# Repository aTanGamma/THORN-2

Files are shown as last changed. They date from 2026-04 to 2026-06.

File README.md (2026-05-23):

# aTan's THORN-2 RISC-V CPU Project

## What?

This is an implementation of the RISC-V spec using nothing but basic logic and
memory elements. 

The project has been inspired by several similar projects, most
notably [Robert Baruch's LMARV-1](https://www.youtube.com/playlist?list=PLEeZWGE3PwbansoxKjjMKHQqS_2cm8i60),
[James Sharman's JAM-1](https://www.youtube.com/playlist?list=PLFhc0MFC8MiCDOh3cGFji3qQfXziB9yOw)
and [Fabian Schuiki's Superscalar CPU](https://www.youtube.com/playlist?list=PLyR4neQXqQo5nPdEiMbaEJxWiy_UuyNN4).

As of May '26 I'm looking to implement the RV64I spec, with vague plans to 
extend this with the M and maybe F modules. I don't have any timeframe for that
though.

## Why?

IDK. It's fun :)

## That's mental... Where can I see the details?

If you go to `Docs/Writeup/` you can see a proper typewritten rundown on how
everything works and my "design process". There's quite a bit of techy stuff
there, and it's not _guaranteed_ to make sense - it's mostly a document to help
me keep track of what I'm doing between each section.

## Where are the schematics?

See `Schematics/`. This will be spotty for a while yet.

## Can I do anything with this project?

Please do! Though do read the license first. Broadly speaking, keep everything
open-source and don't be evil :)

## What happened to the THORN-1?

¬_¬ it went wrong...

In reality, it was the same as this project, but massively overcomplicated and
everything I learned there helped make this version much simpler. T1 used
pipelined ram for the registers, leading to a 4-phase clock and massive pain in
the ALU, so I abandoned it to start over.

-aTan 2026

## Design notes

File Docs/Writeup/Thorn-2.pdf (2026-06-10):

## THORN-2 Technical Referance Manual

aTan

May 30, 2026

Abstract

This document is a technical reference for the Thorn-2 (Stylised: Þ-2) computer. The Þ-2 is an RV64i compatable CPU and supporting system created largely from 74-series logic ships, with the goal of making a fully-pipelined system capable of very-high-speed execution. It also serves as a proof of [in]sanity for the creator.

1

### Contents

1 Introduction | 1
1.1 Pipelining | | 1
1.1.1 | Why and How Þ-2 Differs From Classic RISC | | 1
1.2 Hazard Avoidance | | 2
1.2.1 | Adding Stalls | | 2
1.2.2 | Operand Forwarding | | 3
2 Program Counter | 4
3 Decode Logic | 4
4 Immediate Value Generator | 4
5 Registers | | | 4
5.1 Theory of Operation | | 5
5.1.1 | Write Phase, φ1 | | | 5
5.1.2 | Read Phase: φ2 | | 6
5.1.3 | Output Buffers | | 7
5.2 Control Logic | | 8
6 ALU | | | 8
6.1 Adder | | 9
6.1.1 | Method | | 9
6.1.2 | Modified Carry-Lookahead | 10
6.1.3 | Doing the Adding | 11
6.1.4 | Condition Checking | 12
6.2 Logicer | 13
6.2.1 | Logic from MUXs | 14
6.2.2 | Setting up the MUX | 15
6.3 Shifter | 16
6.3.1 | Bit Order Reverser | 16
6.3.2 | Shift Stages | 16
References | | | 17
A Various Logic Expansions and Definitions | 18
A.1 Adder Conditions | 18

### List of Figures

1 | Execution flow through a pipelined ALU. In refers to line
number in code listing | | 4
2 | The Thorn-2 register file | | 6
| | i

3 | Register file timing diagram | | 7
4 | Layout of the adder circuit. Logic shared between similar
| signals combined for space | | 9
5 | Simplified overview of the adder logic | 10
6 | Diagram of the Logicer | 13
7 | Wiring of a 4:1 mux as used in the logic section | 14
8 | Diode ROM storing the truth table function, F0, F1, F2, F3;
| these are pulled up as the outputs of a 74x139 are active low. | 15

### List of Tables

1 | RISC-V calling convention | | 5
2 | Register Card control signal definitions | | 8
3 | Contents of the Condition RAM | 11
4 | Contents of the Carry RAM | 12
5 | ALU adder EEPROM contents | 12
6 | Formulae for ALU result conditons | 13
7 | Truth tables of the three defined logic operations | 14
8 | Comparison of the number of components used in designs
with (a) separate logic paths and (b) MUX-based logic . . . . 15

### Listings

1 | Some example code which denerates lots of stalls | | 2

ii

### 1 Introduction

Thorn-2 is a RISC-V CPU, designed to be fully compatable with the RV64i (integer only) standard module as defined in the RISC-V Instruction Set Architecture (RV-ISA) specification [1]. It is a fully-pipelined design with 5parallel stages (see §Pipelining) with hazard avoidance (§Hazard Avoidance) and operand forwarding (§Operand Forwarding).
This project has some fairly nebulous goals, but the general idea is to learn how CPUs work internally and make something interesting. They are here itemised:
- Implement a RISC-V CPU
- Utilise as few non-74 series chips as possible (no FPGA)
- Design the circuitry "by hand"
- Achieve ~40 MHz operation
- Have fun :3

Please don’t tell me I’m doing this inefficiently or that there article better ways to implement things - I’m well aware.

### 1.1 Pipelining

### 1.1.1 Why and How Þ-2 Differs From Classic RISC

The pipeline structure of Þ-2 differs from the traditional RISC one in that there are several more stages. These can be grouped into largely the same functional blocks, but spread across more stages; a setup reached after much design work on Thorn-1.
Classic RISC is split into five stages: Fetch, Decode, Execute, Memory and Writeback; with every instruction passing through each stage in turn (with the correct options set). In implementing this, I decided to use SRAM to store the 32 registers and to avoid using asynchronous SRAM. The latter decision was based on the false assumption that this would make the control circuitry easier to design and less error-prone. I maintained the Synchronous SRAM design for quite a while, getting as far as designing the whole control circuit for the registers and starting work on the ALU, but ran into problems with timings.
The SRAM ic I had chosen - IS61NLP6432a [2] - were themselves pipelined at three stages: Assert, wait, Read/Write. Each cycle of the CPU required three register accesses (two reads and a write), which was possible to achieve if each cycle was split into four phases, φ0, φ1, φ2, φ3. This imposed the requirement that every pipeline stage in the CPU must take

1

1 | ; Some silly code | :3c
2 | add a0 , a1 , a2 | ; Use a0 as tally
3 | add a0 , a0 , a3
4 | add a0 , a0 , a4
5 | add a0 , a0 , a5 | ; Add lots of numbers in turn
6 | ; ...

Listing 1: Some example code which denerates lots of stalls.

four cycles, which was insufficient for the ALU to perform a 64-bit addition and perform conditional inversion of the second operand for subtraction and check conditions. Thus, I decided to go back to the drawing board and start again.
The current design of Þ-2’s pipeline is based around the ALU, rather than the registers. I needed four stages to add numbers, plus two more to condition the inputs and outputs, giving six. Register accesses can be done in one step by using two copies of each register (a poor-man’s dual-port RAM) which are written to simultaniously on the rising edge of the clock; then separately read on the falling edge. Now using fast, asynchronous SRAM instead.

### 1.2 Hazard Avoidance

In a pipelined system, there are frequently situations where one instruction depends on the result of its predecessor. In such a case, this results in a Data Hazard - what is contained in register X is out of date, and reading this will produce incorrect results.
Another hazard comes in the case that a conditional branch is dependent on the outcome of a previous operation, resulting in a Control Hazard. The CPU must either stall new instructions while the condition is evaluated, or speculatively execute code for either the "branch" or "no branch" condition and throw it out if needed.

### 1.2.1 Adding Stalls

In either hazard case, the simplest - albeit least efficient - solution is to inject NO-OPs (NOPs) after the Decode stage and only continue when there are no remaining hazards. It is, however, trivial to come up with example programs which result in more nops than executed instructions:
When executing the above program, the CPU is forced to insert NOPs between every instruction to allow the addition result to be fully written back to a0 before the next instruction is executed. A classic RISC-V architecture with this simple hazard avoidance would actually execute the code in Listing 2.

2

7 | ;Oops , all stalls | TwT
8 | add a0 , a1 , a2 | ; Use a0 as tally
9 | nop | ; Execute in ALU
10 | nop | ; Skip memory access
11 | nop | ; Write result to a0
12 | add a0 , a0 , a3 | ; Next ADD is allowed to continue
13 | nop
14 | nop
15 | nop
16 | add a0 , a0 , a4
17 | nop | ; Each nop represents
18 | nop | ; | 1 stall cycle
19 | nop
20 | add a0 , a0 , a5 | ; Add lots of numbers in turn
21 | ; ...

Listing 2: Worst case scenario for consecutive adds.

This effectively quarters the useful throughput of the CPU in the worst case, though most of the time this isn’t likely to occur. Using this method, the number of NOPs scales linearly with the number of stages in the pipeline, so there is strong incentive to use a better system. Such a system should be able to feed data from one stage to another in order to skip some of the waiting.

### 1.2.2 Operand Forwarding

Operand Forwarding is one way to reduce the number of stall cycles introduced with a pipelined system. Here, in the case that an instruction needs data which has not yet been written to a register, but is available within the pipeline, that data can be fed forwards early so fewer stalls need to be introduced.
This method becomes very important the longer a pipeline becomes due to a greater number of cycles before the completion of each instruction: there is greater chance that a following instruction is dependent on a previous one and that data takes longer to become available.
Assuming the same code snipped as in §Adding Stalls, a perfect system of operand forwarding could reduce the number of NOPs to zero - i.e. what is written is executed exactly.
In Thorn-2 however, there is an additional complication which arises from the use of a pipelined ALU: the final result is made available in chunks across multiple stages or, should conditions need evaluation, only available after the final stage.
In fig. 1, each of the Add stages performs a 16-bit addition of each int16 chunk of the 64-bit inputs. If operand forwarding were to be used, the output

3

Invert? | Add 1 | Add 2 | Add 3 | Add 4 | Cond.
I2
I3 | I2
I4 | I3 | I2
I5 | I4 | I3 | I2
| I5 | I4 | I3 | I2
| | I5 | I4 | I3 | I2
| | | I5 | I4 | I3
| | | | I5 | I4
| | | | | I5

Figure 1: Execution flow through a pipelined ALU. In refers to line number in code listing.

of Add 1 would need to be fed back to its inputs for the next instruction. The same would be needed for each subsequent stage too. See §ALU for how this is actually done.

### 2 Program Counter

The PC’s job is (generally) to increment by 4 every clock cycle to fetch the next instruction in memory. On occasion, it will need to stall in place, load a provided value, or add a constant to its previous value to branch.
While outwardly simple, this is fairly complex to actually implement in 64 bits, expecially the branch operation which requires a 12-bit add, then a carry to propagate up the remaining bits. Since there could realistically be any arbitrary sequence of branches, jumps, normal increments or stalls, all of the separate branches need to be done in parallel and selected from at the very end.

### 3 Decode Logic

### 4 Immediate Value Generator

### 5 Registers

RV64i specifies 32 64-bit general-purpose registers and a program counter, PC. x0 is hard-wired to 0x0000 0000 0000 0000; there is no stack pointer. None of the registers are otherwise special, but do have expected uses as per the calling convention [3], shown in table 1.
As each register is effectively the same, they are most easily implemented using SRAM. Learning from Thorn-1, I have decided to use the

4

Table 1: RISC-V calling convention

Register | ABI
| Mnemonic | Meaning | Preserved across
| | | calls?
x0 | zero | Zero | — (Immutable)
x1 | ra | Return address | No
x2 | sp | Stack Pointer | Yes
x3 | gp | Global Pointer | — (Unallocatable)
x4 | tp | Thread Pointer | — (Unallocatable)
x5-7 | t0-2 | Temp. Registers | No
x8-9 | s0-s1 | Callee-saved regs. | Yes
x10-17 | a0-7 | Argument registers | No
x18-27 | s2-11 | Callee-saved regs. | Yes
x28-31 | t3-6 | Temp. Registers | No

IS61WV6416DBLL-10TLI-TR[4]; it’s a 64k x 16-bit asynchronous SRAM with a 10 ns access time and single 3.3 V supply.

### 5.1 Theory of Operation

For every RV64i operation, there are up to two operands, meaning up to two registers may be read each cycle. There may also be a value written into a register. To avoid using multiport RAM, two copies of the registers are needed: x and y; these two are both written to and read from at the same time. The IS61WV6416 is 16-bit, so there are two sets of four RAM chips total.
Both access to X and Y (Read/Write) occur within one cycle; writes are completed on the rising edge, φ1; and reads on the falling edge, φ2. This order of operations means the register card doesn’t need to latch its input, WB_DATA, or outputs, REG_OUT1 and REG_OUT2.
For the purposes of explanation, both RAM banks will be collectively referred to as "R". The logic is otherwise identical between X and Y, so either could be inserted in R’s place.

### 5.1.1 Write Phase, φ1

Register writes occur on the rising edge of the clock, φ1, and are controlled only by the external WRT signal. Regardless of whether a value is to be written to a register, the address for that ’write’ is selected. This setup helps to minimise control circuitry.

Write Enabled, WRT = 1 When WRT is high, WE goes low and puts the IS61WV6416 into a write cycle. R_BUS is driven to the value on

5

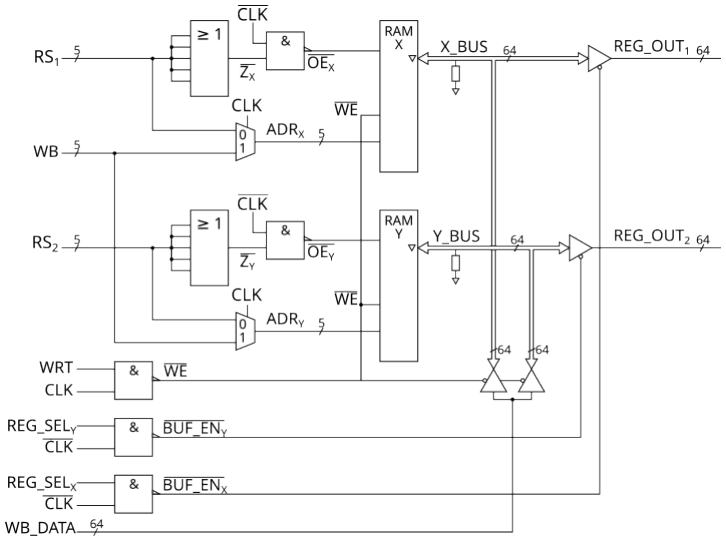
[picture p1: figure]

Figure 2: The Thorn-2 register file.

WB_DATA which is written into the selected register.

Write Disabled, WRT = 0 When WRT is low, WE remains high and the IS61WV6416s have their output disabled via OER. R_BUS is then passively pulled down to a value of 0x0000 0000 0000 0000.

### 5.1.2 Read Phase: φ2

Reads occur on the falling edge of the clock, φ2, and may give a real register value or a zero depending on the read address (see below). Regardless of whether an IS61WV6416s is actually read from, its address lines, ADRR, are set as if it was.

Not Reading From ’zero’, RSR 6= 0 When reading from any register other than x0, ZR will be high, setting OER low during φ2. R_BUS is thus driven to the contents of xR.

Reading From ’zero’, RSR = 0 When reading from x0, ZR goes low and, during φ2, OER stays high, again leaving R_BUS to be passively pulled to 0x0000 0000 0000 0000

6

### 5.1.3 Output Buffers

Since Þ-2 will be implementing operand forwarding, there are some instances where the input to the ALU isn’t necessarily from the register file. Therefore, the register file needs to be "selectable" by the CPU control logic. As such, the outputs of this section, REG_OUT1 and REG_OUT2 are connected to their respective buses via tri-state buffers.

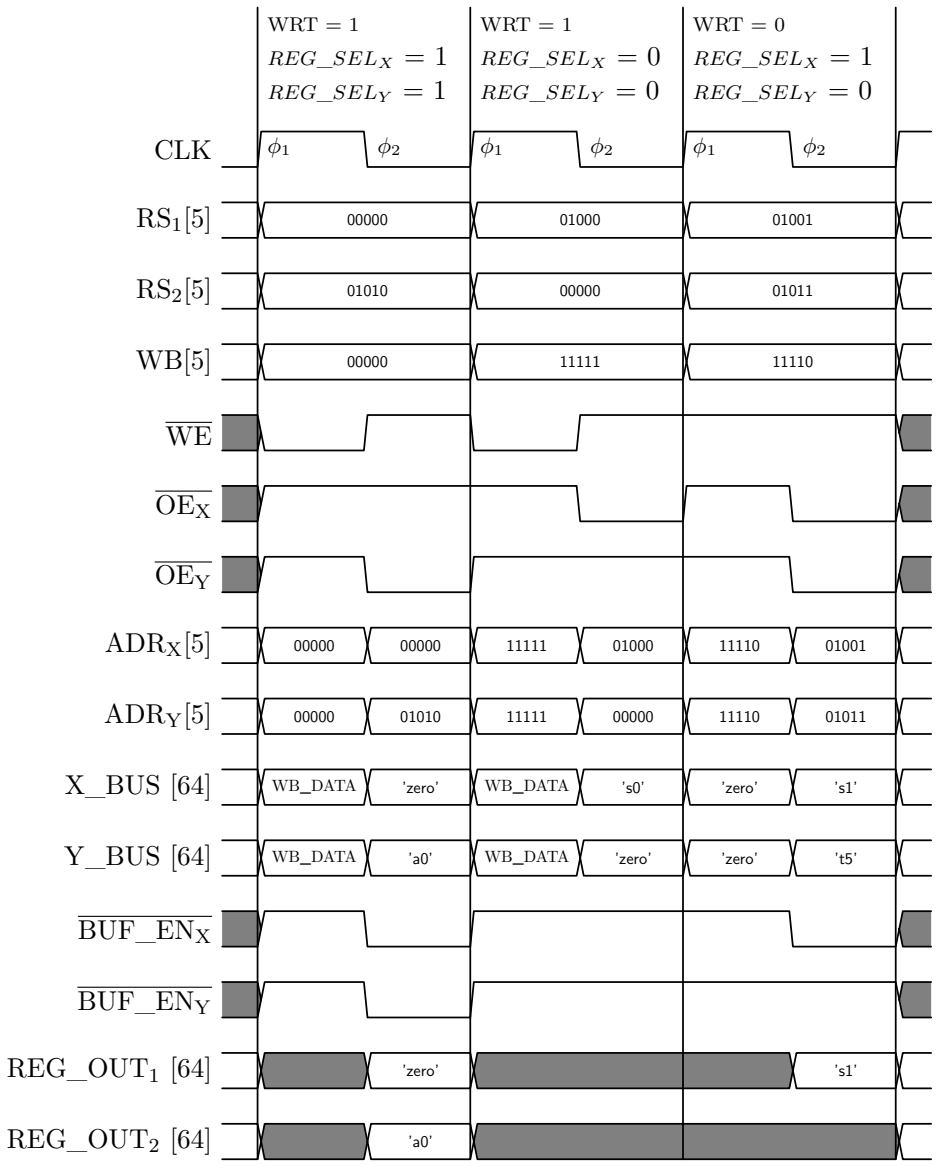
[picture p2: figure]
CLK; OEX; OEY; ADRX[5]; ADRY[5]; X_BUS [64]; WB_DATA; ’zero’; Y_BUS [64]; BUF_ENX; BUF_ENY; REG_OUT1 [64]; REG_OUT2 [64]; WRT = 1; REG_SELX = 1; REG_SELY = 1; REG_SELX = 0; REG_SELY = 0; WRT = 0

Figure 3: Register file timing diagram.

7

### 5.2 Control Logic

Figure 2 shows an overview of the register file. The control signals present are described in table 2.

Table 2: Register Card control signal definitions.

Signal | Equation | Explanation
CLK | — | Clock input
RS1 | — | Read address 1
RS2 | — | Read address 2
WB | — | Write address
WRT | — | Write enable
REG_SEL1 | — | Output X_BUS
REG_SEL2 | — | Output Y_BUS
WB_DATA — | Data to write this cycle

ZX

P4
| i=0 (RS1,i) | Not reading from ’zero’

ZY

P4
| i=0 (RS2,i)
OEX | ZX · CLK | RAM output enable
OEY | ZY · CLK
WE | CLK · WRT | Write enable signal
REG_OUT1 CLK · REG_SEL1 | Enable output to ALU

REG_OUT2 CLK · REG_SEL2

### 6 ALU

The Thorn-2ALU is comprised of three blocks - the Adder, Shifter and Logicer. The Adder computes A ± B; the Shifter shifts A up or down by n bits; and the Logic-er performs the bitwise logic operations A·B, A+B and A⊕B. The 64-bit values A and B may be read from registers or immediate values derived from an instruction. Each of the three blocks are contained on separate circuit boards, and run in parallel. Their outputs are calculated for all inputs with the relevant one forwarded to the next pipeline stage.

8

### 6.1 Adder

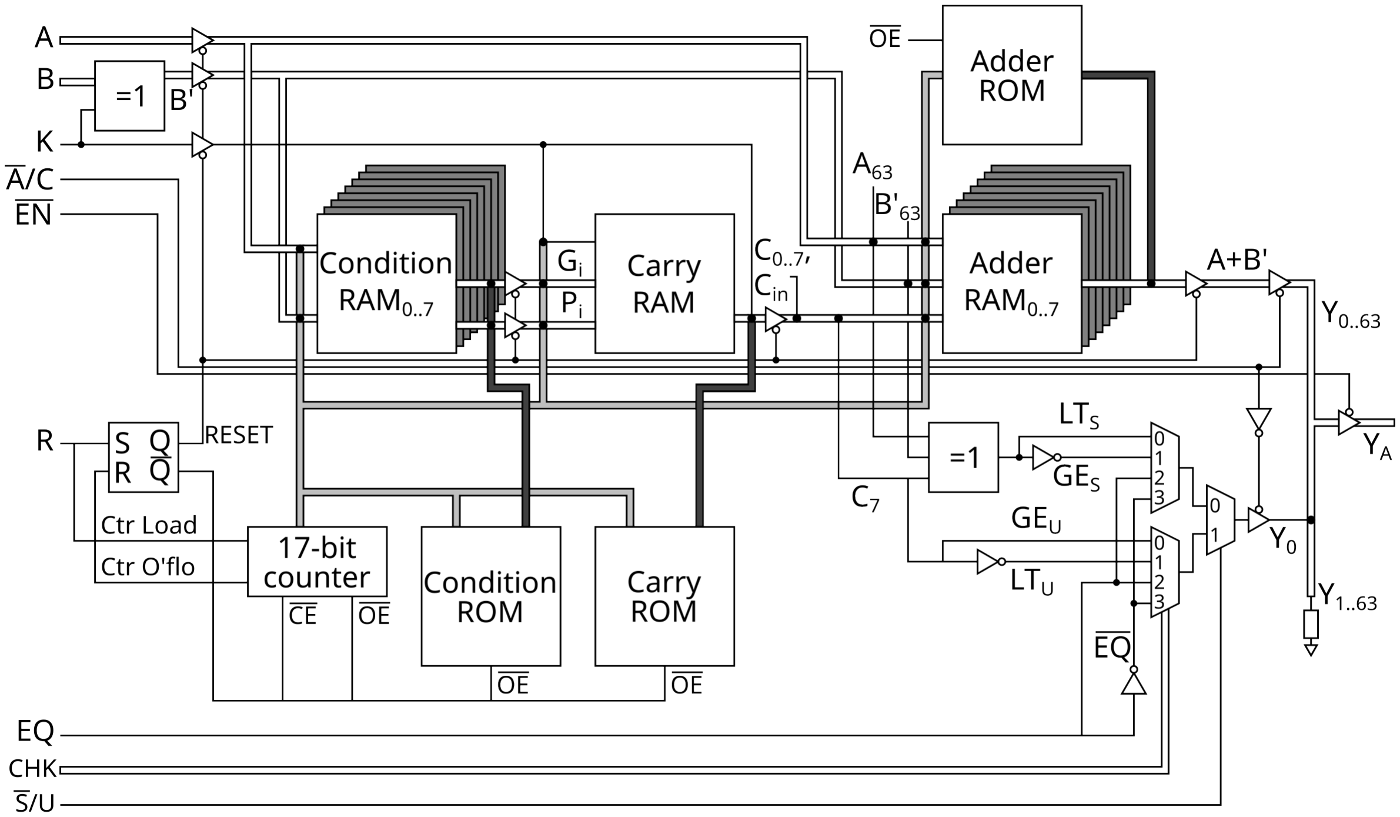
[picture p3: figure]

Figure 4: Layout of the adder circuit. Logic shared between similar signals combined for space.

The adder computes A±B and optionally checks the result against each of the "flags" for the calculation: A < B, A = B and A ≥ B. In Þ-1, this procedure was to be pipelined at up to six stages, but resulted in both huge pipelines and complications in feeding partial results back to previous stages, possibly from multiple instructions at multiple different points in their execution. In Þ-2, however, the entire ALU instead operates in one cycle - the length of this defining the overall cycle length of the CPU.
As you can see from fig. 4, the adder remains one of the most complex parts of the CPU, despite being only a third of the ALU. Using RAM with ~8 ns access time, this section has a critical path of ~50 ns through the zero check logic. This is markedly better than a more brute-force approach, though still limits the maximum clock frequency of ~20 MHz.

### 6.1.1 Method

Addition and subtraction are both done with the same circuitry, with a preconditioning step for the second input, B. Using 2’s compliment to represent negative numbers, an n-bit number, x, can be negated by inverting its bits and adding 1:

−x := (x ⊕ [2n − 1]) + 1 | (1)

9

Subtracting B from A is therefore defined:

A − B ≡ A + (−B) ≡ A + (B ⊕ [2n − 1]) + 1 | (2)

Equation (2) is implemented by bitwise XORing B with the ADD/SUB setting, K , and setting the carry input, Cin to the same:

K =

(
0 if Adding
1 if Subtracting

(3)

A − B ≡ A + (B ⊕ K) + K | (4)

The XORed B will be called B⁰
from here.
The addition, A + B⁰ + K is a 64-bit operation which would be much too slow if performed as a series of daisy-chained segments due to the access time of the RAM ICs. Even in the best case - where the access time were ≤ 8 ns - a chain of eight in a row would be a total delay of ≤ 64 ns, greatly bottlenecking the speed of the processor. A form of carry-lookahead is therefore used to reduce this delay.

### 6.1.2 Modified Carry-Lookahead

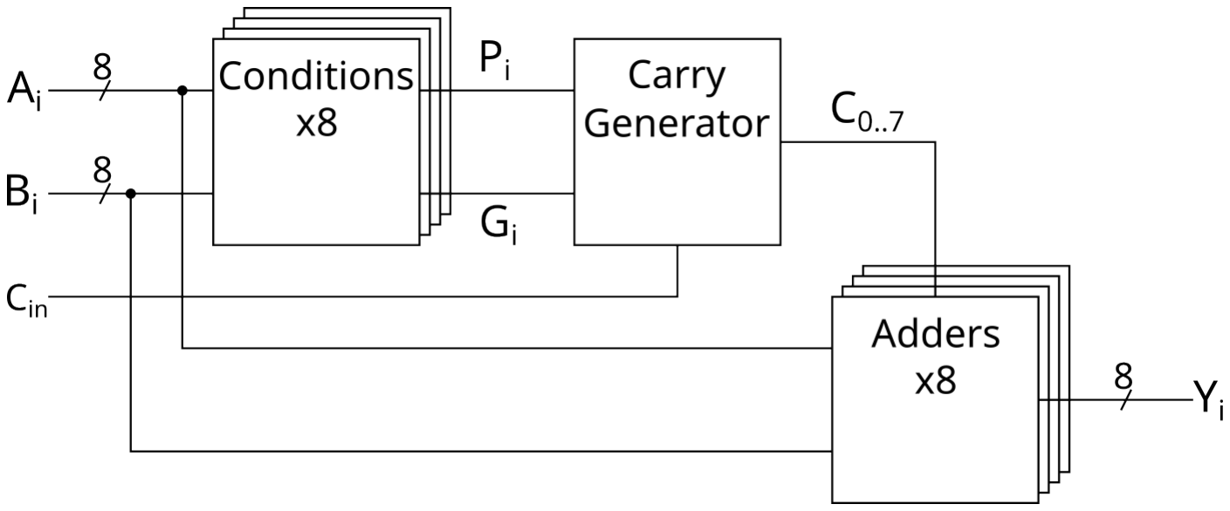
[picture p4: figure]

Figure 5: Simplified overview of the adder logic.

A traditional carry-lookahead circuit generates the carry signals from chunks of the inputs, ideally much faster than the same signal would be propagated up a chain of full adders. To do this, additional signals are generated or tapped from the full adder circuits:

Xn = An · Bn | (5)
Sn = An ⊕ Bn | (6)

10

These additional signals are then used to calculate whether the n-bit chunk generates, G, or propagates, P, a carry.

G = (Xn) + (Xn−1 · Sn) + · · · +

X0 ·

Yn

i=1

(Si)

!
(7)

P =

Yn

i=0

(Si) | (8)

A single 64Kx8 RAM chip is used as a lookup table for G and P, both of which are forwarded to another 128Kx8 RAM that generates the carry signals C0..7.
For n = 0:
C0 = G0 + Cin · P0 | (9)

For 1 ≤ n < 8:

Cn = Gn +

Xn

i=1

Gn−i

·

Y

i−1

j=0

(Pn−j )

- + Cin ·

Y

N

(Pn) | (10)

See §Adder Conditions for expanded definitions.
Using this method, all eight carrys can be generated after only two RAM accesses. Cin and C0..6 are used in the calculation while C7 is used only for condition checking.

Table 3: Contents of the Condition RAM

An | Bn | Address | Gn | Pn
0x00 | 0x00 | 0x0000 | 0 | 0
0x00 | 0x01 | 0x0001 | 0 | 0
0x00 | 0xFF | 0x00FF | 0 | 1
0x01 | 0x00 | 0x0100 | 0 | 0
0x01 | 0xFE | 0x01FE | 0 | 1
0x01 | 0xFF | 0x01FF | 1 | 0
0xFF | 0xFF | 0xFFFF | 1 | 0

### 6.1.3 Doing the Adding

The addition itself is "executed" in eight 128Kx8 RAM chips, each programmed at start-up from a single 128Kx8 EEPROM. The RAM is ad-

11

Table 4: Contents of the Carry RAM

Gn | Pn | Cin | Address | C
00000000 | 00000000 | 0 | 0x00000 | 00000000
00000000 | 00000001 | 0 | 0x00001 | 00000000
00000000 | 11111111 | 0 | 0x000FF | 00000000
00000001 | 00000000 | 0 | 0x00100 | 00000001
00000001 | 00000001 | 0 | 0x00101 | 00000001
00000001 | 00000010 | 0 | 0x00102 | 00000011
11111111 | 11111111 | 0 | 0x0FFFF | 11111111
00000000 | 00000000 | 1 | 0x10000 | 00000000
00000000 | 00000001 | 1 | 0x10001 | 00000001
11111111 | 11111111 | 1 | 0x1FFFF | 11111111

dressed by each byte of the two inputs, An and Bn, and Cn, which points to the result, Yn.

Table 5: ALU adder EEPROM contents

An | Bn | Cn | Address | Yn
0x00 | 0x00 | 0 | 0x00000 | 0x00
0x00 | 0x01 | 0 | 0x00001 | 0x01
0x01 | 0x00 | 0 | 0x00100 | 0x01
0x00 | 0x00 | 1 | 0x10000 | 0x01
0xFF | 0xFE | 1 | 0x1FFFE | 0xFE
0xFF | 0xFF | 1 | 0x1FFFF | 0xFF

The final result is then either forwarded to the Adder’s output, or changed to 0/1 for the outcome of the SLT/SLTU instructions.
In the case of ADDW/SUBW instructions which sign-extend a 32-bit answer to 64, the upper word is ignored and switched to Y[31].

### 6.1.4 Condition Checking

The RISC-V ALU needs to be able to check for three conditions for both signed and unsigned numbers: A < B, A = B and A ≥ B. These are only

12 valid if the calculation A − B was performed. These checks can be performed immediately after the final carry out has been calculated using the equations in table 6.

Table 6: Formulae for ALU result conditons

Condition | Name | Signed | Unsigned
A < B | LT | A63 ⊕ B63 ⊕ C7 | C7
A = B | EQ | Y = 0 | Y = 0
A ≥ B | GE | A < BS | C7

The greater/less than checks are calculated as written, but the equality check is actually calculated using the formula:

EQ =

X

63

i=0

(Ai ⊕ Bi) | (11)

In plain english: A and B are equal if A ⊕ B = 0, which is checked in the Logicer by ORing together all the bits of that result.
The results of the condition check are also forwarded to the program counter to deal with branches.

### 6.2 Logicer

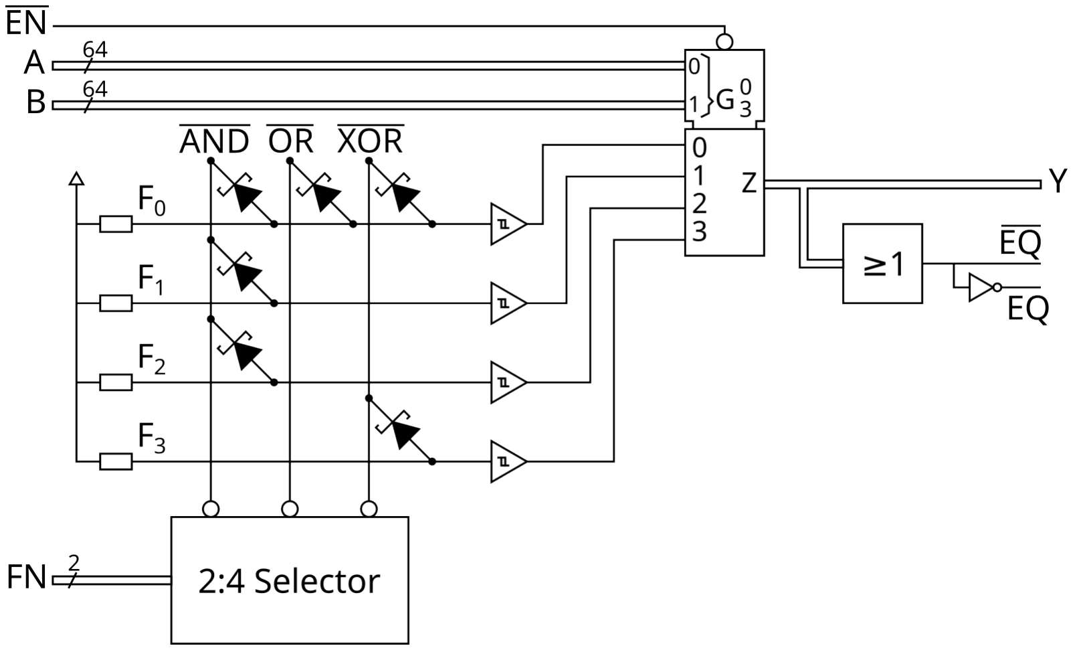
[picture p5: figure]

Figure 6: Diagram of the Logicer.

13

RISC-V specifies three bitwise logic operations: AND, OR and XOR. The obvious way to do this (74x08 for AND, 74x32 for OR, and 74x86 for XOR), takes 48 chips, plus some extra to choose which answer we want
- quite a high number considering what this section does. This can be improved using a slightly more complex setup.
The final output, Y, is sent to a tri-state buffer/line driver which is only enabled when the ALU performs a logic operation.

### 6.2.1 Logic from MUXs

It is possible to construct any 2-input, 1-output logic function from a 4:1 MUX where the four inputs reflect the truth table of the function, and the select lines are the two inputs of the function.
Constructing the logic section this way means the control logic for this section is limited to a small ROM containing the truth tables for the MUXs.

Table 7: Truth tables of the three defined logic operations

A | B | A · B
0 | 0 | 0
0 | 1 | 0
1 | 0 | 0
1 | 1 | 1
(a) AND truth table
A | B | A+B
0 | 0 | 0
0 | 1 | 1
1 | 0 | 1
1 | 1 | 1
(b) OR truth table
A | B | A⊕B
0 | 0 | 0
0 | 1 | 1
1 | 0 | 1
1 | 1 | 0
(c) XOR truth table

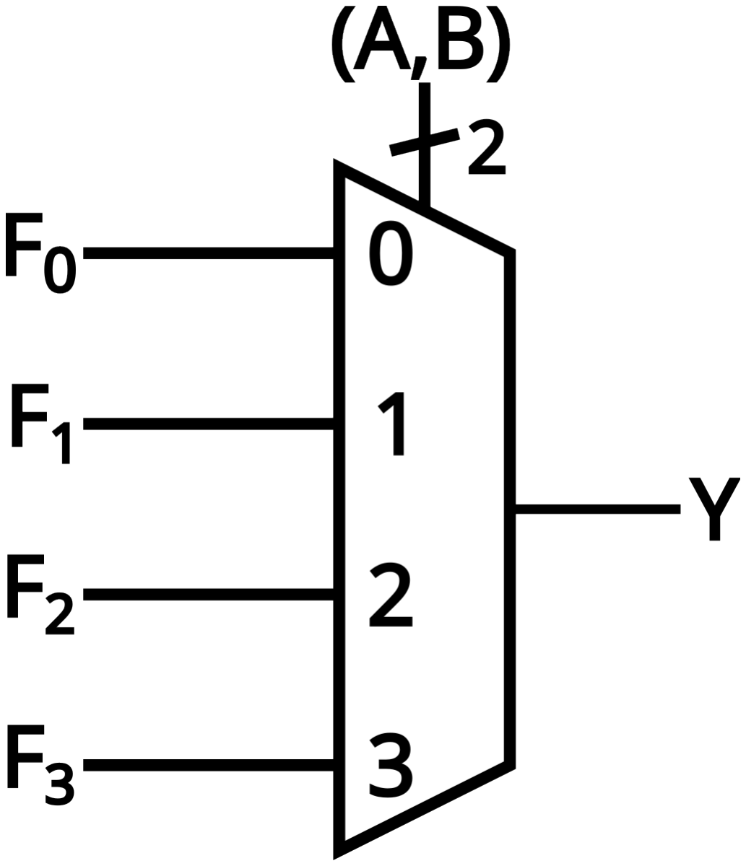
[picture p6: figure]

Figure 7: Wiring of a 4:1 mux as used in the logic section.

This method is preferable when considering the number of ICs used:

14

Table 8: Comparison of the number of components used in designs with (a) separate logic paths and (b) MUX-based logic

Section | #Gates | #ICs
AND | 64 | 16
OR | 64 | 16
XOR | 64 | 16
4:1 MUX | 64 | 32
Total | 256 | 80
(a) Using discreet logic gates
Section | #Parts | #ICs
ROM Select | 1 | 1
ROM Diodes | 6 | —
ROM Buffers | 12 | 2
4:1 MUX | 64 | 32
Total | 75 | 35
(b) Using MUXs

### 6.2.2 Setting up the MUX

The correct truth table is selected using a 2:4 selector which is wired to a small, diode matrix (fig. 8). A 74x1G139 2:4 takes the two-bit function select and the desired bits are set from F0, F1, F2, F3, which are then buffered before being sent out to the MUXs. The unused decoder output is left unused and unconnected to the matrix, resulting in a ’function’ returning [1,1,1,1].

VCC | AND | OR | XOR

F0

F1

F2

F3

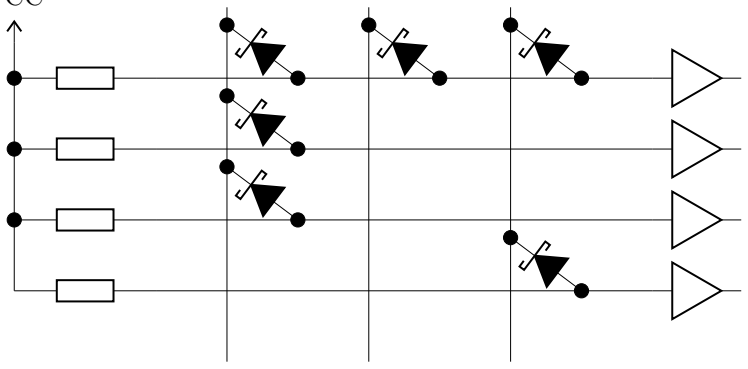
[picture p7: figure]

Figure 8: Diode ROM storing the truth table function, F0, F1, F2, F3; these are pulled up as the outputs of a 74x139 are active low.

The buffers in fig. 8 serve two purposes: firstly they help with fanout -there are 64 inputs per Function line and, for a 4.7kΩ resistor, each can get ~0.7mA (this isn’t too low for LVC logic, but I would like more headroom); and secondly, they smooth over any issues the diodes may cause.
As there are 64 total MUXs needed for the logic functions, the Function lines are buffered four times in parallel so each buffer only needs to drive 16 inputs. The buffers themselves serve two purposes: first to provide enough current to drive all 64 MUXs and second to amplify the Fi signals to counter

15 the voltage drop from the diodes. With a forward voltage of ~0.3 V; this drops the nominal signal level to 3.0 V, only 0.6 V above the minimum Vih of low-voltage CMOS logic chips.

### 6.3 Shifter

The RISC-V ISA defines several shift operations, each of which can, in one operation, shift the input by an arbitrary number of bits up to X_LEN-1. In RV64i, additional instructions shift 32-bit values and sign extend up to 64-bits. Both left and right shifts are defined, with left shifts being implemented by reversing the input, shifting, then reversing the result again:

A >> B := REV( REV(A) << B ) | (12)

This implementation favours left shifts, so any rightward shift will use the method in eq. (12).
Shifts are implemented using a sequential barrel shifter - a series of stages which shift the input a power of two number of places up to 32. Each stage consists of two tri-state buffers, one buffering the previous stage as is, the other buffering the previous output shifted by the next number of bits. The n

th stage is then controlled by the n

th bit of the shift amount input. Traditionally, a sequential barrel shifter like this would use multiplexers, but this requires far too many (384 MUXs across 96 ICs) to be practical. The modified version using buffers comes from R. Baruch’s RISC-V build [5], expanded to 64-bits.
Using 16-bit buffers in the 74LVC162244, the number of ICs can be reduced to 8 per stage, for a total of 48 - half that of the MUX version.

### 6.3.1 Bit Order Reverser

In order to shift the incoming number, A, rightwards, it must be bit-reversed first. This is accomplished using two tri-state buffers, one buffering the number as is, the other buffering the reversed number.
The reversal is accomplished by "simple" shuffling of the order of traces on the PCB in the following way:
[DIAGRAM OF PCB TRACE REVERSAL]

### 6.3.2 Shift Stages

16

### References

[1] A. Waterman and K. Asanovi, Eds., The risc-v instruction set manual, volume i: User-level isa, document version 20191214-draft, RISC-V Foundation, Dec. 2019. [Online]. Available: https://docs.riscv.org/reference/isa/unpriv/unpriv-index.html. (https://docs.riscv.org/reference/isa/unpriv/unpriv-index.html)
[2] I. Integrated Silicon Solution, Is61nlp6432 ... 64k x 32 ... 2mb, pipeline ’no wait’ state bus sram, Aug. 2005. [Online]. Available: https://www.mouser.co.uk/datasheet/3/3722/1/61NLP_NVP6436A_12818A.pdf.
[3] K. Cheng and J. Clarke, Eds., Risc-v abis specification, document version november 26, 2025-draft, RISC-V International, Nov. 2025. [Online]. Available: https://riscv-non-isa.github.io/riscv-elfpsabi-doc/. (https://riscv-non-isa.github.io/riscv-elf-psabi-doc/)
[4] I. Integrated Silicon Solution, 64k x 16 high speed asynchronous cmos static ram, Mar. 2020. [Online]. Available: https://www.mouser.co.uk/datasheet/3/3722/1/61_64WV6416DAxx_DBxx.pdf. (https://www.mouser.co.uk/datasheet/3/3722/1/61_64WV6416DAxx_DBxx.pdf)
[5] R. Baruch, Lmarv-1 (tangible risc-v) part 4.1: Designing the shifter, YouTube Video, Jul. 2018. [Online]. Available: https://www.youtube.com/watch?v=SuUChAF3gaw. (https://www.youtube.com/watch?v=SuUChAF3gaw)

17

### A Various Logic Expansions and Definitions

A.1 Adder Conditions

Does the n

| th stage propagate a carry?
P0 = S0,0 · S0,1 · S0,2 · S0,3 · S0,4 · S0,5 · S0,6 · S0,7 | (13)
P1 = S1,0 · S1,1 · S1,2 · S1,3 · S1,4 · S1,5 · S1,6 · S1,7 | (14)
P2 = S2,0 · S2,1 · S2,2 · S2,3 · S2,4 · S2,5 · S2,6 · S2,7 | (15)
P3 = S3,0 · S3,1 · S3,2 · S3,3 · S3,4 · S3,5 · S3,6 · S3,7 | (16)
P4 = S4,0 · S4,1 · S4,2 · S4,3 · S4,4 · S4,5 · S4,6 · S4,7 | (17)
P5 = S5,0 · S5,1 · S5,2 · S5,3 · S5,4 · S5,5 · S5,6 · S5,7 | (18)
P6 = S6,0 · S6,1 · S6,2 · S6,3 · S6,4 · S6,5 · S6,6 · S6,7 | (19)
P7 = S7,0 · S7,1 · S7,2 · S7,3 · S7,4 · S7,5 · S7,6 · S7,7 | (20)

Does the n

th stage generate a carry?

G0 = X0 + P0Cin | (21)
G1 = X1 + P1C0 + P1P0Cin | (22)
G2 = X2 + P2C1 + P2P1C0 + P2P1P0Cin | (23)
G3 = X3 + P3C2 + P3P2C1 + P3P2P1C0 + P3P2P1P0Cin | (24)
G4 = X4 + P4(C3 + P3(C2 + P2(C1 + P1(C0 + P0Cin)))) | (25)
G5 = X5 + P5(C4 + P4(C3 + P3(C2 + P2(C1 + P1(C0 + P0Cin))))) | (26)
G6 = X6 + P6(C5 + P5(C4 + P4(C3 + P3(C2 + P2(C1 + P1(C0 + P0Cin)))))) | (27)
G7 = X7 + P7(C6 + P6(C5 + P5(C4 + P4(C3 + P3(C2 + P2(C1 + P1(C0 + P0Cin))))))) | (28)

What is the n

th stage’s carry in?

C0 = Cin | (29)
C1 = G0 + P0Cin | (30)
C2 = G1 + P1G0 + P1P0Cin | (31)
C3 = G2 + P2G1 + P2P1G0 + P2P1P0Cin | (32)
C4 = G3 + P3G2 + P3P2G1 + P3P2P1G0 + P3P2P1P0Cin | (33)
C5 = G4 + P4(G3 + P3(G2 + P2(G1 + P1(G0 + P0Cin)))) | (34)
C6 = G5 + P5(G4 + P4(G3 + P3(G2 + P2(G1 + P1(G0 + P0Cin))))) | (35)
C7 = G6 + P6(G5 + P5(G4 + P4(G3 + P3(G2 + P2(G1 + P1(G0 + P0Cin)))))) | (36)

Cout = G7 + P7(G6 + P6(G5 + P5(G4 + P4(G3 + P3(G2 + P2(G1 + P1(G0 + P0Cin))))))) (37)

18

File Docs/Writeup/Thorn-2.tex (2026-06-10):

\documentclass[a4paper, 11pt]{article}

\usepackage[T1]{fontenc}

\usepackage[hidelinks]{hyperref}
    \hypersetup{
        pdftitle={THORN-2 Technical Referance Manual},
        pdfauthor={aTan}
        }

\usepackage{svg}
\usepackage{graphicx}
\usepackage{capt-of}

\usepackage{amsmath}
\usepackage{cleveref}
\usepackage[table]{xcolor}
\usepackage{tabularx}
\usepackage{hhline}
\usepackage{listings}
\usepackage{booktabs}
\usepackage{enumitem}
\usepackage{subcaption}
\usepackage{circuitikz}

% Taken from https://gist.github.com/AntonLydike/e339c3c3a4dcab8bc3c620b3fa436cda
% Modified for comment font and to remove additional register definitions
\lstdefinelanguage[RISC-V]{Assembler}
{
alsoletter={.}, % allow dots in keywords
alsodigit={0x}, % hex numbers are numbers too!
morekeywords=[1]{ % instructions
    lb, lh, lw, lbu, lhu,
    sb, sh, sw,
    sll, slli, srl, srli, sra, srai,
    add, addi, sub, lui, auipc,
    xor, xori, or, ori, and, andi,
    slt, slti, sltu, sltiu,
    beq, bne, blt, bge, bltu, bgeu,
    j, jr, jal, jalr, ret,
    scall, break, nop
},
morekeywords=[2]{ % sections of our code and other directives
    .align, .ascii, .asciiz, .byte, .data, .double, .extern,
    .float, .globl, .half, .kdata, .ktext, .set, .space, .text, .word
},
morekeywords=[3]{ % registers
    zero, ra, sp, gp, tp, s0, fp,
    t0, t1, t2, t3, t4, t5, t6,
    s1, s2, s3, s4, s5, s6, s7, s8, s9, s10, s11,
    a0, a1, a2, a3, a4, a5, a6, a7,
},
morecomment=[l]{;},   % mark ; as line comment start
morecomment=[l]{\#},  % as well as # (even though it is unconventional)
morestring=[b]",      % mark " as string start/end
morestring=[b]'       % also mark ' as string start/end
}
\definecolor{mauve}{rgb}{0.58,0,0.82}
\lstset{
    numbers = left,
    basicstyle=\small\ttfamily,                   % very small code
    breaklines=true,                              % break long lines
    commentstyle=\small\color{green!50!black},    % comments are green
    keywordstyle=[1]\color{blue!80!black},        % instructions are blue
    keywordstyle=[2]\color{orange!80!black},      % sections/other directives are orange
    keywordstyle=[3]\color{red!50!black},         % registers are red
    stringstyle=\color{mauve},                    % strings are from the telekom
    identifierstyle=\color{teal},                 % user declared addresses are teal
    frame=l,                                      % black line on the left side of code
    language=[RISC-V]Assembler,                   % all code is RISC-V
    tabsize=4,                                    % indent tabs with 4 spaces
    showstringspaces=false                        % do not replace spaces with weird underlines
}

\usepackage[backend=biber, style=ieee]{biblatex}
    \addbibresource{./Bibs/Sources.bib}

\usepackage{tikz}

\usepackage{tikz-timing}
    \usetikztiminglibrary{advnodes}

\title{THORN-2 Technical Referance Manual}
\author{aTan}

\emergencystretch=1em

\begin{document}

    %Commands to print OLD formatted logos
    \newcommand{\oldlonglogo}{\textit{Thorn}-1}
    \newcommand{\oldlogo}{\textit{\TH}-1}

    %Commands to print formatted logos
    \newcommand{\longlogo}{\textit{Thorn}-2}
    \newcommand{\logo}{\textit{\TH}-2}
    \newcommand{\linksection}[1]{\hyperref[#1]{\S \nameref*{#1}}}

    %Defines the number of stages in the pipeline for easy changing
    \newcommand{\pipestages}{5}

    \newcommand{\ramshort}{IS61WV6416}
    \newcommand{\ramname}{IS61WV6416DBLL-10TLI-TR}

    \newcommand{\clkfreq}{40 MHz}
    \newcommand{\clktime}{25 ns}

    \begin{titlepage}
        \maketitle
        \thispagestyle{empty}   %Hide pagenumber on titlepage
    \end{titlepage}

    \begin{abstract}
        This document is a technical reference for the \longlogo\ (Stylised: \logo)
            computer. The \logo\ is an RV64i compatable CPU and supporting system
            created largely from 74-series logic ships, with the goal of making a
            fully-pipelined system capable of very-high-speed execution.
            It also serves as a proof of [in]sanity for the creator.
    \end{abstract}
    \newpage

    \pagenumbering{roman}
    \tableofcontents
    \listoffigures
    \listoftables
    \lstlistoflistings
    \newpage

    \pagenumbering{arabic}
    \section{Introduction}\label{sec:Introduction}
        \longlogo\ is a RISC-V CPU, designed to be fully compatable with the 
        RV64i (integer only) standard module as defined in the RISC-V 
        Instruction Set Architecture (RV-ISA) specification \cite{RVISA}. 
        It is a fully-pipelined design with \pipestages parallel stages
        (see \linksection{sec:Intro:Pipeline}) with hazard avoidance 
        (\linksection{sec:Intro:HazAvoid}) and operand forwarding 
        (\linksection{sec:Intro:OpFwd}).

        This project has some fairly nebulous goals, but the general idea is
        to learn how CPUs work internally and make something interesting.
        They are here itemised:

        \begin{itemize}
            \item Implement a RISC-V CPU
            \item Utilise as few non-74 series chips as possible (no FPGA)
            \item Design the circuitry "by hand"
            \item Achieve \textasciitilde 40 MHz operation
            \item Have fun :3
        \end{itemize}

        Please don't tell me I'm doing this inefficiently or that there article
        better ways to implement things - I'm well aware.

        \subsection{Pipelining}\label{sec:Intro:Pipeline}

            \subsubsection{Why and How \logo\ Differs From Classic RISC}

            The pipeline structure of \logo\ differs from the traditional RISC
            one in that there are several more stages. These can be grouped
            into largely the same functional blocks, but spread across more
            stages; a setup reached after much design work on \oldlonglogo.

            Classic RISC is split into five stages: Fetch, Decode, Execute, Memory
            and Writeback; with every instruction passing through each stage
            in turn (with the correct options set). 
            In implementing this, I decided to use SRAM to store the 32 registers 
            and to avoid using asynchronous SRAM. 
            The latter decision was based on the false assumption that this 
            would make the control circuitry easier to design and less error-prone.
            I maintained the Synchronous SRAM design for quite a while, getting
            as far as designing the whole control circuit for the registers
            and starting work on the ALU, but ran into problems with timings.

            The SRAM ic I had chosen - IS61NLP6432a \cite{IS61NLP6432a} - were
            themselves pipelined at three stages: 
            Assert, wait, Read/Write.
            Each cycle of the CPU required three register accesses
            (two reads and a write), which was possible to achieve if each
            cycle was split into four phases, $\phi_{0}, \phi_{1}, \phi_{2},
            \phi_{3}$. 
            This imposed the requirement that every pipeline stage in the CPU 
            must take four cycles, which was insufficient for the ALU to 
            perform a 64-bit addition \emph{and} perform conditional inversion 
            of the second operand for subtraction and check conditions. 
            Thus, I decided to go back to the drawing board and start again.

            The current design of \logo's pipeline is based around the ALU,
            rather than the registers. 
            I needed four stages to add numbers, plus two more to condition the 
            inputs and outputs, giving six.
            Register accesses can be done in one step by using two copies
            of each register (a poor-man's dual-port RAM) which are written
            to simultaniously on the rising edge of the clock; then
            separately read on the falling edge. Now using fast,
            \emph{asynchronous} SRAM instead.

        \subsection{Hazard Avoidance}\label{sec:Intro:HazAvoid}

            In a pipelined system, there are frequently situations where one
            instruction depends on the result of its predecessor. 
            In such a case, this results in a \textbf{Data Hazard} - what 
            is contained in register X is out of date, and reading this will 
            produce incorrect results.

            Another hazard comes in the case that a conditional branch is dependent
            on the outcome of a previous operation, resulting in a
            \textbf{Control Hazard}. 
            The CPU must either stall new instructions while the condition is 
            evaluated, or speculatively execute code for either the "branch" 
            or "no branch" condition and throw it out if needed.

            \subsubsection{Adding Stalls}\label{sec:Intro:HazAvoid:Stalls}

                In either hazard case, the simplest - albeit least efficient -
                solution is to inject NO-OPs (NOPs) after the Decode stage
                and only continue when there are no remaining hazards.
                It is, however, trivial to come up with example programs which
                result in more nops than executed instructions:

                \begin{lstlisting}[
                    label={lst:Intro:HazAvoid:Stalls:BadCode},
                    caption={Some example code which denerates lots of stalls.},
                    captionpos=b,
                    language={[RISC-V]Assembler}, 
                    frame=single,
                    float,
                ][htb!]
;Some silly code  :3c
add a0, a1, a2  ;Use a0 as tally
add a0, a0, a3
add a0, a0, a4
add a0, a0, a5  ;Add lots of numbers in turn
;...
                \end{lstlisting}

                When executing the above program, the CPU is forced to insert 
                NOPs between every instruction to allow the addition result to 
                be fully written back to 
                \lstinline[language={[RISC-V]Assembler}]|a0| before the next 
                instruction is executed. 
                A classic RISC-V architecture with this simple hazard avoidance 
                would \emph{actually} execute the code in Listing 
                \ref{lst:Intro:HazAvoid:Stalls:ManyNOPs}.

                \begin{lstlisting}[
                        label={lst:Intro:HazAvoid:Stalls:ManyNOPs},
                        caption={Worst case scenario for consecutive adds.},
                        captionpos=b,
                        language={[RISC-V]Assembler},
                        frame=single,
                        float
                    ][htb!]
;Oops, all stalls  TwT
add a0, a1, a2  ;Use a0 as tally
nop             ;Execute in ALU
nop             ;Skip memory access
nop             ;Write result to a0
add a0, a0, a3  ;Next ADD is allowed to continue
nop
nop
nop
add a0, a0, a4
nop             ;Each nop represents
nop             ;   1 stall cycle
nop
add a0, a0, a5  ;Add lots of numbers in turn
;...
                \end{lstlisting}

                This effectively quarters the useful throughput of the CPU in 
                the worst case, though most of the time this isn't likely to 
                occur.
                Using this method, the number of NOPs scales linearly with the
                number of stages in the pipeline, so there is strong incentive
                to use a better system. 
                Such a system should be able to feed data from one stage to 
                another in order to skip some of the waiting.

            \subsubsection{Operand Forwarding}\label{sec:Intro:OpFwd}

                \textbf{Operand Forwarding} is one way to reduce the number of 
                stall cycles introduced with a pipelined system. 
                Here, in the case that an instruction needs data which has not 
                yet been written to a register, but \emph{is available within 
                the pipeline}, that data can be fed forwards early so fewer 
                stalls need to be introduced.

                This method becomes very important the longer a pipeline becomes 
                due to a greater number of cycles before the completion of each
                instruction: there is greater chance that a following instruction
                is dependent on a previous one \emph{and} that data takes longer
                to become available.

                Assuming the same code snipped as in
                \linksection{sec:Intro:HazAvoid:Stalls}, a perfect system of
                operand forwarding could reduce the number of NOPs to zero
                - i.e. what is written is executed exactly.

                In \longlogo\ however, there is an additional complication which 
                arises from the use of a pipelined ALU: the final result is made 
                available in chunks across multiple stages or, should conditions 
                need evaluation, only available after the final stage.

                %Consecutive adds thru piped ALU
                \begin{figure}
                    \centering

                    \begin{tabularx}{\textwidth}{
                        |>{\centering\arraybackslash}X
                        |>{\centering\arraybackslash}X
                        |>{\centering\arraybackslash}X
                        |>{\centering\arraybackslash}X
                        |>{\centering\arraybackslash}X
                        |>{\centering\arraybackslash}X
                        |
                        }

                        \hhline{------}
                        Invert? &Add 1  &Add 2  &Add 3  &Add 4  &Cond.  \\
                        \hhline{|-|-|-|-|-|-|}

                        \rowcolor{lightgray}
                        \cellcolor{violet!50!white}I2   &   &   &   &   &   \\  \hhline{|-|-|-|-|-|-|}

                        \rowcolor{lightgray}
                        \cellcolor{violet!20!white}I3   &\cellcolor{violet!50!white}I2 &   &   &   &   \\  \hhline{|-|-|-|-|-|-|}

                        \rowcolor{lightgray}
                        \cellcolor{green!20!white}I4    &\cellcolor{violet!20!white}I3 &\cellcolor{violet!50!white}I2 &   &   &   \\  \hhline{|-|-|-|-|-|-|}

                        \rowcolor{lightgray}
                        \cellcolor{green!50!white}I5    &\cellcolor{green!20!white}I4 &\cellcolor{violet!20!white}I3 &\cellcolor{violet!50!white}I2 &   &   \\  \hhline{|-|-|-|-|-|-|}

                        \rowcolor{lightgray}
                            &\cellcolor{green!50!white}I5 &\cellcolor{green!20!white}I4 &\cellcolor{violet!20!white}I3 &\cellcolor{violet!50!white}I2 &   \\  \hhline{|-|-|-|-|-|-|}

                        \rowcolor{lightgray}
                            &   &\cellcolor{green!50!white}I5 &\cellcolor{green!20!white}I4 &\cellcolor{violet!20!white}I3 &\cellcolor{violet!50!white}I2 \\  \hhline{|-|-|-|-|-|-|}

                        \rowcolor{lightgray}
                            &   &   &\cellcolor{green!50!white}I5 &\cellcolor{green!20!white}I4 &\cellcolor{violet!20!white}I3 \\  \hhline{|-|-|-|-|-|-|}

                        \rowcolor{lightgray}
                            &   &   &   &\cellcolor{green!50!white}I5 &\cellcolor{green!20!white}I4 \\  \hhline{|-|-|-|-|-|-|}

                        \rowcolor{lightgray}
                            &   &   &   &   &\cellcolor{green!50!white}I5 \\  \hhline{|-|-|-|-|-|-|}

                        \hhline{------}

                    \end{tabularx}
                    \caption{Execution flow through a pipelined ALU. $I_{n}$ refers
                             to line number in code listing.}
                    \label{fig:Intro:OpFwd:ALUBehav}
                \end{figure}

                In \cref{fig:Intro:OpFwd:ALUBehav}, each of the \emph{Add} stages
                performs a 16-bit addition of each \ttfamily int16 \normalfont
                chunk of the 64-bit inputs. 
                If operand forwarding were to be used, the output of \emph{Add 1} 
                would need to be fed back to its inputs for the next instruction.
                The same would be needed for each subsequent stage too.
                See \linksection{sec:ALU} for how this is actually done.

    \section{Program Counter}\label{sec:PC}

        The PC's job is (generally) to increment by 4 every clock cycle to fetch 
        the next instruction in memory. 
        On occasion, it will need to stall in place, load a provided value, or 
        add a constant to its previous value to branch.

        While outwardly simple, this is fairly complex to actually implement in 
        64 bits, expecially the branch operation which requires a 12-bit add, 
        then a carry to propagate up the remaining bits. 
        Since there could realistically be any arbitrary sequence of branches, 
        jumps, normal increments or stalls, all of the separate branches need to
        be done in parallel and selected from at the very end.

    \section{Decode Logic}\label{sec:Decode}

    \section{Immediate Value Generator}\label{sec:ImVal}

    \section{Registers}\label{sec:Regs}

        RV64i specifies 32 64-bit general-purpose registers and a program
        counter, PC. x0 is hard-wired to \verb|0x0000 0000 0000 0000|; there is 
        no stack pointer.
        None of the registers are otherwise special, but do have expected uses 
        as per the calling convention \cite{RV-CallConv}, shown in 
        \cref{tab:Regs:CallConv}.

        %Calling convention table
        \begin{table}[htb!]
            \centering
            \caption{RISC-V calling convention}\label{tab:Regs:CallConv}

            \begin{tabularx}{\textwidth}{
                >{\hsize=0.15\hsize\raggedright\arraybackslash}X
                >{\hsize=0.20\hsize\raggedright\arraybackslash}X
                >{\hsize=0.35\hsize\raggedright\arraybackslash}X
                >{\hsize=0.30\hsize\raggedright\arraybackslash}X
                }

                \toprule

                Register    &ABI Mnemonic   &Meaning    &Preserved across calls?    \\

                \midrule\addlinespace

                x0      &zero   &Zero     &--- (Immutable)                  \\
                x1      &ra     &Return address     &No                     \\
                x2      &sp     &Stack Pointer      &Yes                    \\
                x3      &gp     &Global Pointer     &--- (Unallocatable)    \\
                x4      &tp     &Thread Pointer     &--- (Unallocatable)    \\
                x5-7    &t0-2   &Temp. Registers    &No                     \\
                x8-9    &s0-s1  &Callee-saved regs. &Yes                    \\
                x10-17  &a0-7   &Argument registers &No                     \\
                x18-27  &s2-11  &Callee-saved regs. &Yes                    \\
                x28-31  &t3-6   &Temp. Registers    &No                     \\

                \bottomrule

            \end{tabularx}
        \end{table}

        As each register is effectively the same, they are most easily
        implemented using SRAM.
        Learning from \oldlonglogo, I have decided to use the \ramname 
        \cite{RegRAMChip}; it's a 64k x 16-bit asynchronous SRAM with a 10 ns 
        access time and single 3.3 V supply.

        \subsection{Theory of Operation}\label{sec:Regs:TheoryOp}

            For every RV64i operation, there are up to two operands, meaning up 
            to two registers may be read each cycle. There may also be a value 
            written into a register.
            To avoid using multiport RAM, two copies of the registers are 
            needed: \textbf{x} and \textbf{y}; these two are both written to and 
            read from at the same time.
            The \ramshort\  is 16-bit, so there are two sets of four RAM chips
            total.

            \begin{figure}[htb!]
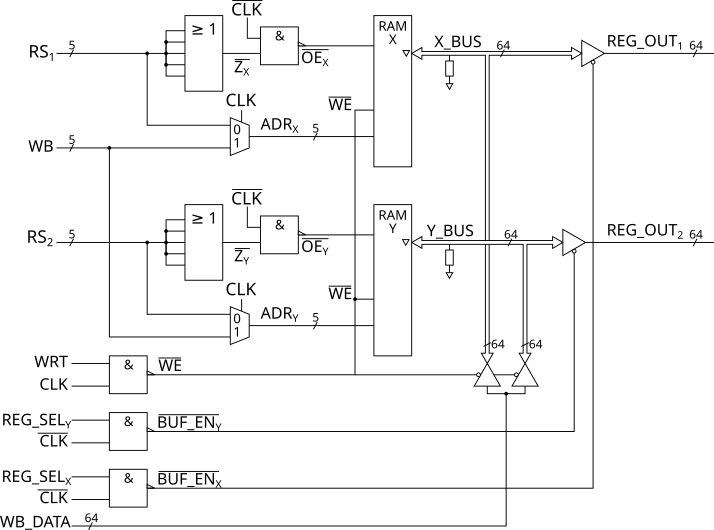
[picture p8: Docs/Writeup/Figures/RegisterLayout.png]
                
                \caption{The \longlogo\ register file.}
                \label{fig:Regs:TheoryOp:StdRegFile}
            \end{figure}

            Both access to \textbf{X} and \textbf{Y} (Read/Write) occur within 
            one cycle; writes are completed on the rising edge, $\phi_{1}$; and 
            reads on the falling edge, $\phi_{2}$. 
            This order of operations means the register card doesn't need to 
            latch its input, WB\_DATA, or outputs, \(\mathrm{REG\_OUT_{1}}\) and 
            \(\mathrm{REG\_OUT_{2}}\).

            For the purposes of explanation, both RAM banks will be 
            collectively referred to as "R".
            The logic is otherwise identical between \textbf{X} and \textbf{Y},
            so either could be inserted in R's place.

            \subsubsection{Write Phase, \(\mathbf{\phi_{1}}\)}
                \label{sec:Regs:TheoryOp:Write}

                Register writes occur on the rising edge of the clock, 
                \(\phi_{1}\), and are controlled only by the external 
                \textbf{WRT} signal. 
                Regardless of whether a value is to be written to a register, 
                the address for that 'write' is selected.
                This setup helps to minimise control circuitry.

                \paragraph{Write Enabled, \textbf{WRT} = 1}
                    \label{par:Regs:TheoryOp:Write:Wrt}

                    When \textbf{WRT} is high, \(\mathbf{\overline{WE}}\) goes
                    low and puts the \ramshort\ into a write cycle. 
                    \textbf{R\_BUS} is driven to the value on \textbf{WB\_DATA} 
                    which is written into the selected register.

                \paragraph{Write Disabled, \textbf{WRT} = 0}
                    \label{par:Regs:TheoryOp:Write:NoWrt}

                    When \textbf{WRT} is low, \(\mathbf{\overline{WE}}\) remains
                    high and the \ramshort s\ have their output disabled via
                    \(\mathbf{\overline{OE_{R}}}\).
                    \textbf{R\_BUS} is then passively pulled down to a value of
                    \verb|0x0000 0000 0000 0000|.

            \subsubsection{Read Phase: \(\mathbf{\phi_{2}}\)}
                \label{sec:Regs:TheoryOp:Read}

                Reads occur on the falling edge of the clock, \(\phi_{2}\), and
                may give a real register value or a zero depending on the read
                address (see below).
                Regardless of whether an \ramshort s is actually read from, its 
                address lines, \(\mathbf{ADR_{R}}\), are set as if it was.
                
                \paragraph{Not Reading From 'zero', \(\mathbf{RS_{R} \ne 0}\)}
                    \label{par:Regs:TheoryOp:Read:NotZero}
                    
                    When reading from any register other than \emph{x0}, 
                    \(\mathbf{Z_{R}}\) will be high, setting
                    \(\mathbf{\overline{OE_{R}}}\) low during \(\phi_{2}\).
                    \textbf{R\_BUS} is thus driven to the contents of \emph{xR}.

                \paragraph{Reading From 'zero', \(\mathbf{RS_{R}=0}\)}
                    \label{par:Regs:TheoryOp:Read:Zero}

                    When reading from \emph{x0}, \(\mathbf{\overline{Z_{R}}}\)
                    goes low and, during \(\phi_{2}\), 
                    \(\mathbf{\overline{OE_{R}}}\) stays high, again leaving
                    \textbf{R\_BUS} to be passively pulled to
                    \verb|0x0000 0000 0000 0000|

            \subsubsection{Output Buffers}\label{sec:Regs:TheoryOp:OutBuf}
               
                Since \logo\ will be implementing operand forwarding, there are
                some instances where the input to the ALU isn't necessarily from
                the register file.
                Therefore, the register file needs to be "selectable" by the CPU
                control logic.
                As such, the outputs of this section, \(\mathbf{REG\_OUT_{1}}\) 
                and \(\mathbf{REG\_OUT_{2}}\) are connected to their respective
                buses via tri-state buffers.

            % Register Timing Diagram
            \begin{figure}[htb!]
                \centering
                \begin{tikzpicture}[timing/picture, timing/unit=5mm]

                    %5mm before first clk, 30mm for [Read 0, Write, No Write], 5mm after last clock

                    \timing[name=CLKTim] at (0,0) {
                            LN(T0)
                            3{H}N(T1) 3{L}N(T2)
                            3{H}N(T3) 3{L}N(T4)
                            3{H}N(T5) 3{L}N(T6)
                            H
                        };
                        \node[anchor=east](CLK_Label) at (CLKTim.west){
                            CLK
                        };

                    \timing[name=Adr1] at (0,-2) {
                            D{}
                            6{D}{00000}
                            6{D}{01000}
                            6{D}{01001}
                            D
                        };
                        \node[anchor=east](Adr1_Label) at (Adr1.west){
                            \(\mathrm{RS_{1}}\)[5]
                        };

                    \timing[name=Adr2] at (0,-4) {
                            D{}
                            6{D}{01010}
                            6{D}{00000}
                            6{D}{01011}
                            D
                        };
                        \node[anchor=east](Adr2_Label) at (Adr2.west){
                            \(\mathrm{RS_{2}}\)[5]
                        };

                    \timing[name=wAdr] at (0,-6) {
                            D{}
                            6{D}{00000}
                            6{D}{11111}
                            6{D}{11110}
                            D
                        };
                        \node[anchor=east](wAdr_Label) at (wAdr.west){
                            WB[5]
                        };

                    \timing[name=WrCtrl] at (0,-8) {
                            U
                            3{L} 3{H}
                            3{L} 3{H}
                            3{H} 3{H}
                            U
                        };
                        \node[anchor=east](WrCtrl_Label) at (WrCtrl.west){
                            \(\mathrm{\overline{WE}}\)
                        };

                    \timing[name=WrCtrl] at (0,-10) {
                            U
                            3{H} 3{H}
                            3{H} 3{L}
                            3{H} 3{L}
                            U
                        };
                        \node[anchor=east](WrCtrl_Label) at (WrCtrl.west){
                            \(\mathrm{\overline{OE_{X}}}\)
                        };

                    \timing[name=WrCtrl] at (0,-12) {
                            U
                            3{H} 3{L}
                            3{H} 3{H}
                            3{H} 3{L}
                            U
                        };
                        \node[anchor=east](WrCtrl_Label) at (WrCtrl.west) {
                            \(\mathrm{\overline{OE_{Y}}}\)
                        };

                    \timing[name=xAdr] at (0, -14) {
                            D{}
                            3{D}{00000} 3{D}{00000}
                            3{D}{11111} 3{D}{01000}
                            3{D}{11110} 3{D}{01001}
                            D{}
                        };
                        \node[anchor=east](xAdr_Label) at (xAdr.west){
                            \(\mathrm{ADR_{X}}\)[5]
                        };

                    \timing[name=yAdr] at (0, -16) {
                            D{}
                            3{D}{00000} 3{D}{01010}
                            3{D}{11111} 3{D}{00000}
                            3{D}{11110} 3{D}{01011}
                            D{}
                        };
                        \node[anchor=east](yAdr_Label) at (yAdr.west){
                            \(\mathrm{ADR_{Y}}\)[5]
                        };

                    \timing[name=xData] at (0, -18) {
                            D{}
                            3{D}{\(\mathrm{WB\_DATA}\)} 3{D}{'zero'}
                            3{D}{\(\mathrm{WB\_DATA}\)} 3{D}{'s0'}
                            3{D}{'zero'} 3{D}{'s1'}
                            D{}
                        };
                        \node[anchor=east](xData_Label) at (xData.west){
                            \(\mathrm{X\_BUS}\) [64]
                        };

                    \timing[name=yData] at (0, -20) {
                        D{}
                        3{D}{\(\mathrm{WB\_DATA}\)} 3{D}{'a0'}
                        3{D}{\(\mathrm{WB\_DATA}\)} 3{D}{'zero'}
                        3{D}{'zero'} 3{D}{'t5'}
                        D{}
                        };
                        \node[anchor=east](yData_Label) at (yData.west){
                            \(\mathrm{Y\_BUS}\) [64]
                        };

                    \timing[name=WrCtrl] at (0,-22) {
                            U
                            3{H} 3{L}
                            3{H} 3{H}
                            3{H} 3{L}
                            U
                        };
                        \node[anchor=east](WrCtrl_Label) at (WrCtrl.west){
                            \(\mathrm{\overline{BUF\_EN_{X}}}\)
                        };

                    \timing[name=WrCtrl] at (0,-24) {
                            U
                            3{H} 3{L}
                            3{H} 3{H}
                            3{H} 3{H}
                            U
                        };
                        \node[anchor=east](WrCtrl_Label) at (WrCtrl.west){
                            \(\mathrm{\overline{BUF\_EN_{Y}}}\)
                        };

                    \timing[name=yData] at (0, -26) {
                        D{}
                        3{U} 3{D}{'zero'}
                        3{U} 3{U}
                        3{U} 3{D}{'s1'}
                        D{}
                        };
                        \node[anchor=east](yData_Label) at (yData.west){
                            \(\mathrm{REG\_OUT_{1}}\) [64]
                        };

                    \timing[name=yData] at (0, -28) {
                        D{}N(B0)
                        3{U}N(B1) 3{D}{'a0'}N(B2)
                        3{U}      3{U}N(B4)
                        3{U}      3{U}N(B6)
                        D{}
                        };
                        \node[anchor=east](yData_Label) at (yData.west){
                            \(\mathrm{REG\_OUT_{2}}\) [64]
                        };

                    \draw[black](T0.HIGH)+(0, 3.5) -- (B0.low) node[pos=0, anchor=north west, black, align=left]{
                        \scriptsize WRT = 1\\
                        \(\scriptstyle REG\_SEL_{X}\) = 1\\
                        \(\scriptstyle REG\_SEL_{Y}\) = 1
                        };
                    \draw[black](T2.HIGH)+(0, 3.5) -- (B2.low) node[pos=0, anchor=north west, black, align=left]{
                        \scriptsize WRT = 1\\
                        \(\scriptstyle REG\_SEL_{X}\) = 0\\
                        \(\scriptstyle REG\_SEL_{Y}\) = 0
                        };
                    \draw[black](T4.HIGH)+(0, 3.5) -- (B4.low) node[pos=0, anchor=north west, black, align=left]{
                        \scriptsize WRT = 0\\
                        \(\scriptstyle REG\_SEL_{X}\) = 1\\
                        \(\scriptstyle REG\_SEL_{Y}\) = 0
                        };
                    \draw[black](T6.HIGH)+(0, 3.5) -- (B6.low) ;

                    \node[anchor=south west] at (T0.low) {\footnotesize\(\phi_{1}\)};
                    \node[anchor=south west] at (T1.low) {\footnotesize\(\phi_{2}\)};

                    \node[anchor=south west] at (T2.low) {\footnotesize\(\phi_{1}\)};
                    \node[anchor=south west] at (T3.low) {\footnotesize\(\phi_{2}\)};

                    \node[anchor=south west] at (T4.low) {\footnotesize\(\phi_{1}\)};
                    \node[anchor=south west] at (T5.low) {\footnotesize\(\phi_{2}\)};

                \end{tikzpicture}

                \caption{Register file timing diagram.}
                \label{tim:Regs:TheoryOp:RegTiming}
            \end{figure}

        \subsection{Control Logic}\label{sec:Regs:CtrlLogic}

            \Cref{fig:Regs:TheoryOp:StdRegFile} shows an overview of the 
            register file. The control signals present are described in
            \cref{tab:Regs:TheoryOp:LogicTab}.

            \begin{table}[htb!]
                \centering
                \renewcommand{\arraystretch}{1.5}
                \caption{Register Card control signal definitions.}
                \label{tab:Regs:TheoryOp:LogicTab}
                \begin{tabularx}{\textwidth}{
                        >{\hsize=0.2\hsize\raggedright\arraybackslash}X
                        >{\hsize=0.4\hsize\raggedright\arraybackslash}X
                        >{\hsize=0.4\hsize\raggedright\arraybackslash}X
                    }
                    \toprule
                    Signal                      &Equation   &Explanation                \\
                    \midrule\addlinespace
                    \textbf{CLK}                &---        &Clock input                \\
                    \(\mathbf{RS_{1}}\)         &---        &Read address 1             \\
                    \(\mathbf{RS_{2}}\)         &---        &Read address 2             \\
                    \(\mathbf{WB}\)             &---        &Write address              \\
                    \textbf{WRT}                &---        &Write enable               \\
                    \(\mathbf{REG\_SEL_{1}}\)   &---        &Output \textbf{X\_BUS}     \\
                    \(\mathbf{REG\_SEL_{2}}\)   &---        &Output \textbf{Y\_BUS}     \\
                    \textbf{WB\_DATA}           &---        &Data to write this cycle   \\
                    \midrule\addlinespace
                    
                     \(\mathbf{\overline{Z_{X}}}\)   
                    &\(\sum_{i=0}^{4}\left(\mathbf{RS_{1,i}}\right)\)
                    &Not reading from 'zero'\\

                      \(\mathbf{\overline{Z_{Y}}}\)   
                    &\(\sum_{i=0}^{4}\left(\mathbf{RS_{2,i}}\right)\)
                    &\\

                     \(\mathbf{\overline{OE_{X}}}\)   
                    &\(\overline{\mathbf{\overline{Z_{X}}} \cdot \mathbf{\overline{CLK}}}\)
                    &RAM output enable\\

                     \(\mathbf{\overline{OE_{Y}}}\)   
                    &\(\overline{\mathbf{\overline{Z_{Y}}} \cdot \mathbf{\overline{CLK}}}\)
                    &\\\midrule\addlinespace

                     \(\mathbf{\overline{WE}}\)
                    &\(\overline{\mathbf{CLK \cdot WRT}}\)
                    &Write enable signal\\

                     \(\mathbf{REG\_OUT_{1}}\)
                    &\(\overline{\mathbf{\overline{CLK} \cdot REG\_SEL_{1}}}\)
                    &Enable output to ALU\\

                     \(\mathbf{REG\_OUT_{2}}\)
                    &\(\overline{\mathbf{\overline{CLK} \cdot REG\_SEL_{2}}}\)
                    &\\
                    
                    \bottomrule

                \end{tabularx}
            \end{table}

    \section{ALU}\label{sec:ALU}

        The \longlogo ALU is comprised of three blocks - the Adder, Shifter and 
        Logicer.
        The Adder computes \(A \pm B\); the Shifter shifts \(A\) up or down 
        by \(n\) bits; and the Logic-er performs the bitwise logic operations 
        \(A \cdot B\), \(A + B\) and \(A \oplus B\). 
        The 64-bit values \(A\) and \(B\) may be read from registers or
        immediate values derived from an instruction. 
        Each of the three blocks are contained on separate circuit boards, and 
        run in parallel. 
        Their outputs are calculated for all inputs with the relevant one 
        forwarded to the next pipeline stage.

        \subsection{Adder}\label{sec:ALU:Adder}

            \begin{figure}[htb!]
                \centering
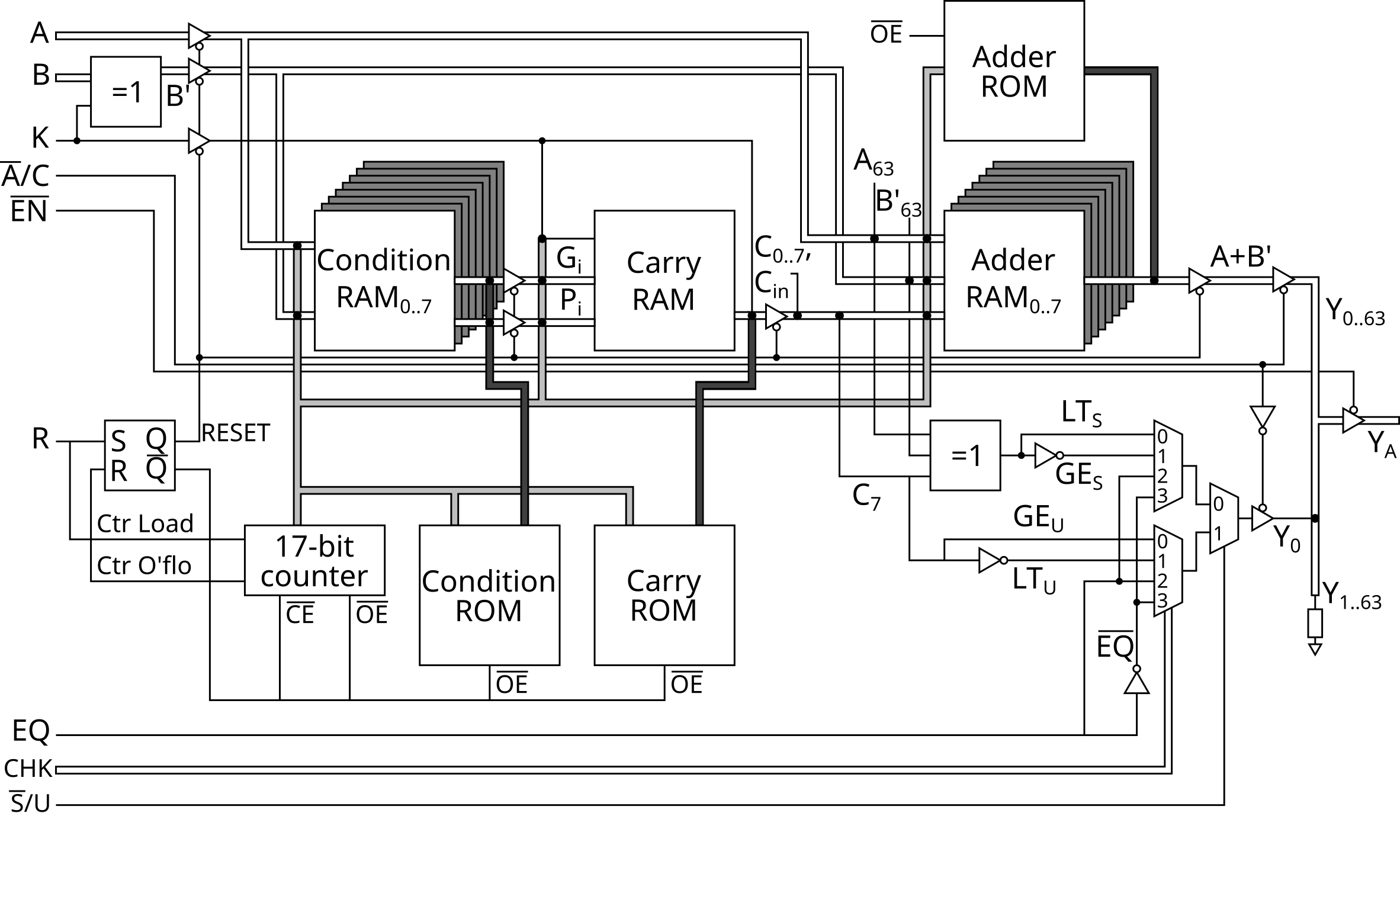
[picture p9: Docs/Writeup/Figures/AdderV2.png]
                
                \caption{
                    Layout of the adder circuit.
                    Logic shared between similar signals combined for space.
                }
                \label{fig:ALU:Adder:Layout}
            \end{figure}

            The adder computes \(A \pm B\) and optionally checks the result 
            against each of the "flags" for the calculation: \(A < B, A = B\) 
            and \(A \ge B\). 
            In \oldlogo, this procedure was to be pipelined at up to six 
            stages, but resulted in both huge pipelines and complications in 
            feeding partial results back to previous stages, possibly from 
            multiple instructions at multiple different points in their 
            execution.
            In \logo, however, the entire ALU instead operates in one cycle - 
            the length of this defining the overall cycle length of the CPU.

            As you can see from \cref{fig:ALU:Adder:Layout}, the adder remains
            one of the most complex parts of the CPU, despite being only a 
            third of the ALU.
            Using RAM with \textasciitilde8 ns access time, this section has a critical path
            of \textasciitilde50 ns through the zero check logic.
            This is markedly better than a more brute-force approach, though
            still limits the maximum clock frequency of \textasciitilde 20 MHz.

            \subsubsection{Method}\label{sec:ALU:Adder:Method}

                Addition and subtraction are both done with the same circuitry, 
                with a pre-conditioning step for the second input, \(B\). 
                Using 2's compliment to represent negative numbers, an 
                \(n\)-bit number, \(x\), can be negated by inverting its 
                bits and adding 1:

                \begin{equation}
                    -x := (x \oplus [2^{n}-1]) + 1
                \end{equation}

                Subtracting \textbf{B} from \textbf{A} is therefore defined:

                \begin{equation}\label{eq:ALU:Adder:SubDef}
                    A - B \ \equiv\ 
                    A + (-B) \ 
                    \equiv\ A + (B \oplus [2^{n}-1]) + 1
                \end{equation}

                \Cref{eq:ALU:Adder:SubDef} is implemented by bitwise XORing 
                \(B\) with the ADD/SUB setting, \(K\)
                , and setting the carry input,
                $C_{in}$ to the same:

                \begin{equation}
                    K =
                    \begin{cases}
                        0   & \text{if Adding}      \\
                        1   & \text{if Subtracting} 
                    \end{cases}
                \end{equation}

                \begin{equation}
                    A - B \ \equiv\ A + (B \oplus K) + K   
                \end{equation}

                The XORed \(B\) will be called \(B'\) from here.

                The addition, \(A + B' + K\) is a 64-bit operation which would 
                be much too slow if performed as a series of daisy-chained 
                segments due to the access time of the RAM ICs. 
                Even in the best case - where the access time were \(\le 8\) ns 
                - a chain of eight in a row would be a total delay of \(\le 64\)
                ns, greatly bottlenecking the speed of the processor. 
                A form of carry-lookahead is therefore used to reduce this 
                delay.

            \subsubsection{Modified Carry-Lookahead}\label{sec:ALU:Adder:ModCLA}

                \begin{figure}[htb!]
                    \centering
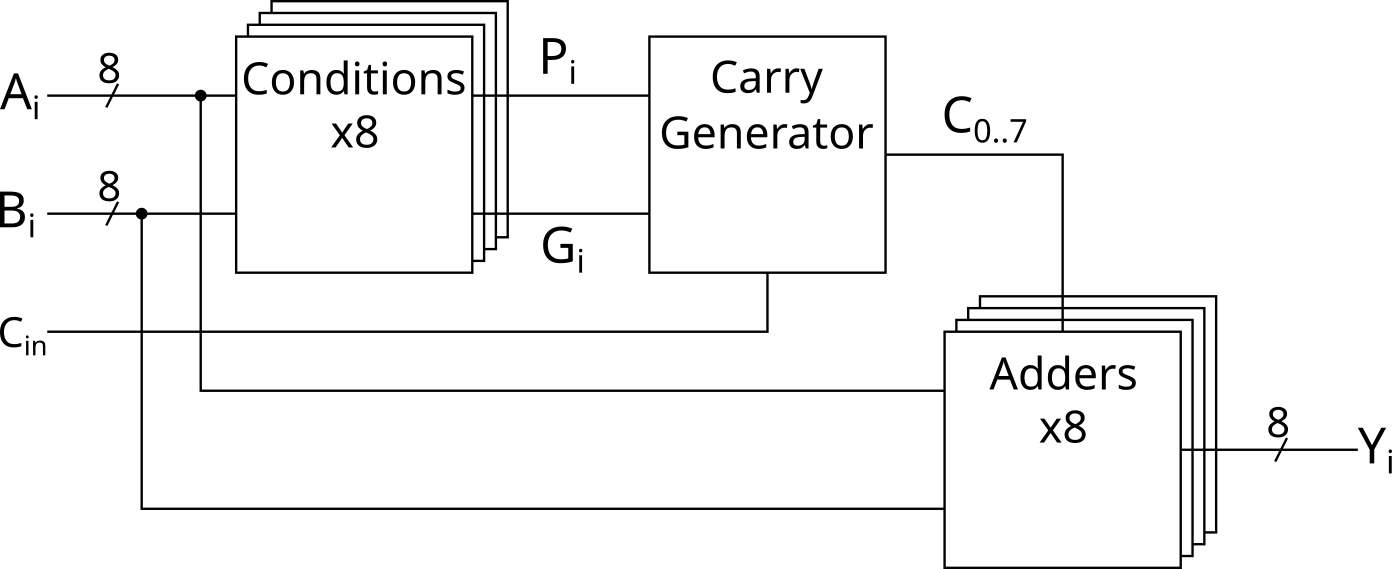
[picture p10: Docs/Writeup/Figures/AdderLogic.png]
                    
                    \caption{
                        Simplified overview of the adder logic.
                    }
                    \label{fig:ALU:Adder:Method:LogicBlocks}
                \end{figure}

                A traditional carry-lookahead circuit generates the carry signals from
                chunks of the inputs, ideally much faster than the same signal would
                be propagated up a chain of full adders. To do this, additional
                signals are generated or tapped from the full adder circuits:

                \begin{align}
                    X_n   &= A_n \cdot B_n  \label{eq:ALU:Adder:ModCLA:X}   \\
                    S_n   &= A_n \oplus B_n \label{eq:ALU:Adder:ModCLA:S}
                \end{align}

                These additional signals are then used to calculate whether the \(n\)-bit
                chunk generates, \emph{G}, or propagates, \emph{P}, a carry.

                \begin{equation}\label{eq:ALU:Adder:ModCLA:G}
                    \mathbf{G}  =   (X_n) +
                                    (X_{n-1} \cdot S_{n}) +
                                    \dots +
                                    \left( X_0 \cdot \prod_{i=1}^{n}(S_i) \right)
                \end{equation}

                \begin{equation}\label{eq:ALU:Adder:ModCLA:P}
                    \mathbf{P}  =   \prod_{i=0}^{n}(S_i)
                \end{equation}

                A single 64Kx8 RAM chip is used as a lookup table for 
                \textbf{G} and \textbf{P}, both of which are forwarded to 
                another 128Kx8 RAM that generates the carry signals 
                \(\mathbf{C_{0..7}}\).

                For \(n=0\):
                \begin{equation}\label{eq:ALU:Adder:ModCLA:C0}
                    C_0 = G_0 + C_{in} \cdot P_0
                \end{equation}

                For \(1 \le n < 8\):

                \begin{equation}\label{eq:ALU:Adder:ModCLA:Cn}
                    C_n =   G_n +
                            \sum_{i=1}^{n}\left(G_{n-i} \cdot \prod_{j=0}^{i-1}\left(P_{n-j}\right)\right) +
                            C_{in}\cdot \prod_{N}\left(P_n\right)
                \end{equation}

                See \linksection{app:LogDefs:AddConds} for expanded definitions.

                Using this method, all eight carrys can be generated after only 
                two RAM accesses. 
                \(C_{in}\) and \(C_{0..6}\) are used in the calculation while
                \(C_{7}\) is used only for condition checking.

                \begin{table}[htb!]
                    \centering
                    \caption{Contents of the Condition RAM}
                    \begin{tabularx}{\textwidth}{
                            >{\hsize=0.2\hsize\arraybackslash}X
                            >{\hsize=0.2\hsize\arraybackslash}X
                            >{\hsize=0.2\hsize\arraybackslash}X
                            >{\hsize=0.2\hsize\arraybackslash}X
                            >{\hsize=0.2\hsize\arraybackslash}X
                        }
                        \addlinespace\toprule
                        \(\mathbf{A}_n\)    &\(\mathbf{B}_n\)   &Address    &\(\mathbf{G}_n\)   &\(\mathbf{P}_n\)\\
                        \midrule\addlinespace

                        0x00    &0x00   &0x0000 &0  &0  \\
                        0x00    &0x01   &0x0001 &0  &0  \\
                        \dots   &       &       &   &   \\
                        0x00    &0xFF   &0x00FF &0  &1  \\
                        0x01    &0x00   &0x0100 &0  &0  \\
                        \dots   &       &       &   &   \\
                        0x01    &0xFE   &0x01FE &0  &1  \\
                        0x01    &0xFF   &0x01FF &1  &0  \\
                        \dots   &       &       &   &   \\
                        0xFF    &0xFF   &0xFFFF &1  &0  \\
                        \bottomrule

                    \end{tabularx}
                \end{table}

                \begin{table}[htb!]
                    \centering
                    \caption{Contents of the Carry RAM}
                    \begin{tabularx}{\textwidth}{
                            >{\hsize=0.2\hsize\arraybackslash}X
                            >{\hsize=0.2\hsize\arraybackslash}X
                            >{\hsize=0.2\hsize\arraybackslash}X
                            >{\hsize=0.2\hsize\arraybackslash}X
                            >{\hsize=0.2\hsize\arraybackslash}X
                        }
                        \addlinespace\toprule
                        \(\mathbf{G}_n\)    &\(\mathbf{P}_n\)   &\(\mathbf{C}_{in}\)   &Address    &\(\mathbf{C}\)    \\
                        \midrule\addlinespace

                        00000000    &00000000   &0  &0x00000    &00000000   \\
                        00000000    &00000001   &0  &0x00001    &00000000   \\
                        \dots       &           &   &           &           \\
                        00000000    &11111111   &0  &0x000FF    &00000000   \\
                        00000001    &00000000   &0  &0x00100    &00000001   \\
                        00000001    &00000001   &0  &0x00101    &00000001   \\
                        00000001    &00000010   &0  &0x00102    &00000011   \\
                        \dots       &           &   &           &           \\
                        11111111    &11111111   &0  &0x0FFFF    &11111111   \\
                        00000000    &00000000   &1  &0x10000    &00000000   \\
                        00000000    &00000001   &1  &0x10001    &00000001   \\
                        \dots       &           &   &           &           \\ 
                        11111111    &11111111   &1  &0x1FFFF    &11111111   \\

                        \bottomrule
                    \end{tabularx}
                \end{table}
            \subsubsection{Doing the Adding}\label{sec:ALU:Adder:Adding}

                The addition itself is "executed" in eight 128Kx8 RAM chips, each
                programmed at start-up from a single 128Kx8 EEPROM. The RAM is
                addressed by each byte of the two inputs,
                \(\mathbf{A}_{n}\) and \(\mathbf{B}_{n}\), and \(\mathbf{C}_{n}\),
                which points to the result, \(\mathbf{Y}_n\).

                \begin{table}[htb]
                    \centering
                    \caption{ALU adder EEPROM contents}
                    \label{sec:ALU:Adder:Structure:ramTab}
                    \begin{tabularx}{\linewidth}{X X X X X}
                        \addlinespace
                        \toprule
                        \(\mathbf{A}_n\)  &\(\mathbf{B}_n\) &\(\mathbf{C}_n\)   &Address  &\(\mathbf{Y}_n\) \\
                        \midrule
                        \addlinespace

                        0x00    &0x00   &0  &0x00000    &0x00   \\
                        0x00    &0x01   &0  &0x00001    &0x01   \\
                        \dots   &       &   &           &       \\
                        0x01    &0x00   &0  &0x00100    &0x01   \\
                        \dots   &       &   &           &       \\
                        0x00    &0x00   &1  &0x10000    &0x01   \\
                        \dots   &       &   &           &       \\
                        0xFF    &0xFE   &1  &0x1FFFE    &0xFE   \\
                        0xFF    &0xFF   &1  &0x1FFFF    &0xFF   \\

                        \bottomrule
                    \end{tabularx}
                \end{table}

                The final result is then either forwarded to the Adder's output, or
                changed to 0/1 for the outcome of the SLT/SLTU instructions.

                In the case of ADDW/SUBW instructions which sign-extend a 32-bit answer
                to 64, the upper word is ignored and switched to \textbf{Y}[31].

            \subsubsection{Condition Checking}\label{sec:ALU:Adder:Conds}

                The RISC-V ALU needs to be able to check for three conditions for both
                signed and unsigned numbers: \(\mathbf{A < B}\), \(\mathbf{A = B}\)
                and \(\mathbf{A \ge B}\). These are only valid if the calculation
                \(\mathbf{A-B}\) was performed.
                These checks can be performed immediately after the final carry
                out has been calculated using the equations in
                \cref{tab:ALU:Adder:Conds:ALUConds}.

                \begin{table}[htb]
                    \centering
                    \renewcommand{\arraystretch}{1.2}
                    \caption{Formulae for ALU result conditons}
                    \label{tab:ALU:Adder:Conds:ALUConds}
                    \begin{tabularx}{\textwidth}{
                        >{\hsize=0.2\hsize\raggedright\arraybackslash}X
                        >{\hsize=0.1\hsize\raggedright\arraybackslash}X
                        >{\hsize=0.35\hsize\raggedright\arraybackslash}X
                        >{\hsize=0.35\hsize\raggedright\arraybackslash}X 
                        }
                        \addlinespace

                        \toprule
                        Condition   &Name   &Signed     &Unsigned   \\
                        \midrule \addlinespace

                        \(A < B\)   &LT &\(\overline{A_{63} \oplus B_{63}} \oplus C_{7}\)   &\(\overline{C_{7}}\)   \\
                        \(A = B\)   &EQ &\(Y = 0\)  &\(Y = 0\)  \\
                        \(A \ge B\) &GE &\(\overline{A < B}_S\) &\(C_7\)\\
                        \bottomrule
                    \end{tabularx}
                \end{table}

                The greater/less than checks are calculated as written, but 
                the equality check is actually calculated using the formula:

                \begin{equation}
                    \overline{EQ} = \sum_{i=0}^{63}\left( A_{i} \oplus B_{i} \right)
                \end{equation}

                In plain english: \(A\) and \(B\) are equal if 
                \(A \oplus B = 0\), which is checked in the Logicer by ORing
                together all the bits of that result.

                The results of the condition check are also forwarded to the 
                program counter to deal with branches.

        \subsection{Logicer}\label{sec:ALU:Logicer}

            \begin{figure}[htb!]
                \centering
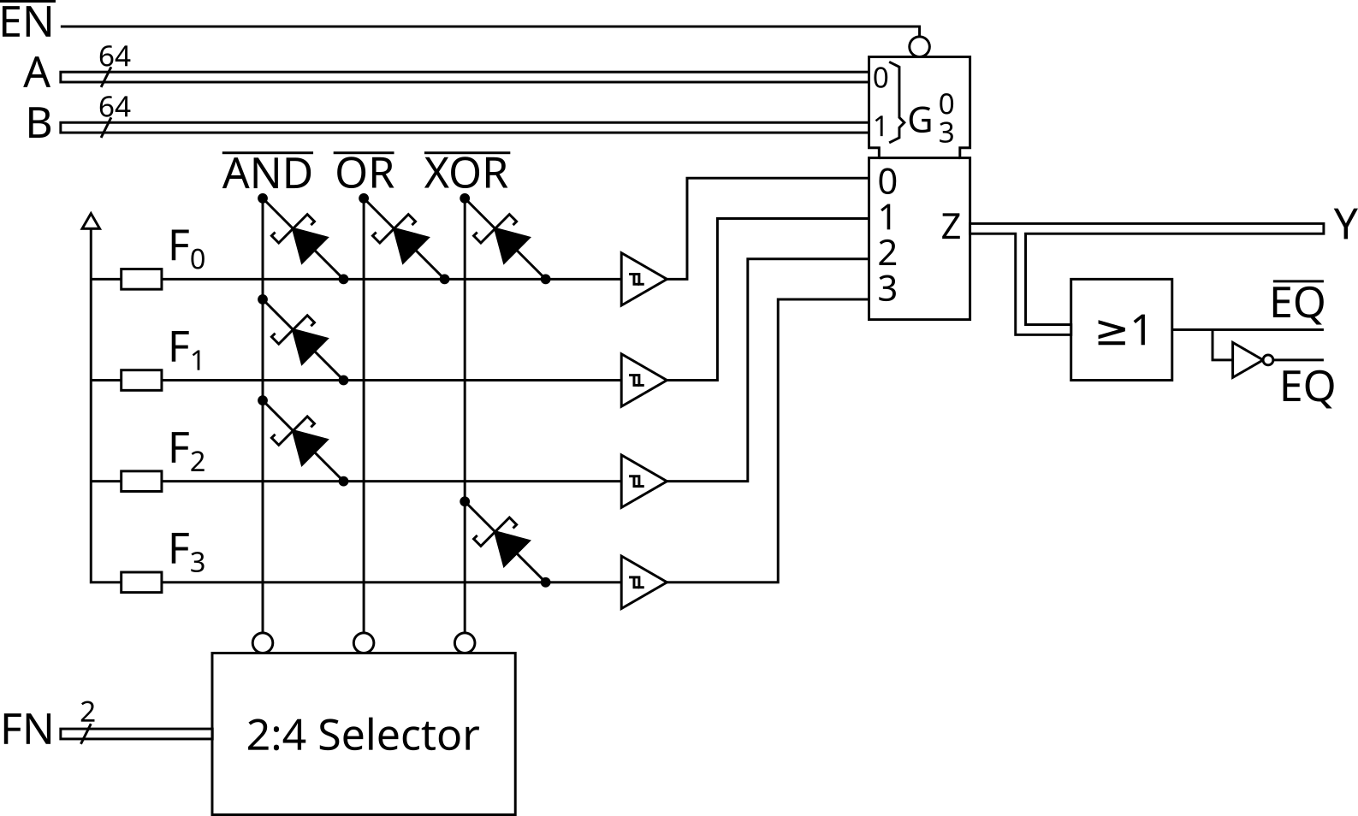
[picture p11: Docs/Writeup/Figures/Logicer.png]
                
                \caption{Diagram of the Logicer.}
                \label{fig:ALU:Logicer:Diag}
            \end{figure}

            RISC-V specifies three bitwise logic operations: AND, OR and XOR. 
            The obvious way to do this (74x08 for AND, 74x32 for OR, and 74x86 
            for XOR), takes 48 chips, plus some extra to choose which answer we 
            want - quite a high number considering what this section does. 
            This can be improved using a slightly more complex setup.

            The final output, \textbf{Y}, is sent to a tri-state buffer/line driver which
            is only enabled when the ALU performs a logic operation.

            \subsubsection{Logic from MUXs}\label{sec:ALU:Logicer:MUXLogic}

                It is possible to construct any 2-input, 1-output logic function 
                from a 4:1 MUX where the four inputs reflect the truth table of 
                the function, and the select lines are the two inputs of the 
                function.

                Constructing the logic section this way means the control logic 
                for this section is limited to a small ROM containing the truth 
                tables for the MUXs.

                \begin{table}[htb]
                    \centering
                    \caption{Truth tables of the three defined logic operations}
                    \label{tab:ALU:Logicer:MUXLogic:TruthTab}
                    \begin{subtable}{0.3\textwidth}
                        \centering
                        \begin{tabularx}{\textwidth}{
                            >{\hsize=0.3\hsize\arraybackslash}X
                            >{\hsize=0.3\hsize\arraybackslash}X
                            >{\hsize=0.4\hsize\arraybackslash}X
                            }

                            \addlinespace\toprule

                            A   &B  &\(A \cdot B\)  \\  \midrule\addlinespace
                            0   &0  &0  \\
                            0   &1  &0  \\
                            1   &0  &0  \\
                            1   &1  &1  \\
                            \bottomrule

                        \end{tabularx}
                        \caption{AND truth table}\label{tab:ALU:Logicer:MUXLogic:TruthTab:AND}
                    \end{subtable}
                    \hfill
                    \begin{subtable}{0.3\textwidth}
                        \centering
                        \begin{tabularx}{\textwidth}{
                            >{\hsize=0.3\hsize\arraybackslash}X
                            >{\hsize=0.3\hsize\arraybackslash}X
                            >{\hsize=0.4\hsize\arraybackslash}X
                            }

                            \addlinespace\toprule

                            A   &B  &\(A + B\)  \\  \midrule\addlinespace
                            0   &0  &0  \\
                            0   &1  &1  \\
                            1   &0  &1  \\
                            1   &1  &1  \\
                            \bottomrule

                        \end{tabularx}
                        \caption{OR truth table}\label{tab:ALU:Logicer:MUXLogic:TruthTab:OR}
                    \end{subtable}
                    \hfill
                    \begin{subtable}{0.3\textwidth}
                        \centering
                        \begin{tabularx}{\textwidth}{
                            >{\hsize=0.3\hsize\arraybackslash}X
                            >{\hsize=0.3\hsize\arraybackslash}X
                            >{\hsize=0.4\hsize\arraybackslash}X
                            }

                            \addlinespace\toprule

                            A   &B  &\(A \oplus B\)  \\  \midrule\addlinespace
                            0   &0  &0  \\
                            0   &1  &1  \\
                            1   &0  &1  \\
                            1   &1  &0  \\
                            \bottomrule

                        \end{tabularx}
                        \caption{XOR truth table}\label{tab:ALU:Logicer:MUXLogic:TruthTab:XOR}
                    \end{subtable}
                \end{table}

                \begin{figure}[htb]
                    \centering
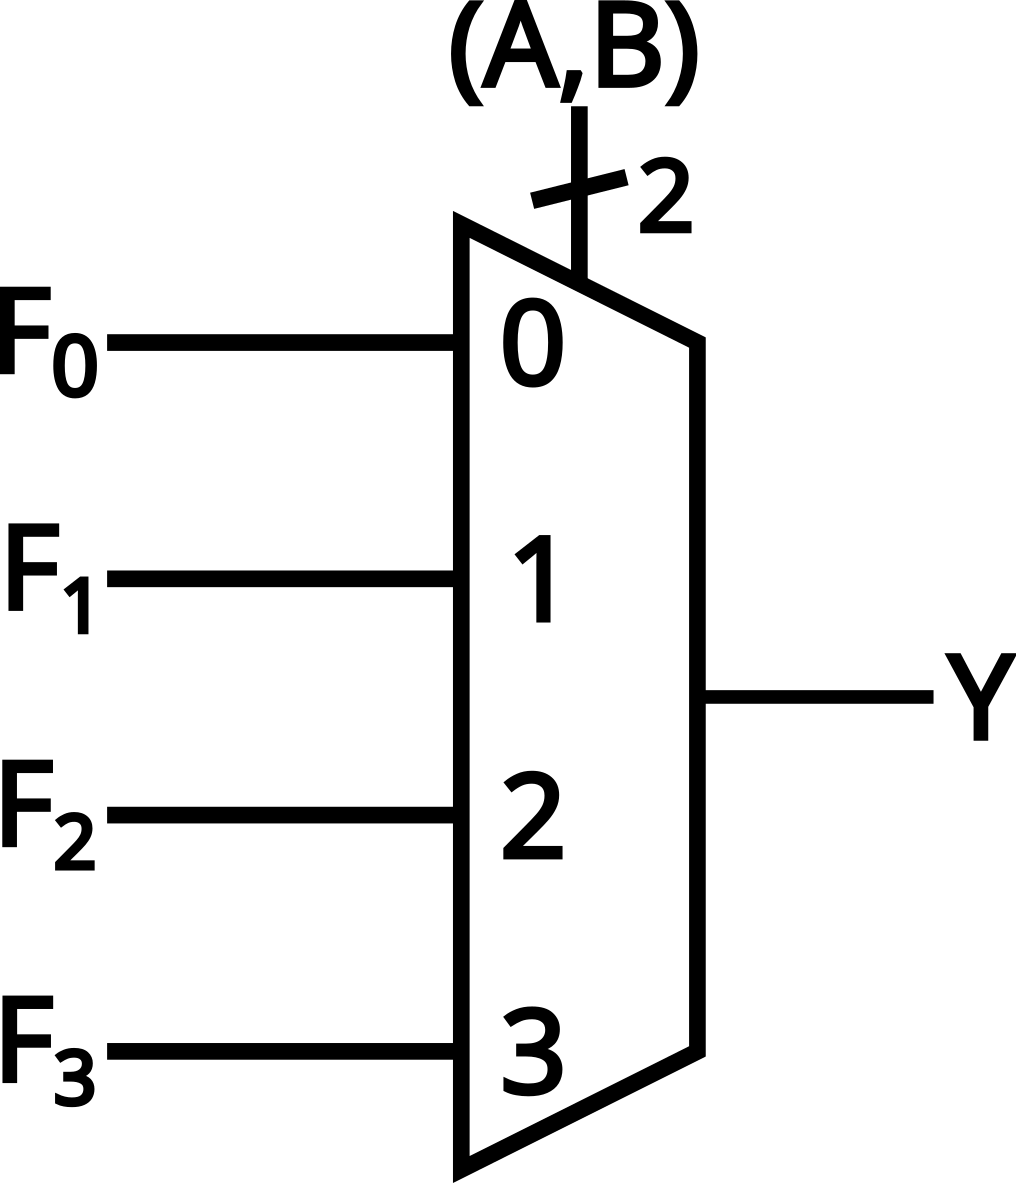
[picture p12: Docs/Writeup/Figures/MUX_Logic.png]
                    
                    \caption{Wiring of a 4:1 mux as used in the logic section.}
                    \label{sec:ALU:MUXLogic:Logicer:MuxPic}
                \end{figure}

                This method is preferable when considering the number of ICs used:

                \begin{table}[htb]
                    \centering
                    \caption{Comparison of the number of components used in designs with (a) separate logic paths and (b) MUX-based logic}
                    \label{tab:ALU:MUXLogic:Logicer:NumICs}

                    \begin{subtable}{0.45\textwidth}
                        \centering
                        \begin{tabularx}{\textwidth}{
                            >{\hsize=0.40\hsize\arraybackslash}X
                            >{\hsize=0.30\hsize\arraybackslash}X
                            >{\hsize=0.25\hsize\arraybackslash}X
                            }

                            \addlinespace \toprule

                            Section     &\#Gates    &\#ICs  \\  \midrule

                            AND         &64         &16     \\
                            OR          &64         &16     \\
                            XOR         &64         &16     \\
                            4:1 MUX     &64         &32     \\  \midrule
                            Total       &256        &80

                        \end{tabularx}
                        \caption{Using discreet logic gates}

                    \end{subtable}
                    \hfill
                    \begin{subtable}{0.50\textwidth}
                        \centering
                        \begin{tabularx}{\textwidth}{
                            >{\hsize=0.5\hsize\arraybackslash}X
                            >{\hsize=0.25\hsize\arraybackslash}X
                            >{\hsize=0.25\hsize\arraybackslash}X
                            }

                            \addlinespace \toprule

                            Section     &\#Parts    &\#ICs  \\  \midrule

                            ROM Select  &1          &1      \\
                            ROM Diodes  &6          &---    \\
                            ROM Buffers &12         &2      \\
                            4:1 MUX     &64         &32     \\  \midrule
                            Total       &75         &35

                        \end{tabularx}
                        \caption{Using MUXs}

                    \end{subtable}

                \end{table}

            \subsubsection{Setting up the MUX}\label{sec:ALU:Logicer:MUXSetup}

                The correct truth table is selected using a 2:4 selector which 
                is wired to a small, diode matrix 
                (\cref{fig:ALU:Logicer:MUXSetup:MUX_ROM}).
                A 74x1G139 2:4 takes the two-bit function select and the 
                desired bits are set from \(F_0, F_1, F_2, F_3\), which are 
                then buffered before being sent out to the MUXs. 
                The unused decoder output is left unused and unconnected to the
                matrix, resulting in a 'function' returning [1,1,1,1].

                \begin{figure}[htb]
                    \centering
                    \begin{circuitikz}

                        %Change some settings
                        \ctikzset{bipoles/length=1cm, nodes width=0.1}
                        \ctikzset{european resistors}
                        
                        %Vertical lines
                        \draw (1, 5) to (1, 0);
                        \draw (3, 5) to (3, 0);
                        \draw (5, 5) to (5, 0); 
                        
                        %Vertical Labels
                        \node[anchor=south](AND_Lab) at (1, 5) {\Large{\(\overline{\text{AND}}\)}};
                        \node[anchor=south](OR_Lab) at (3, 5) {\Large{\(\overline{\text{OR}}\)}};
                        \node[anchor=south](XOR_Lab) at (5, 5) {\Large{\(\overline{\text{XOR}}\)}};

                        %Main buses
                        \draw (0, 4)
                            to [short, -*](2, 4)
                            to [short, -*](4, 4)
                            to [short, -*](6, 4)
                            to (7, 4);
                        \draw (0, 3)  
                            to [short, -*](2, 3)
                            to (7, 3);
                        \draw (0, 2) 
                            to [short, -*](2, 2)
                            to (7, 2);
                        \draw (0, 1) 
                            to [short, -*](6, 1)
                            to (7, 1);

                        %Resistors
                        \draw (0,4) to [R, -*] (-2,4);
                        \draw (0,3) to [R, -*] (-2,3);
                        \draw (0,2) to [R, -*] (-2,2);
                        \draw (0,1) to [R] (-2,1);

                        %Pull Up line
                        \draw (-2,1) to (-2,4.5);
                        \draw (-2,4.5) node[vcc]{VCC};

                        %Horizontal Labels
                        \node[anchor=west](F0_Lab) at (8.5, 4) {\Large\(F_0\)};
                        \node[anchor=west](F0_Lab) at (8.5, 3) {\Large\(F_1\)};
                        \node[anchor=west](F0_Lab) at (8.5, 2) {\Large\(F_2\)};
                        \node[anchor=west](F0_Lab) at (8.5, 1) {\Large\(F_3\)};

                        %Draw Buffers
                        \draw (7, 1) node[ieeestd buffer port, anchor=in 1]{};
                        \draw (7, 2) node[ieeestd buffer port, anchor=in 1]{};
                        \draw (7, 3) node[ieeestd buffer port, anchor=in 1]{};
                        \draw (7, 4) node[ieeestd buffer port, anchor=in 1]{};

                        %Draw Diodes
                        %AND
                        \draw (2, 4) to [full Schottky diode, -*] (1, 4.75);
                        \draw (2, 3) to [full Schottky diode, -*] (1, 3.75);
                        \draw (2, 2) to [full Schottky diode, -*] (1, 2.75);

                        %OR
                        \draw (4, 4) to [full Schottky diode, -*] (3, 4.75);

                        %XOR
                        \draw (6, 4) to [full Schottky diode, -*] (5, 4.75);
                        \draw (6, 1) to [full Schottky diode, -*] (5, 1.75);

                    \end{circuitikz}
                    \caption{
                        Diode ROM storing the truth table function, 
                        \(F_0, F_1, F_2, F_3\);
                        these are pulled \emph{up} as the outputs of a 74x139 are
                        active low.
                    }
                    \label{fig:ALU:Logicer:MUXSetup:MUX_ROM}
                \end{figure}

                The buffers in \cref{fig:ALU:Logicer:MUXSetup:MUX_ROM} serve
                two purposes:
                firstly they help with fanout - there are 64 inputs per 
                \emph{Function} line and, for a \(4.7 k\Omega \) resistor,
                each can get \textasciitilde \(0.7 mA\) (this isn't too low for 
                LVC logic, but I would like more headroom);
                and secondly, they smooth over any issues the diodes may cause.

                As there are 64 total MUXs needed for the logic functions, the
                \emph{Function} lines are buffered four times in parallel so 
                each buffer only needs to drive 16 inputs. 
                The buffers themselves serve two purposes: first to provide 
                enough current to drive all 64 MUXs and second to amplify the
                \(F_{i}\) signals to counter the voltage drop from the diodes.
                With a forward voltage of \textasciitilde0.3 V; this drops the nominal 
                signal level to 3.0 V, only 0.6 V above the
                minimum \(V_{ih}\) of low-voltage CMOS logic chips.

        \subsection{Shifter}\label{sec:ALU:Shifter}

            The RISC-V ISA defines several shift operations, each of which can, in one
            operation, shift the input by an arbitrary number of bits up to X\_LEN-1.
            In RV64i, additional instructions shift 32-bit values and sign extend
            up to 64-bits. Both left and right shifts are defined, with left shifts
            being implemented by reversing the input, shifting, then reversing the
            result again:

                \begin{equation}\label{eq:ALU:Shifter:RevShift}
                    A >> B := \text{REV}(\ \text{REV}(A) << B \ )
                \end{equation}

            This implementation favours left shifts, so any rightward shift will use
            the method in \cref{eq:ALU:Shifter:RevShift}.

            Shifts are implemented using a sequential barrel shifter - a series
            of stages which shift the input a power of two number of places
            up to 32. Each stage consists of two tri-state buffers, one buffering
            the previous stage as is, the other buffering the previous output shifted
            by the next number of bits. The \(n^{th}\) stage is then controlled by
            the \(n^{th}\) bit of the shift amount input.

            Traditionally, a sequential barrel shifter like this would use multiplexers,
            but this requires far too many (384 MUXs across 96 ICs) to be practical.
            The modified version using buffers comes from R. Baruch's RISC-V build
            \cite{RobB_Shifter}, expanded to 64-bits.

            Using 16-bit buffers in the 74LVC162244, the number of ICs can be reduced to
            8 per stage, for a total of 48 - half that of the MUX version.

            \subsubsection{Bit Order Reverser}\label{sec:ALU:Shifter:BitRev}

                In order to shift the incoming number, \textbf{A}, rightwards, it must
                be bit-reversed first. This is accomplished using two tri-state
                buffers, one buffering the number as is, the other buffering the
                reversed number.

                The reversal is accomplished by "simple" shuffling of the order of traces
                on the PCB in the following way:

                [DIAGRAM OF PCB TRACE REVERSAL]

            \subsubsection{Shift Stages}\label{sec:ALU:Shifter:ShiftStages}

    \pagebreak
    \printbibliography[heading=bibintoc, title={References}]

    \pagebreak
    \appendix
    \section{Various Logic Expansions and Definitions}
    \label{app:LogDefs}

        \subsection{Adder Conditions}
        \label{app:LogDefs:AddConds}
      
            Does the \(n^{th}\) stage propagate a carry?
            \scriptsize{
            \begin{align}
                P_0 &= S_{0,0}\cdot S_{0,1}\cdot S_{0,2}\cdot S_{0,3}\cdot S_{0,4}\cdot S_{0,5}\cdot S_{0,6}\cdot S_{0,7}\\
                P_1 &= S_{1,0}\cdot S_{1,1}\cdot S_{1,2}\cdot S_{1,3}\cdot S_{1,4}\cdot S_{1,5}\cdot S_{1,6}\cdot S_{1,7}\\
                P_2 &= S_{2,0}\cdot S_{2,1}\cdot S_{2,2}\cdot S_{2,3}\cdot S_{2,4}\cdot S_{2,5}\cdot S_{2,6}\cdot S_{2,7}\\
                P_3 &= S_{3,0}\cdot S_{3,1}\cdot S_{3,2}\cdot S_{3,3}\cdot S_{3,4}\cdot S_{3,5}\cdot S_{3,6}\cdot S_{3,7}\\
                P_4 &= S_{4,0}\cdot S_{4,1}\cdot S_{4,2}\cdot S_{4,3}\cdot S_{4,4}\cdot S_{4,5}\cdot S_{4,6}\cdot S_{4,7}\\
                P_5 &= S_{5,0}\cdot S_{5,1}\cdot S_{5,2}\cdot S_{5,3}\cdot S_{5,4}\cdot S_{5,5}\cdot S_{5,6}\cdot S_{5,7}\\
                P_6 &= S_{6,0}\cdot S_{6,1}\cdot S_{6,2}\cdot S_{6,3}\cdot S_{6,4}\cdot S_{6,5}\cdot S_{6,6}\cdot S_{6,7}\\
                P_7 &= S_{7,0}\cdot S_{7,1}\cdot S_{7,2}\cdot S_{7,3}\cdot S_{7,4}\cdot S_{7,5}\cdot S_{7,6}\cdot S_{7,7}
            \end{align}
            }\normalsize
            Does the \(n^{th}\) stage generate a carry?
            \scriptsize{
            \begin{align}
                G_0 &= X_0+P_0C_{in}\\
                G_1 &= X_1+P_1C_0+P_1P_0C_{in}\\
                G_2 &= X_2+P_2C_1+P_2P_1C_0+P_2P_1P_0C_{in}\\
                G_3 &= X_3+P_3C_2+P_3P_2C_1+P_3P_2P_1C_0+P_3P_2P_1P_0C_{in}\\
                G_4 &= X_4+P_4(C_3+P_3(C_2+P_2(C_1+P_1(C_0+P_0C_{in}))))\\
                G_5 &= X_5+P_5(C_4+P_4(C_3+P_3(C_2+P_2(C_1+P_1(C_0+P_0C_{in})))))\\
                G_6 &= X_6+P_6(C_5+P_5(C_4+P_4(C_3+P_3(C_2+P_2(C_1+P_1(C_0+P_0C_{in}))))))\\
                G_7 &= X_7+P_7(C_6+P_6(C_5+P_5(C_4+P_4(C_3+P_3(C_2+P_2(C_1+P_1(C_0+P_0C_{in}))))))) 
            \end{align}
            }\normalsize
            What is the \(n^{th}\) stage's carry in?
            \scriptsize{
            \begin{align}
                C_0 &= C_{in}\\
                C_1 &= G_0+P_0C_{in}\\
                C_2 &= G_1+P_1G_0+P_1P_0C_{in}\\
                C_3 &= G_2+P_2G_1+P_2P_1G_0+P_2P_1P_0C_{in}\\
                C_4 &= G_3+P_3G_2+P_3P_2G_1+P_3P_2P_1G_0+P_3P_2P_1P_0C_{in}\\
                C_5 &= G_4+P_4(G_3+P_3(G_2+P_2(G_1+P_1(G_0+P_0C_{in}))))\\
                C_6 &= G_5+P_5(G_4+P_4(G_3+P_3(G_2+P_2(G_1+P_1(G_0+P_0C_{in})))))\\
                C_7 &= G_6+P_6(G_5+P_5(G_4+P_4(G_3+P_3(G_2+P_2(G_1+P_1(G_0+P_0C_{in}))))))\\
                C_{out} &= G_7+P_7(G_6+P_6(G_5+P_5(G_4+P_4(G_3+P_3(G_2+P_2(G_1+P_1(G_0+P_0C_{in})))))))
            \end{align}
            }\normalsize

\end{document}

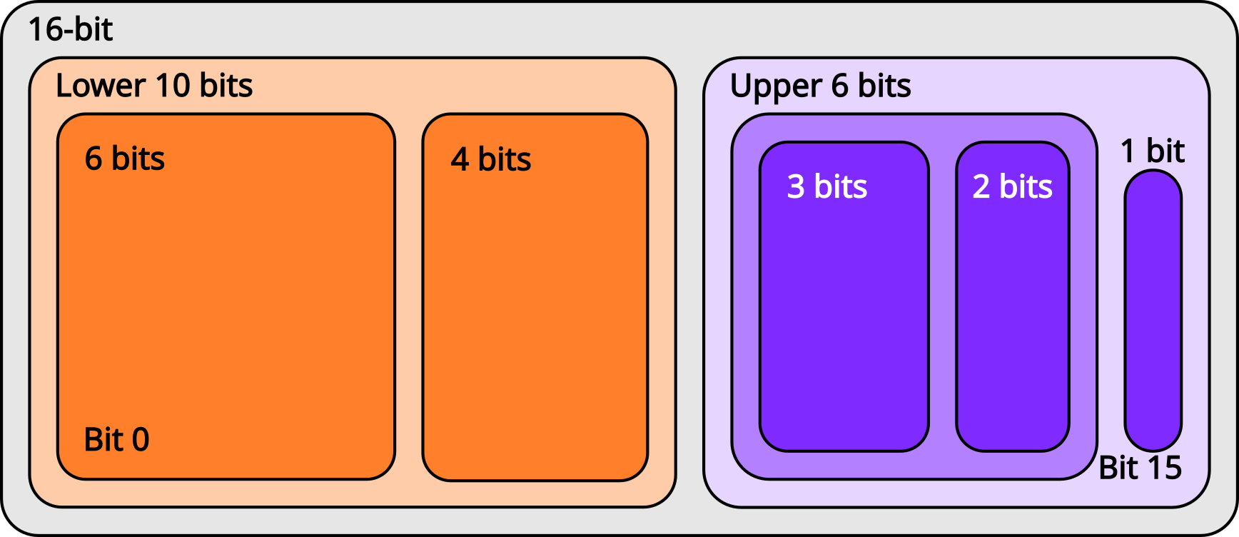
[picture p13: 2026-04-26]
Docs/Writeup/Figures/AdderCarries.png

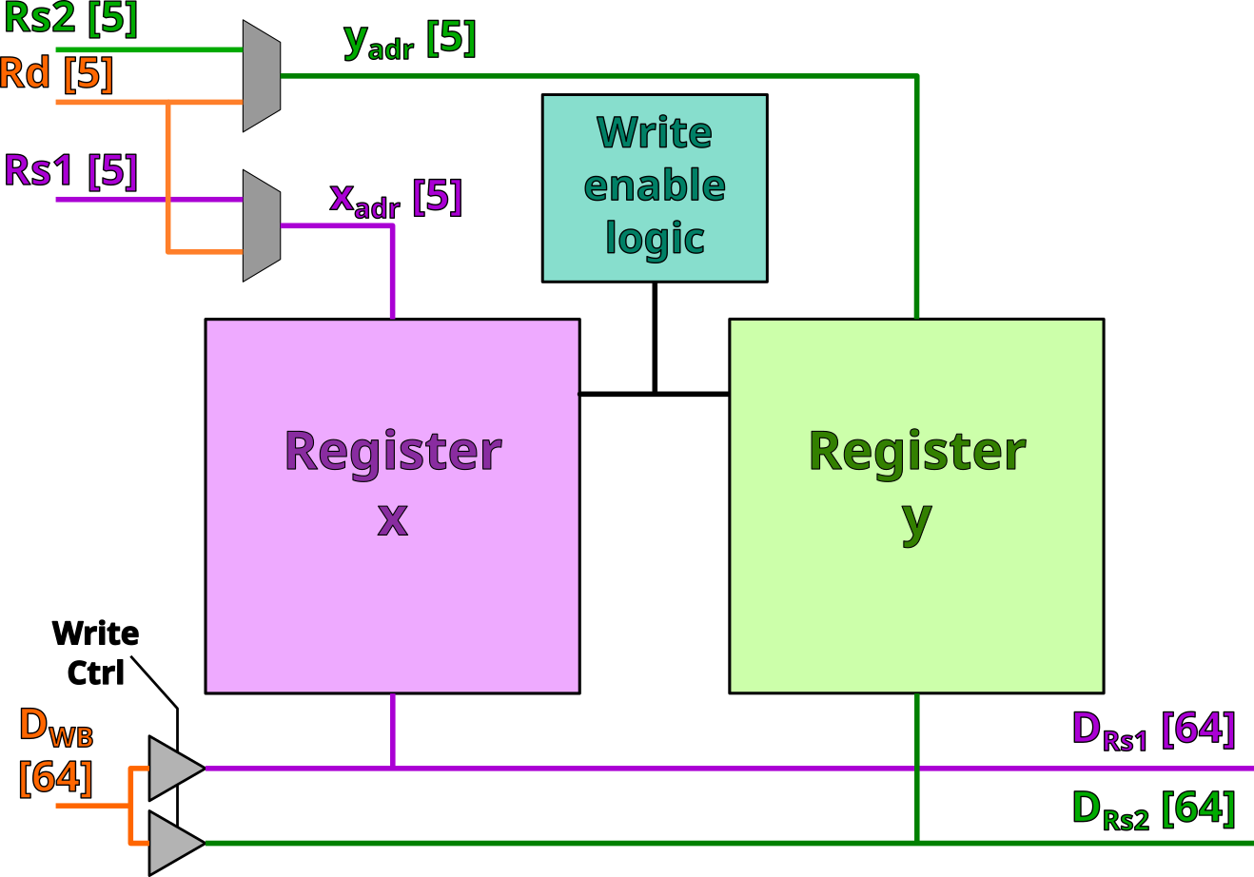
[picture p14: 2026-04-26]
Docs/Writeup/Figures/RegFile_TopLevel.png

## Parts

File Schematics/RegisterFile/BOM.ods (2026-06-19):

Id | Designator | Footprint | Quantity | Designation | Value | Supplier and ref
1 | C17,C44,C49,C1,C42,C40,C39,C18,C38,C11,C3,C46,C50,C48,C19,C5,C45,C16,C51,C36,C41,C13,C12,C43,C47,C14,C15,C37,C24,C31,C32,C23,C26,C34,C9,C25,C22,C30,C7,C28,C29,C21,C35,C20,C10,C33,C27 | C_1206_3216Metric | 47 |  | 0.1uF
2 | RN20,RN22,RN28,RN26,RN19,RN21,RN27,RN32,RN23,RN18,RN31,RN24,RN29,RN25,RN17,RN30,RN10,RN6,RN4,RN3,RN5,RN9,RN1,RN14,RN15,RN16,RN8,RN2,RN12,RN7,RN13,RN11 | R_Array_Convex_4x0603 | 32 |  | 2.2k
3 | U41,U39,U36,U40,U35,U44,U47,U33,U34,U37,U45,U38,U43,U42,U32,U46,U20,U29,U17,U22,U16,U18,U24,U30,U26,U31,U23,U25,U21,U27,U28,U19 | TSSOP-20_4.4x6.5mm_P0.65mm | 32 | 74LVC541 | N/A
4 | U6,U7 | TSSOP-14_4.4x5mm_P0.65mm | 2 | 74LVC00 | N/A
5 | C6,C2,C8,C4 | C_1206_3216Metric | 4 | 10uF | 10uF
6 | N1,N2 | BUS_PCIexpress_x16 | 2 | PCIE_16x | N/A
7 | U14,U12,U13,U15,U10,U11,U8,U9 | TSOP-II-44_10.16x18.41mm_P0.8mm | 8 | IS61WV6416DBLL-8TLI | N/A
8 | U4,U5 | TSSOP-14_4.4x5mm_P0.65mm | 2 | 74LVC32 | N/A
9 | U1,U2,U3 | SOIC-16_3.9x9.9mm_P1.27mm | 3 | 74LVC157 | N/A

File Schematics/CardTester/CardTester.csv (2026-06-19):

Reference | Qty | Value | DNP | Exclude from BOM | Exclude from Board | Footprint | Datasheet
C1,C2,C3,C4,C5,C6,C7,C8,C9,C10,C11,C12,C13,C14,C15,C16,C17,C18,C19,C20,C21,C22,C23,C24,C25,C26,C27,C28,C29,C30,C31,C32,C33,C34,C35,C36,C37,C38,C39,C40,C41,C42,C43,C44,C45,C46,C47,C48,C49,C50,C51,C52,C53,C54,C55,C56,C57,C58,C59,C60,C61,C62,C63,C64,C65,C66,C67,C68,C69,C70,C71,C72,C73,C74,C75,C76,C77,C78,C79,C80,C81,C82,C83,C84,C85,C86,C87,C88,C89,C90,C91,C92,C93,C94,C95 | 95 | 0.1u |  |  |  | Capacitor_SMD:C_0805_2012Metric_Pad1.18x1.45mm_HandSolder | ~
C96 | 1 | 10u |  |  |  | Capacitor_SMD:C_0805_2012Metric_Pad1.18x1.45mm_HandSolder | ~
C97 | 1 | 100u |  |  |  | Capacitor_SMD:C_0805_2012Metric_Pad1.18x1.45mm_HandSolder | ~
D1 | 1 | Schottky |  |  |  | Diode_SMD:D_0805_2012Metric_Pad1.15x1.40mm_HandSolder | ~
H1,H2,H3,H4 | 4 | MountingHole |  | Excluded from BOM |  | MountingHole:MountingHole_3.2mm_M3 | ~
J1 | 1 | USB_B |  |  |  | Connector_USB:USB_B_Lumberg_2411_02_Horizontal | ~
N1,N2 | 2 | PCIE_16x |  |  |  | PCIe-x16:1001878410203TLF
U1 | 1 | Pi_Pico |  |  |  | Module:RaspberryPi_Pico_Common_THT
U2 | 1 | Adafruit 4711 |  |  |  | Misc:Adafruit TLV62569 breakout (4711)
U3,U4,U5,U6,U7,U8,U9,U10,U11,U12,U13,U14,U15,U16,U17,U18,U19,U20,U21,U22,U23,U24,U25,U26,U27,U28,U29,U30,U69,U70,U71,U72,U73,U74,U75,U76,U77,U78,U79,U80,U81,U82,U83,U84,U85,U86,U87,U88,U89,U90,U91,U92,U93,U94,U95,U96,U97 | 57 | 74LVC574 |  |  |  | Package_SO:TSSOP-20_4.4x6.5mm_P0.65mm | http://www.ti.com/lit/gpn/sn74LS574
U31,U34,U35,U36,U37,U38,U39,U40 | 8 | 74LVC02 |  |  |  | Package_SO:TSSOP-14_4.4x5mm_P0.65mm | http://www.ti.com/lit/gpn/sn74hc02
U32,U33 | 2 | 74LVC138 |  |  |  | Package_SO:TSSOP-16_4.4x5mm_P0.65mm | http://www.ti.com/lit/gpn/sn74LS138
U41,U42,U43,U44,U45,U46,U47,U48,U49,U50,U51,U52,U53,U54,U55,U56,U57,U58,U59,U60,U61,U62,U63,U64,U65,U66,U67,U68 | 28 | 74LVC541 |  |  |  | Package_SO:TSSOP-20_4.4x6.5mm_P0.65mm | http://www.ti.com/lit/gpn/sn74LS541

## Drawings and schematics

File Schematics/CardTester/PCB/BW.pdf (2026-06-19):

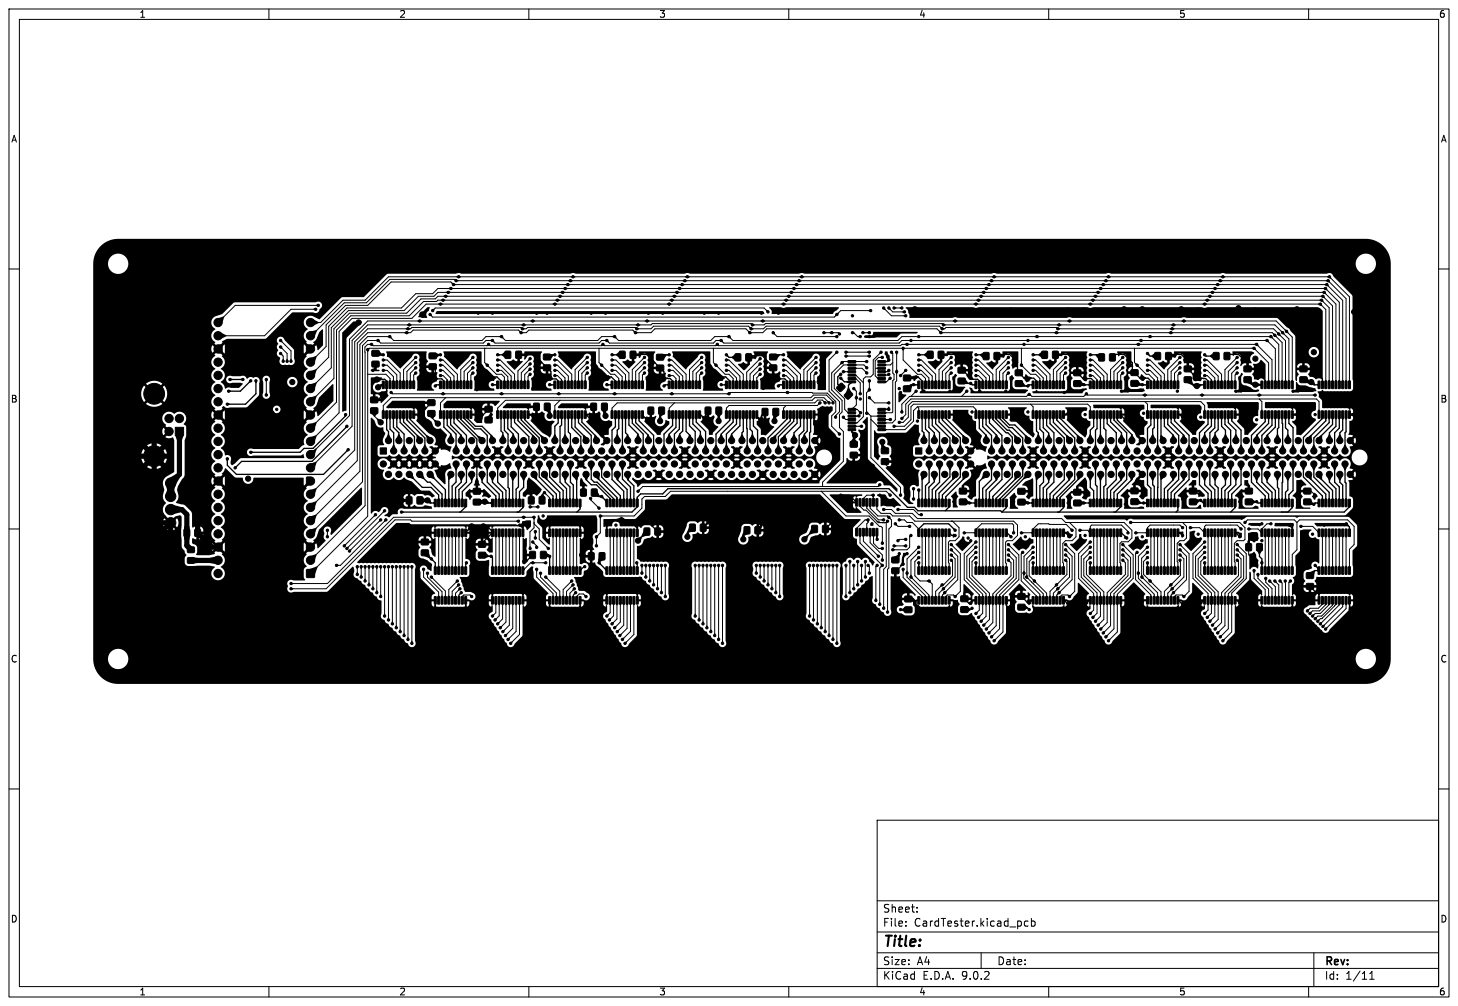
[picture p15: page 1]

Id: 1/11 Title: File: CardTester.kicad_pcb Sheet:

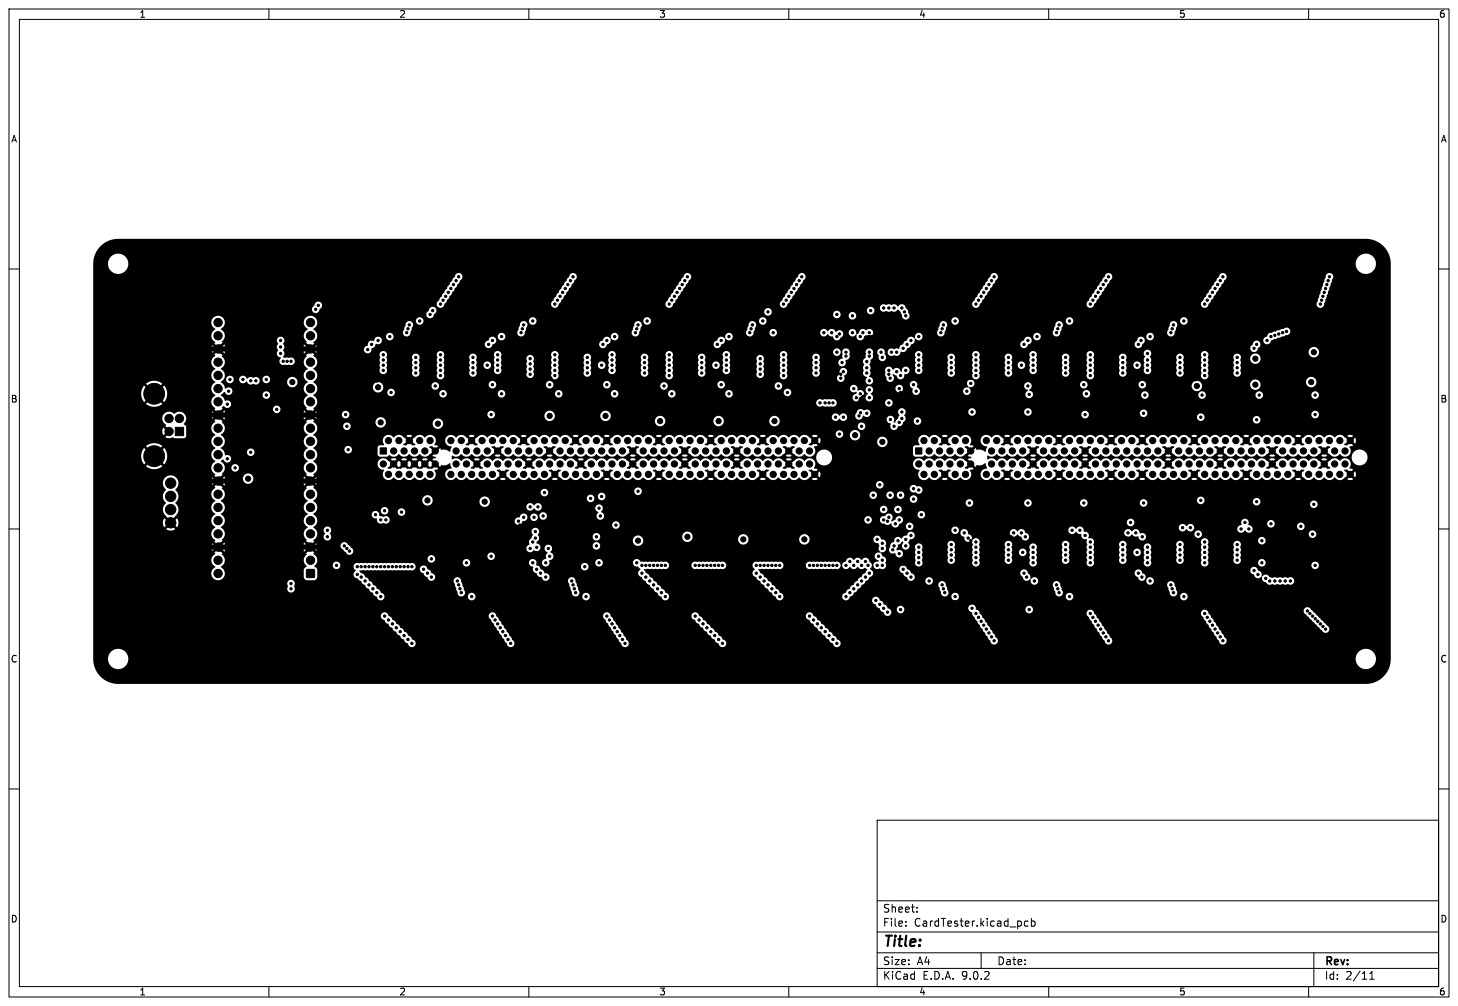
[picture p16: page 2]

Id: 2/11 Title: File: CardTester.kicad_pcb Sheet:

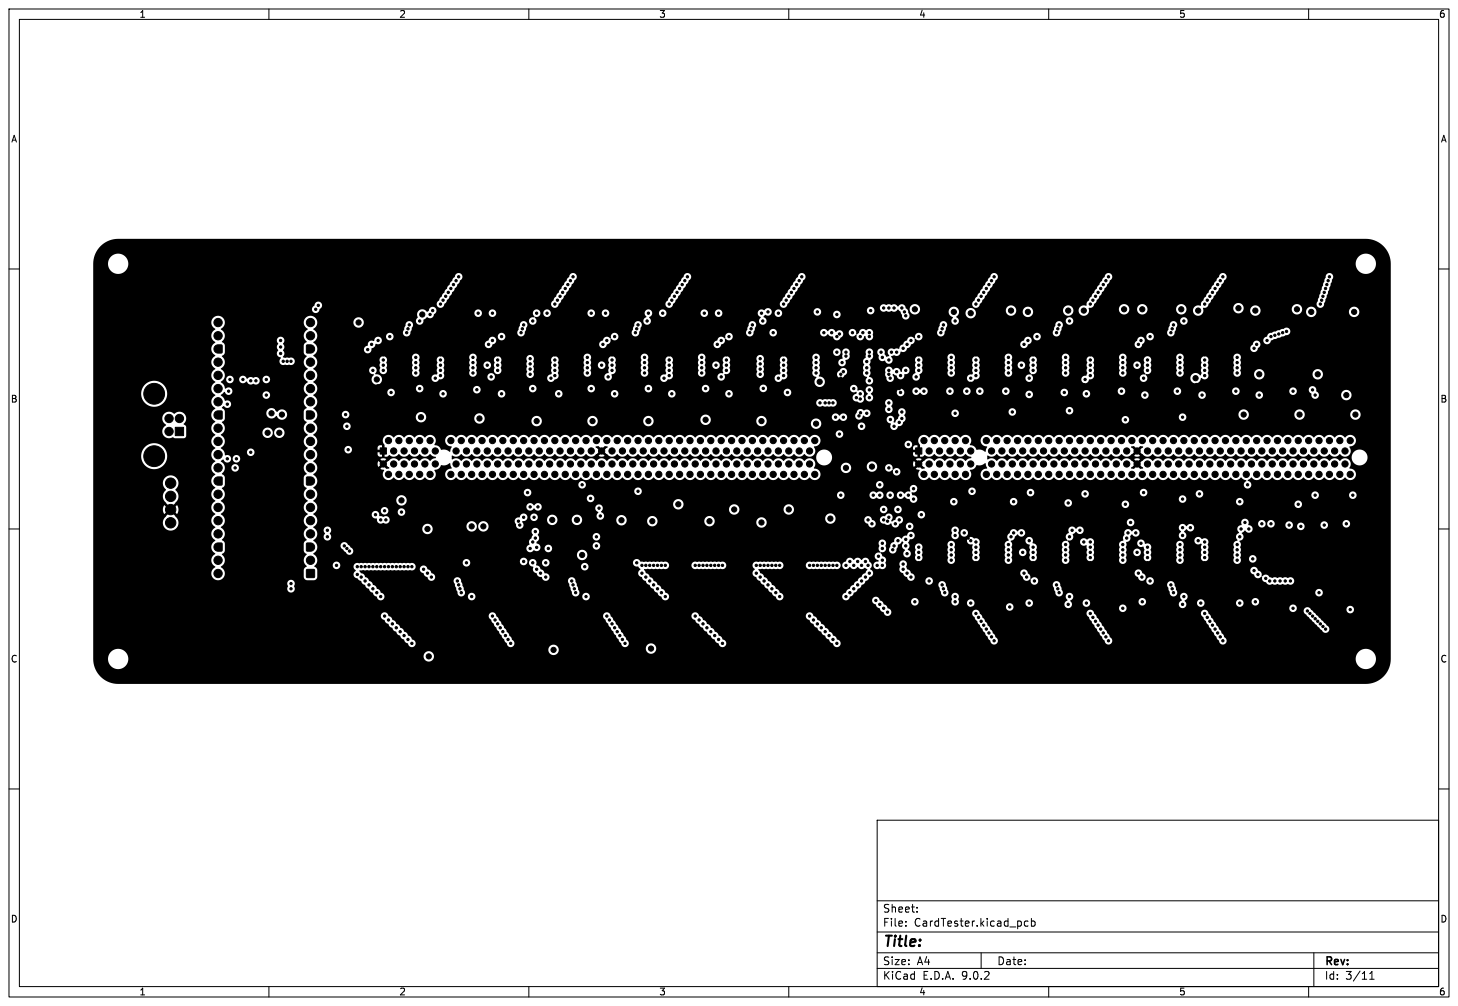
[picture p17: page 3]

Id: 3/11 Title: File: CardTester.kicad_pcb Sheet:

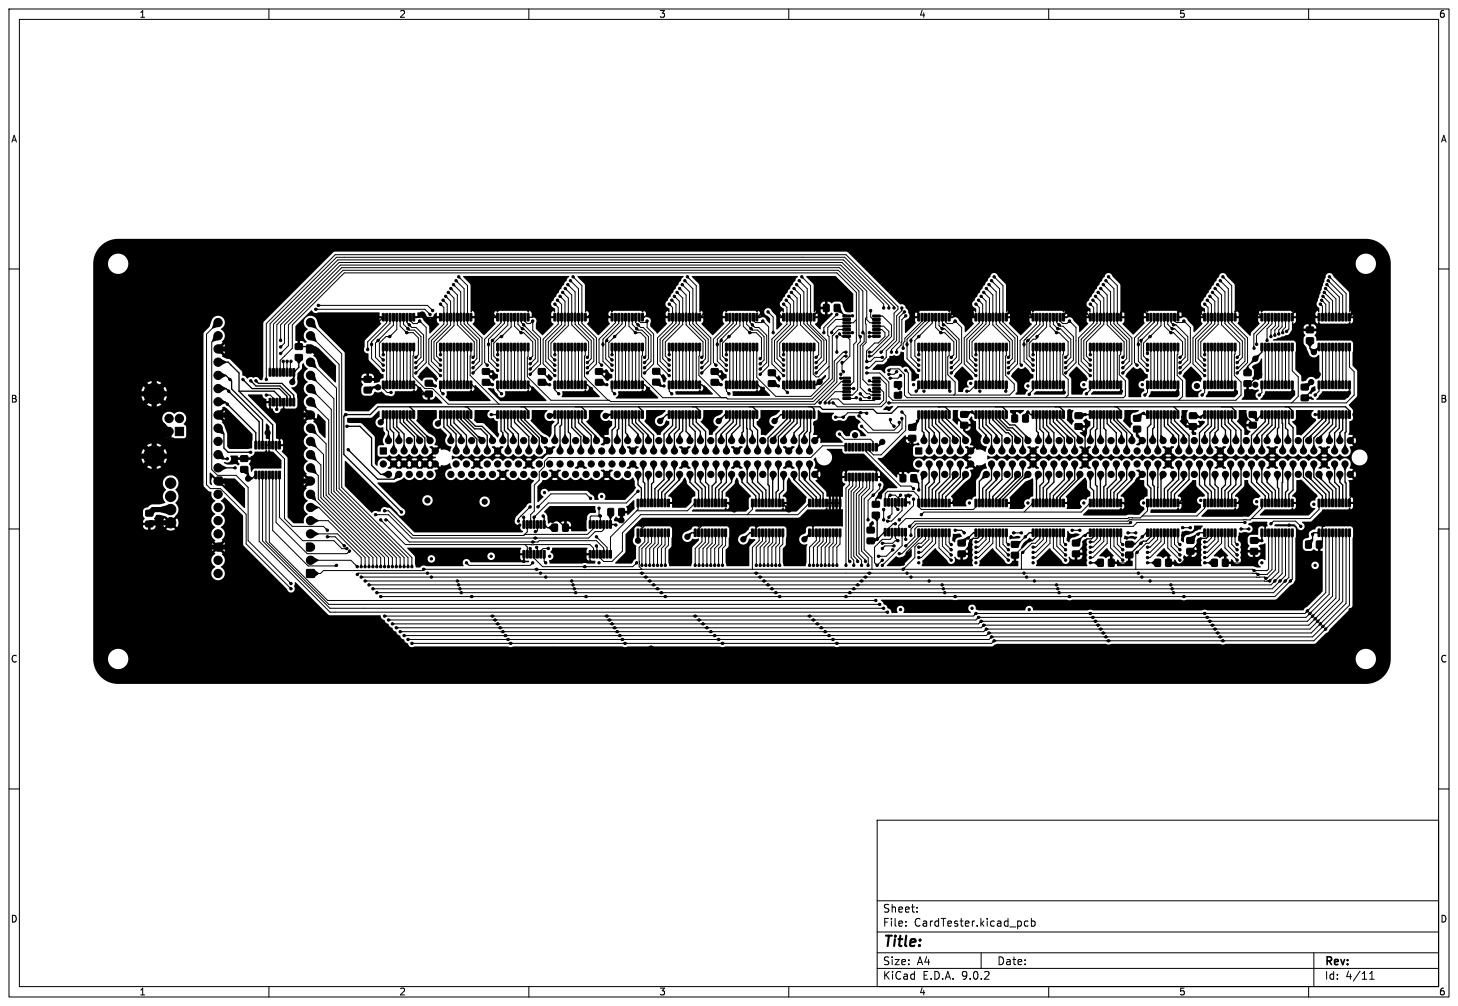
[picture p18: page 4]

Id: 4/11 Title: File: CardTester.kicad_pcb Sheet:

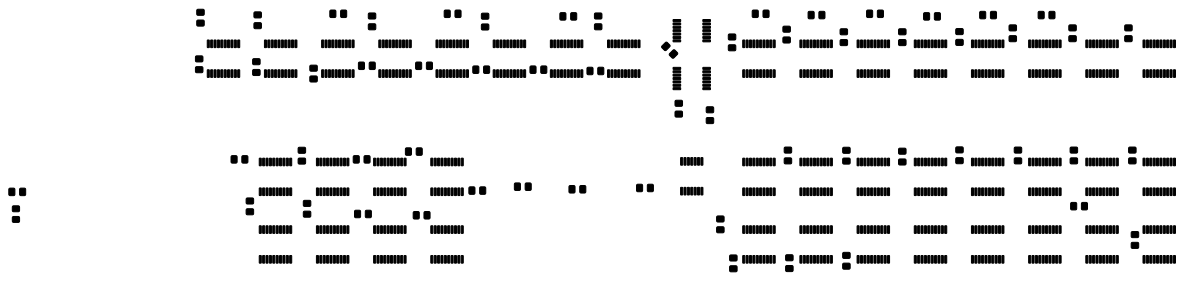
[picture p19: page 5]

Id: 5/11 Title: File: CardTester.kicad_pcb Sheet:

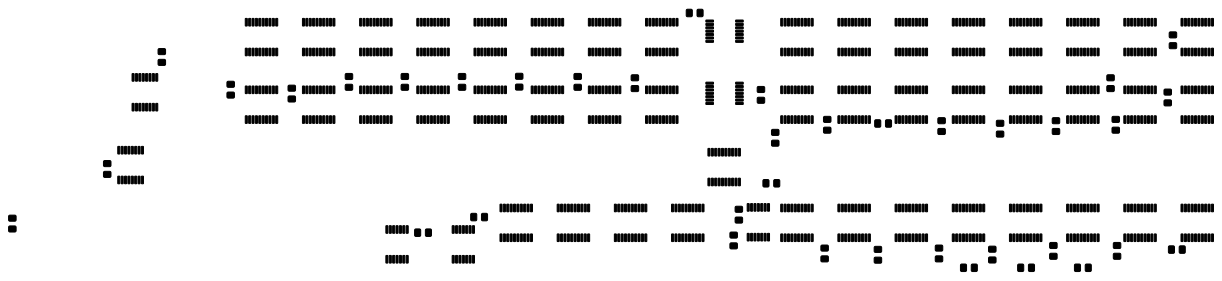
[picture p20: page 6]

Id: 6/11 Title: File: CardTester.kicad_pcb Sheet:

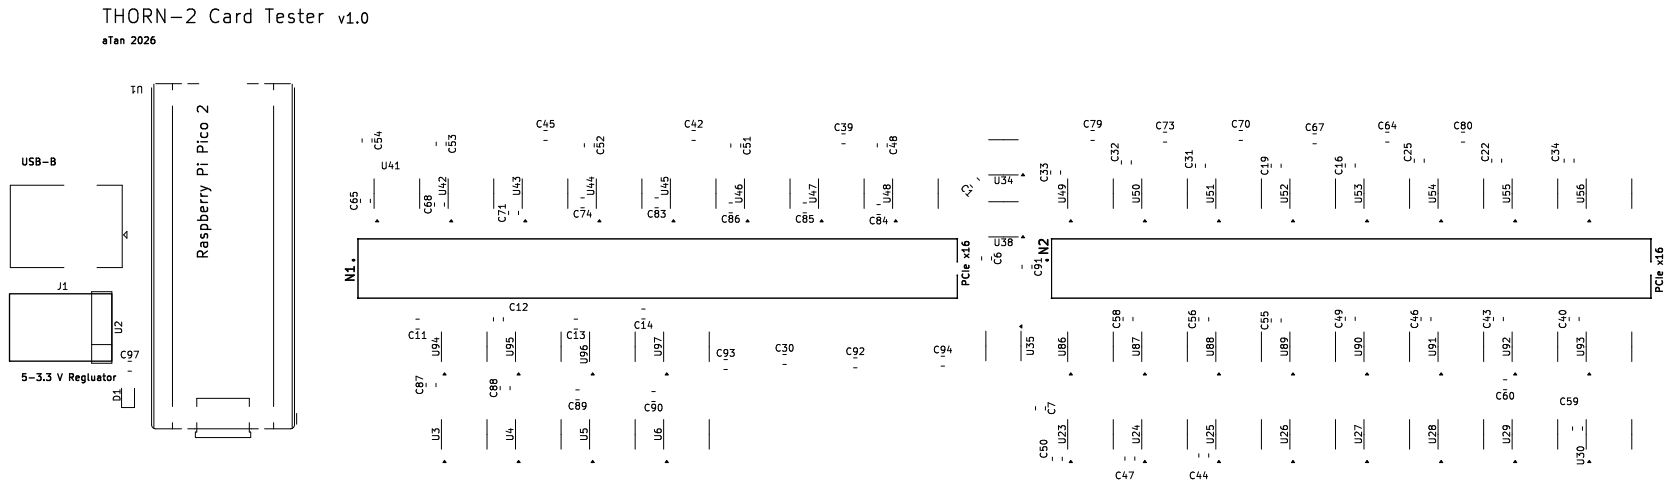
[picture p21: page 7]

Id: 7/11 Title: File: CardTester.kicad_pcb Sheet:

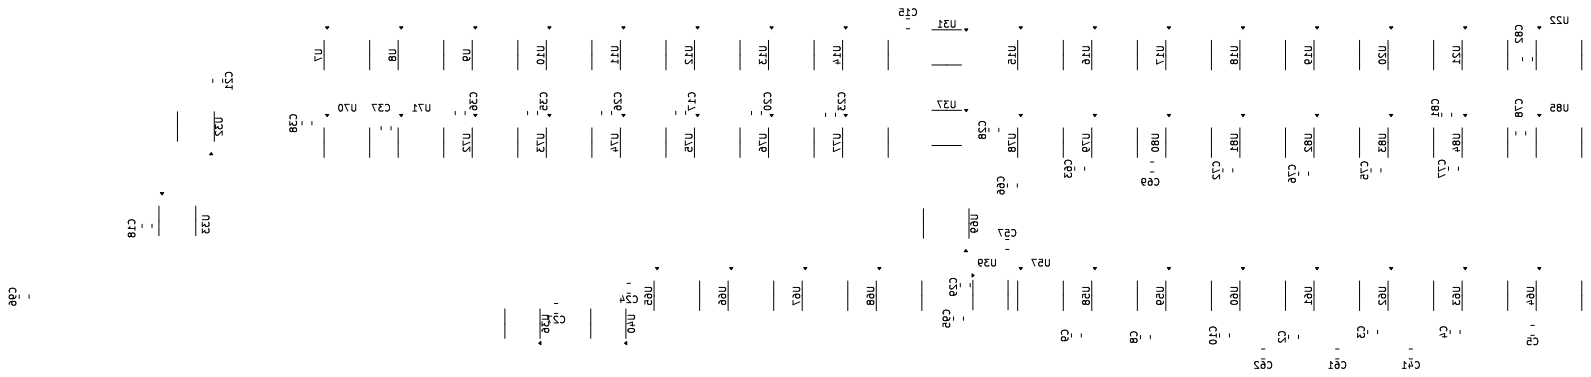
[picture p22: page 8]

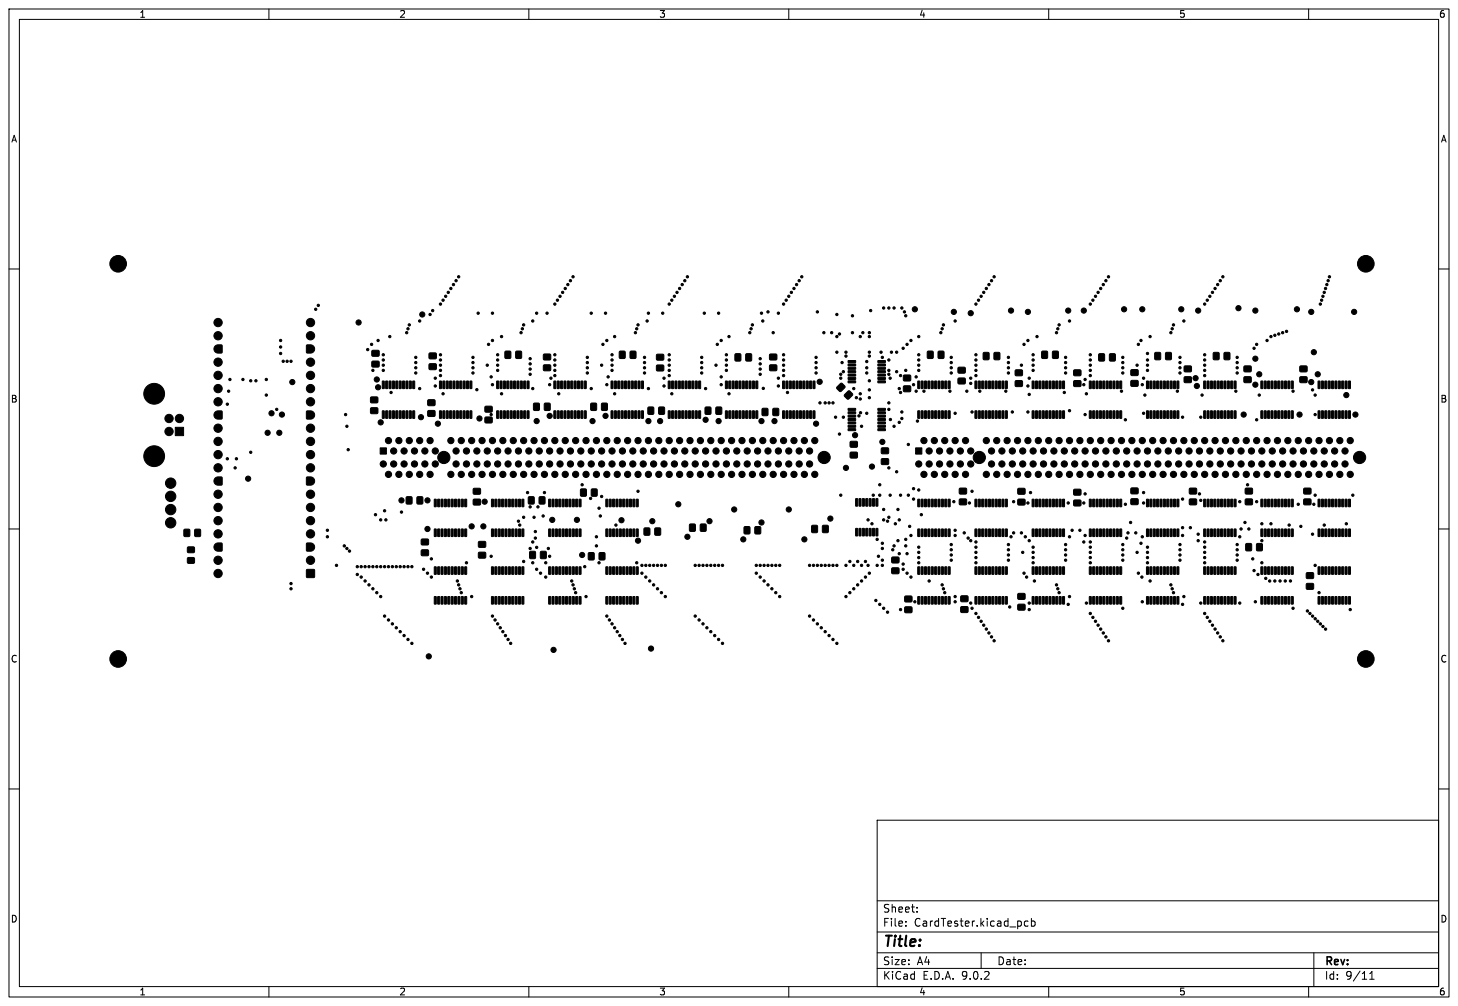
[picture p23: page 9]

Id: 9/11 Title: File: CardTester.kicad_pcb Sheet:

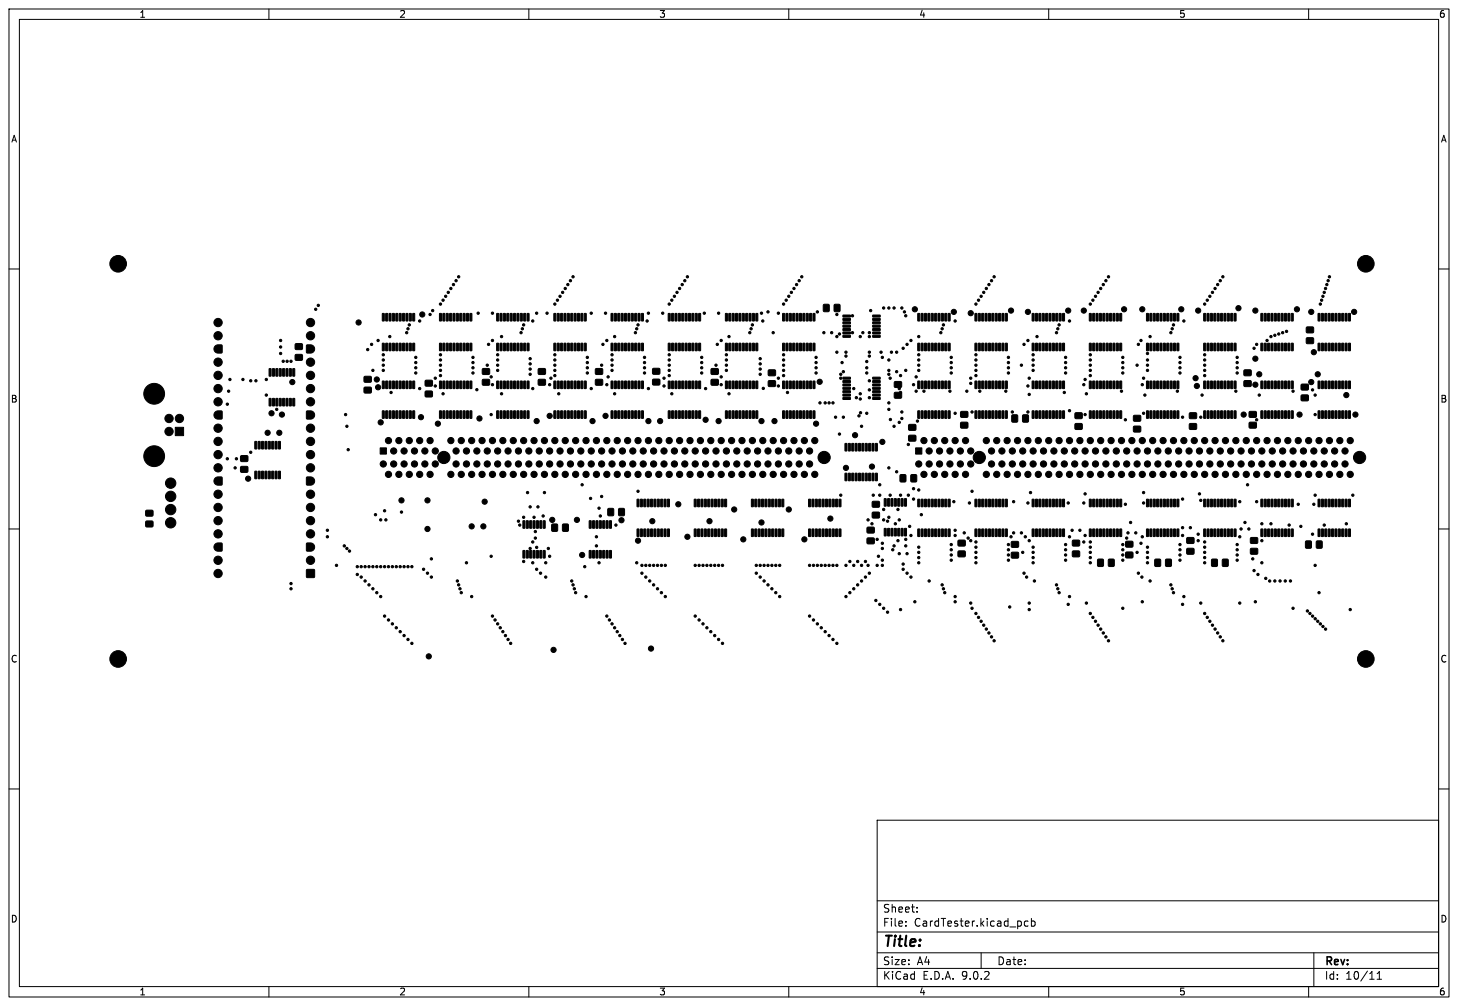
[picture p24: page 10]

Id: 10/11 Title: File: CardTester.kicad_pcb Sheet:

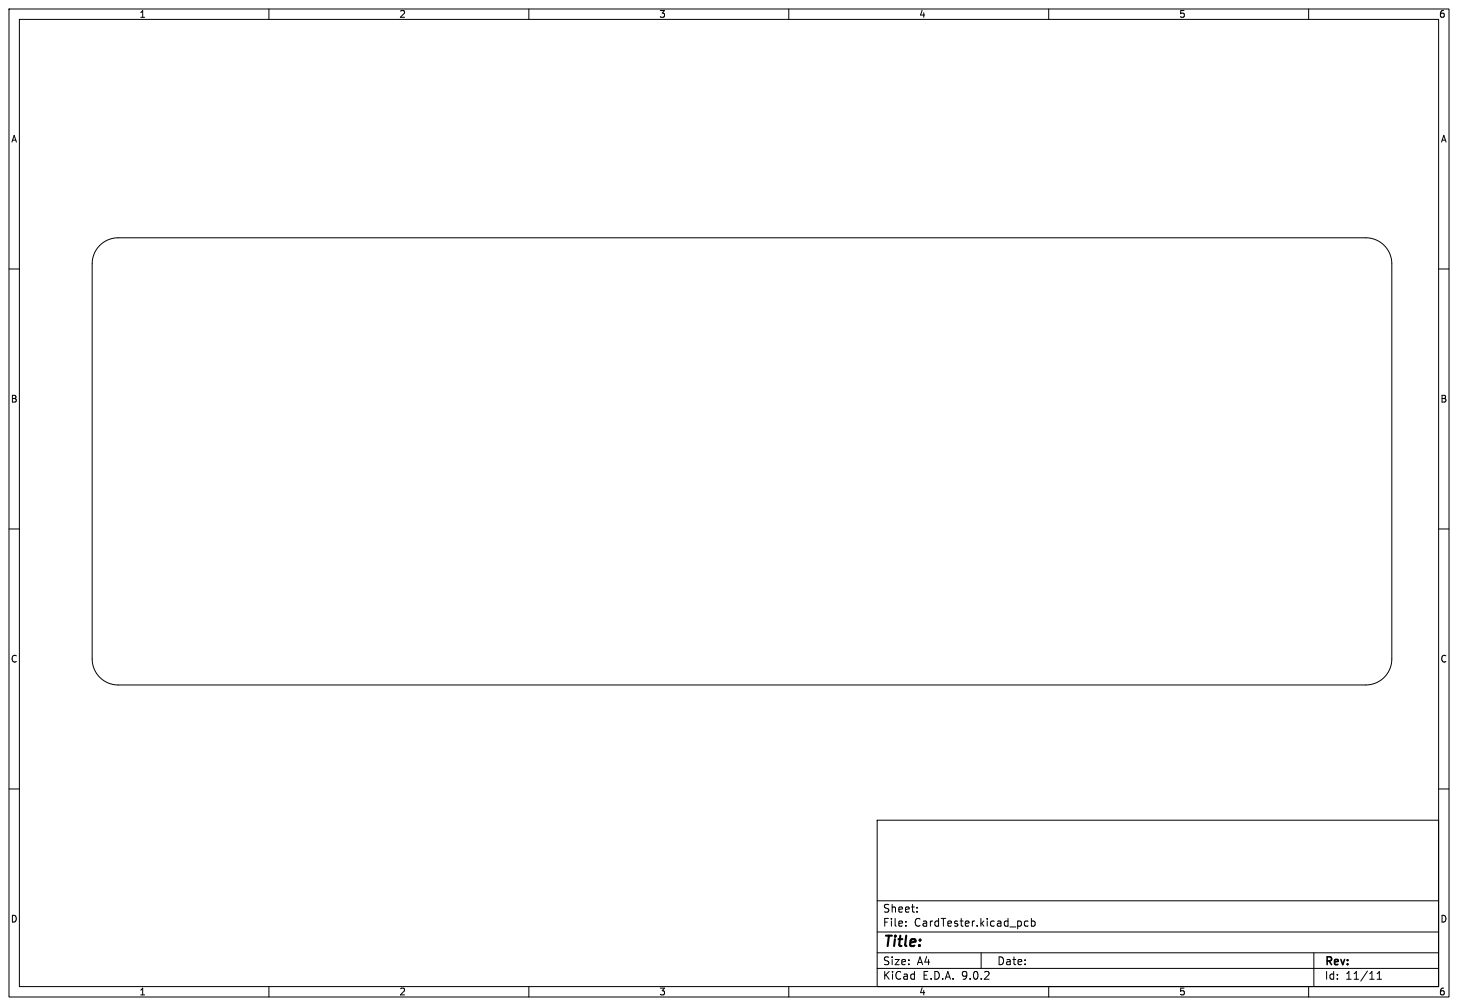
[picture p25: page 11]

Id: 11/11 Title: File: CardTester.kicad_pcb Sheet:

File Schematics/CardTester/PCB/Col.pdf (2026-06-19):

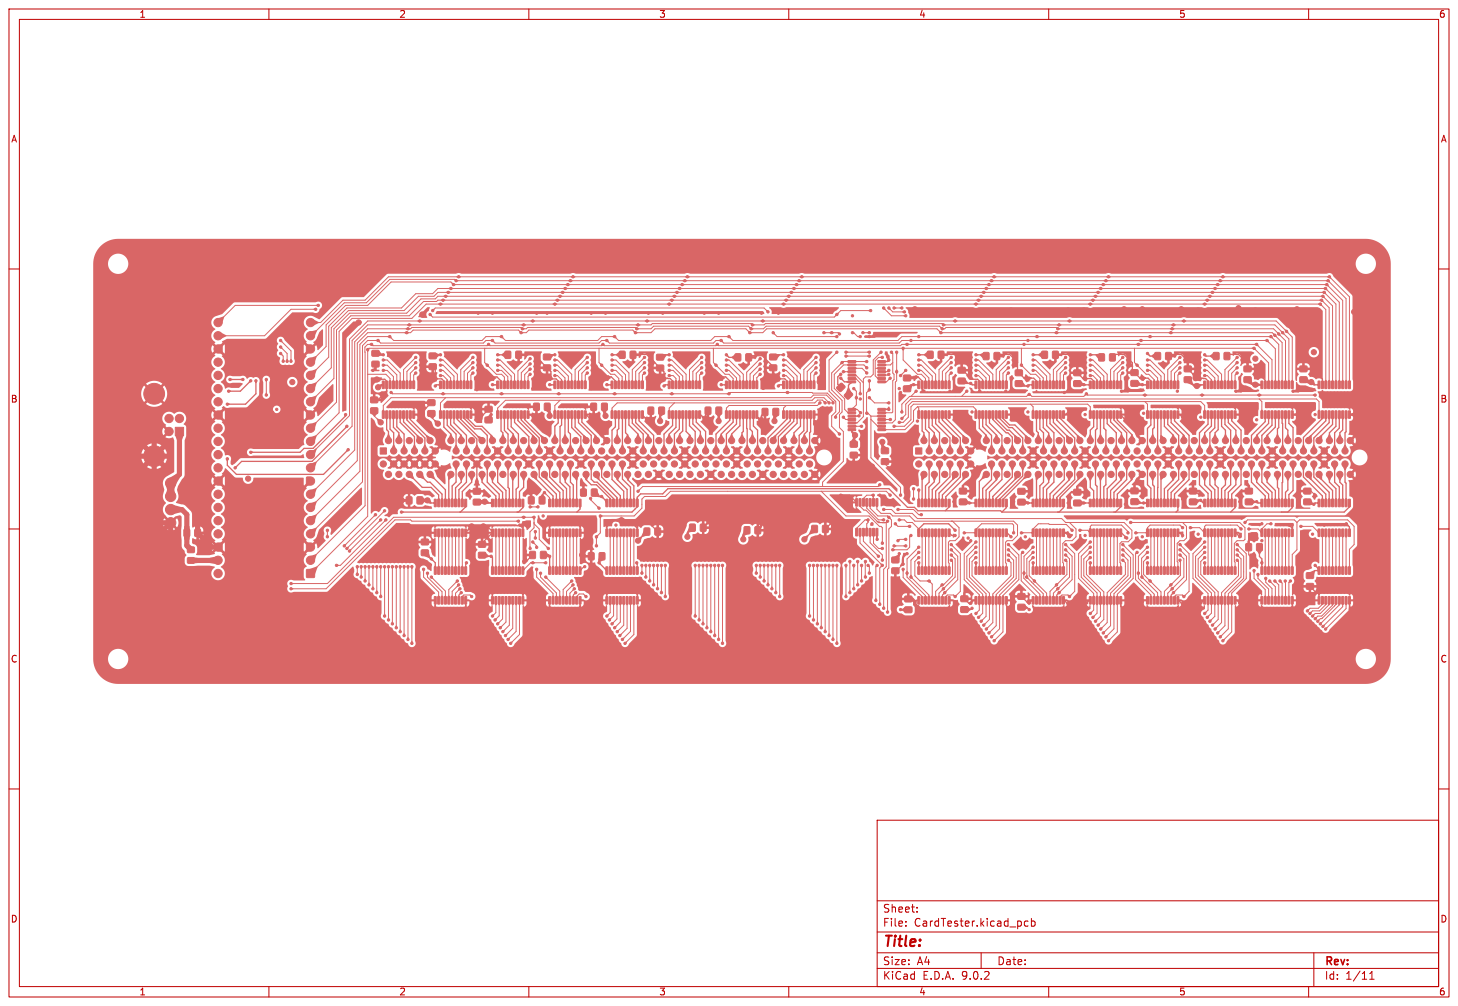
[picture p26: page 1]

Id: 1/11 Title: File: CardTester.kicad_pcb Sheet:


Id: 2/11 Title: File: CardTester.kicad_pcb Sheet:


Id: 3/11 Title: File: CardTester.kicad_pcb Sheet:


Id: 4/11 Title: File: CardTester.kicad_pcb Sheet:


Id: 5/11 Title: File: CardTester.kicad_pcb Sheet:


Id: 6/11 Title: File: CardTester.kicad_pcb Sheet:


Id: 7/11 Title: File: CardTester.kicad_pcb Sheet:



Id: 9/11 Title: File: CardTester.kicad_pcb Sheet:


Id: 10/11 Title: File: CardTester.kicad_pcb Sheet:


Id: 11/11 Title: File: CardTester.kicad_pcb Sheet:

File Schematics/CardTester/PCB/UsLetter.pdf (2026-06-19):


Id: 1/11 Title: File: CardTester.kicad_pcb Sheet:


Id: 2/11 Title: File: CardTester.kicad_pcb Sheet:


Id: 3/11 Title: File: CardTester.kicad_pcb Sheet:


Id: 4/11 Title: File: CardTester.kicad_pcb Sheet:


Id: 5/11 Title: File: CardTester.kicad_pcb Sheet:


Id: 6/11 Title: File: CardTester.kicad_pcb Sheet:


Id: 7/11 Title: File: CardTester.kicad_pcb Sheet:



Id: 9/11 Title: File: CardTester.kicad_pcb Sheet:


Id: 10/11 Title: File: CardTester.kicad_pcb Sheet:


Id: 11/11 Title: File: CardTester.kicad_pcb Sheet:

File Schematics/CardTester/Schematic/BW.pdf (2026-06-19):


IO Output Stage File: IO-Out.kicad_sch

D-OUT_[0..63] DBus Registers 1 File: D-FF.kicad_sch

~{OE} DBus Output Stage 1 File: DOutStage.kicad_sch

D-OUT_[0..63] DBus Registers 2 File: D-FF.kicad_sch

~{OE} DBus Output Stage 2 File: DOutStage.kicad_sch

~{OE_3} DBus Buffers 2 File: InBufs.kicad_sch

D-OUT_[0..63] DBus Registers 3 File: D-FF.kicad_sch D-BUS_[0..15]

~{OE} DBus Output Stage 3 File: DOutStage.kicad_sch

~{OE_3} DBus Buffers 3 File: InBufs.kicad_sch



VCC GND GND GND


VCC GND GND GND

GND
VCC GND
74LS574 VCC GND GND GND


VCC GND GND GND












D-BUS-1_45 D-BUS-1_49 D-BUS-1_48 D-BUS-1_23 D-BUS-1_24 D-BUS-1_22 D-BUS-1_1 D-BUS-1_3 D-BUS-1_20 D-BUS-1_46 D-BUS-1_59 D-BUS-1_47 D-BUS-1_51 D-BUS-1_52 D-BUS-1_50
D-BUS-1_6
IN_0 D-BUS-1_25 D-BUS-1_26 D-BUS-1_27
IN_20 D-BUS-1_10
D-BUS-1_11 D-BUS-1_33 D-BUS-1_35 D-BUS-1_34
IN_16 OUT_1 D-BUS-1_56

OUT_20 OUT_22 OUT_21 OUT_25 D-BUS-1_37
D-BUS-1_58 D-BUS-1_44 D-BUS-1_42 D-BUS-1_43 D-BUS-1_57


D-BUS-2_0 D-BUS-2_22 D-BUS-2_6
D-BUS-2_3 D-BUS-2_2 D-BUS-2_5
D-BUS-2_10 D-BUS-2_41 D-BUS-2_40
D-BUS-2_23 D-BUS-2_15 D-BUS-2_14 D-BUS-2_12 D-BUS-2_44 D-BUS-2_43 D-BUS-2_42
D-BUS-3_19 D-BUS-3_20 D-BUS-3_47 D-BUS-3_46 D-BUS-3_37 D-BUS-3_48 D-BUS-3_51 D-BUS-3_49 D-BUS-3_50 D-BUS-2_59
D-BUS-2_27 D-BUS-2_26 D-BUS-2_38 D-BUS-2_63

D-BUS-3_0 D-BUS-3_4 D-BUS-3_7 D-BUS-3_9 D-BUS-3_40 D-BUS-3_41 D-BUS-3_39

D-BUS-3_25 D-BUS-3_14 D-BUS-3_16 D-BUS-3_26 D-BUS-3_32

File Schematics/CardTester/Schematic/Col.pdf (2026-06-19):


IO Output Stage File: IO-Out.kicad_sch

D-OUT_[0..63] DBus Registers 1 File: D-FF.kicad_sch

~{OE} DBus Output Stage 1 File: DOutStage.kicad_sch

D-OUT_[0..63] DBus Registers 2 File: D-FF.kicad_sch

~{OE} DBus Output Stage 2 File: DOutStage.kicad_sch

~{OE_3} DBus Buffers 2 File: InBufs.kicad_sch

D-OUT_[0..63] DBus Registers 3 File: D-FF.kicad_sch D-BUS_[0..15]

~{OE} DBus Output Stage 3 File: DOutStage.kicad_sch

~{OE_3} DBus Buffers 3 File: InBufs.kicad_sch



VCC GND GND GND

GND
VCC GND
74LS574 VCC GND GND GND


VCC GND GND GND


VCC GND GND GND

GND
VCC GND
74LS574 VCC GND GND GND






VCC GND GND GND







D-BUS-1_45 D-BUS-1_49 D-BUS-1_48 D-BUS-1_23 D-BUS-1_24 D-BUS-1_22 D-BUS-1_1 D-BUS-1_3 D-BUS-1_20 D-BUS-1_46 D-BUS-1_59 D-BUS-1_47 D-BUS-1_51 D-BUS-1_52 D-BUS-1_50
D-BUS-1_6
IN_0 D-BUS-1_25 D-BUS-1_26 D-BUS-1_27
IN_20 D-BUS-1_10
D-BUS-1_11 D-BUS-1_33 D-BUS-1_35 D-BUS-1_34
IN_16 OUT_1 D-BUS-1_56

OUT_20 OUT_22 OUT_21 OUT_25 D-BUS-1_37
D-BUS-1_58 D-BUS-1_44 D-BUS-1_42 D-BUS-1_43 D-BUS-1_57


D-BUS-2_0 D-BUS-2_22 D-BUS-2_6
D-BUS-2_3 D-BUS-2_2 D-BUS-2_5
D-BUS-2_10 D-BUS-2_41 D-BUS-2_40
D-BUS-2_23 D-BUS-2_15 D-BUS-2_14 D-BUS-2_12 D-BUS-2_44 D-BUS-2_43 D-BUS-2_42
D-BUS-3_19 D-BUS-3_20 D-BUS-3_47 D-BUS-3_46 D-BUS-3_37 D-BUS-3_48 D-BUS-3_51 D-BUS-3_49 D-BUS-3_50 D-BUS-2_59
D-BUS-2_27 D-BUS-2_26 D-BUS-2_38 D-BUS-2_63

D-BUS-3_0 D-BUS-3_4 D-BUS-3_7 D-BUS-3_9 D-BUS-3_40 D-BUS-3_41 D-BUS-3_39

D-BUS-3_25 D-BUS-3_14 D-BUS-3_16 D-BUS-3_26 D-BUS-3_32

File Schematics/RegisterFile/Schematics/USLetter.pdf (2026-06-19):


Id: 1/9 Title: Register PCB Layout File: RegisterFile.kicad_pcb Sheet:


Id: 2/9 Title: Register PCB Layout File: RegisterFile.kicad_pcb Sheet:


Id: 3/9 Title: Register PCB Layout File: RegisterFile.kicad_pcb Sheet:


Id: 4/9 Title: Register PCB Layout File: RegisterFile.kicad_pcb Sheet:


Id: 5/9 Title: Register PCB Layout File: RegisterFile.kicad_pcb Sheet:


Id: 6/9 Title: Register PCB Layout File: RegisterFile.kicad_pcb Sheet:


Id: 7/9 Title: Register PCB Layout File: RegisterFile.kicad_pcb Sheet:


Id: 8/9 Title: Register PCB Layout File: RegisterFile.kicad_pcb Sheet:


Id: 9/9 Title: Register PCB Layout File: RegisterFile.kicad_pcb Sheet:















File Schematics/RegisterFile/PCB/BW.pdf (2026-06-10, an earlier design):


Id: 1/9 Title: Register PCB Layout File: RegisterFile.kicad_pcb Sheet:


Id: 2/9 Title: Register PCB Layout File: RegisterFile.kicad_pcb Sheet:


Id: 3/9 Title: Register PCB Layout File: RegisterFile.kicad_pcb Sheet:


Id: 4/9 Title: Register PCB Layout File: RegisterFile.kicad_pcb Sheet:


Id: 5/9 Title: Register PCB Layout File: RegisterFile.kicad_pcb Sheet:


Id: 6/9 Title: Register PCB Layout File: RegisterFile.kicad_pcb Sheet:


Id: 7/9 Title: Register PCB Layout File: RegisterFile.kicad_pcb Sheet:


Id: 8/9 Title: Register PCB Layout File: RegisterFile.kicad_pcb Sheet:


Id: 9/9 Title: Register PCB Layout File: RegisterFile.kicad_pcb Sheet:

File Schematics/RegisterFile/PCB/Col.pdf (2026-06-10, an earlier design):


Id: 1/9 Title: Register PCB Layout File: RegisterFile.kicad_pcb Sheet:


Id: 2/9 Title: Register PCB Layout File: RegisterFile.kicad_pcb Sheet:


Id: 3/9 Title: Register PCB Layout File: RegisterFile.kicad_pcb Sheet:


Id: 4/9 Title: Register PCB Layout File: RegisterFile.kicad_pcb Sheet:


Id: 5/9 Title: Register PCB Layout File: RegisterFile.kicad_pcb Sheet:


Id: 6/9 Title: Register PCB Layout File: RegisterFile.kicad_pcb Sheet:


Id: 7/9 Title: Register PCB Layout File: RegisterFile.kicad_pcb Sheet:


Id: 8/9 Title: Register PCB Layout File: RegisterFile.kicad_pcb Sheet:


Id: 9/9 Title: Register PCB Layout File: RegisterFile.kicad_pcb Sheet:

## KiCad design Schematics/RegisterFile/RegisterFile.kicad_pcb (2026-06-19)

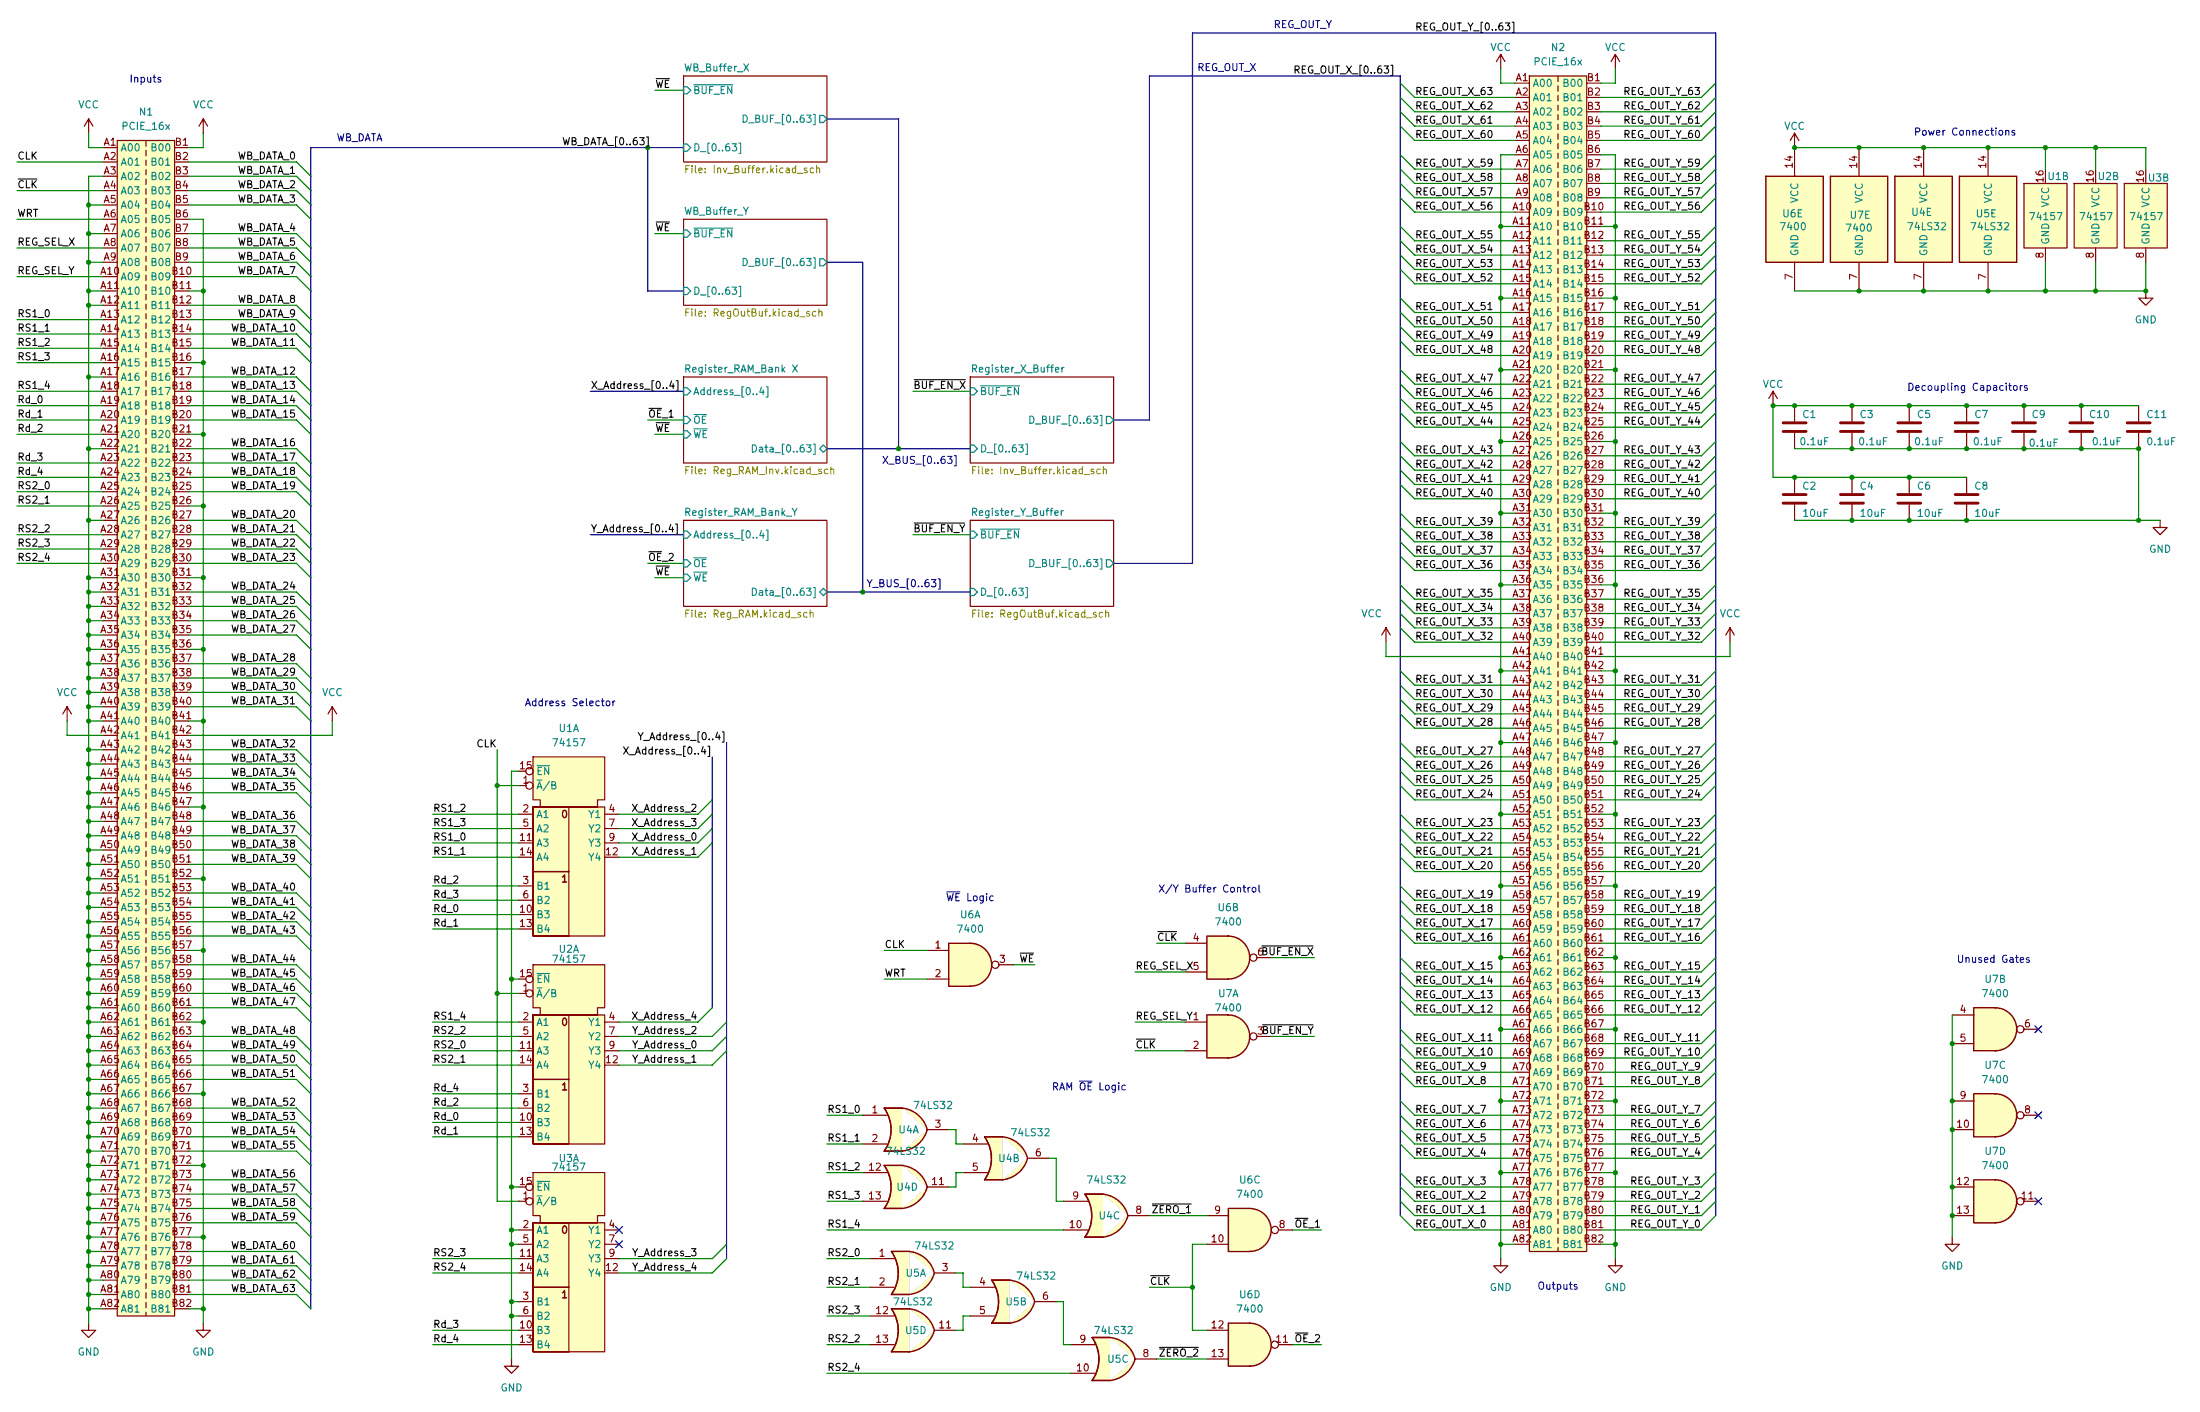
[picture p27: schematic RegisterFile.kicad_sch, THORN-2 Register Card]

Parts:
C1, C3, C5, C7, C9, C10, C11: 0.1uF; C_1206_3216Metric
C2, C4, C6, C8: 10uF; C_1206_3216Metric
N1, N2: PCIE_16x; BUS_PCIexpress_x16
U1, U2, U3: 74157; SOIC-16_3.9x9.9mm_P1.27mm
U4, U5: 74LS32; TSSOP-14_4.4x5mm_P0.65mm
U6, U7: 7400; TSSOP-14_4.4x5mm_P0.65mm

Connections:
/CLK: N1.A2 (A01), U1.1 (~A/B), U2.1 (~A/B), U3.1 (~A/B), U6.1
/REG_OUT_X_0: N2.A81 (A80); also elsewhere on the board
/REG_OUT_X_1: N2.A80 (A79); also elsewhere on the board
/REG_OUT_X_2: N2.A79 (A78); also elsewhere on the board
/REG_OUT_X_3: N2.A78 (A77); also elsewhere on the board
/REG_OUT_X_4: N2.A76 (A75); also elsewhere on the board
/REG_OUT_X_5: N2.A75 (A74); also elsewhere on the board
/REG_OUT_X_6: N2.A74 (A73); also elsewhere on the board
/REG_OUT_X_7: N2.A73 (A72); also elsewhere on the board
/REG_OUT_X_8: N2.A71 (A70); also elsewhere on the board
/REG_OUT_X_9: N2.A70 (A69); also elsewhere on the board
/REG_OUT_X_10: N2.A69 (A68); also elsewhere on the board
/REG_OUT_X_11: N2.A68 (A67); also elsewhere on the board
/REG_OUT_X_12: N2.A66 (A65); also elsewhere on the board
/REG_OUT_X_13: N2.A65 (A64); also elsewhere on the board
/REG_OUT_X_14: N2.A64 (A63); also elsewhere on the board
/REG_OUT_X_15: N2.A63 (A62); also elsewhere on the board
/REG_OUT_X_16: N2.A61 (A60); also elsewhere on the board
/REG_OUT_X_17: N2.A60 (A59); also elsewhere on the board
/REG_OUT_X_18: N2.A59 (A58); also elsewhere on the board
/REG_OUT_X_19: N2.A58 (A57); also elsewhere on the board
/REG_OUT_X_20: N2.A56 (A55); also elsewhere on the board
/REG_OUT_X_21: N2.A55 (A54); also elsewhere on the board
/REG_OUT_X_22: N2.A54 (A53); also elsewhere on the board
/REG_OUT_X_23: N2.A53 (A52); also elsewhere on the board
/REG_OUT_X_24: N2.A51 (A50); also elsewhere on the board
/REG_OUT_X_25: N2.A50 (A49); also elsewhere on the board
/REG_OUT_X_26: N2.A49 (A48); also elsewhere on the board
/REG_OUT_X_27: N2.A48 (A47); also elsewhere on the board
/REG_OUT_X_28: N2.A46 (A45); also elsewhere on the board
/REG_OUT_X_29: N2.A45 (A44); also elsewhere on the board
/REG_OUT_X_30: N2.A44 (A43); also elsewhere on the board
/REG_OUT_X_31: N2.A43 (A42); also elsewhere on the board
/REG_OUT_X_32: N2.A40 (A39); also elsewhere on the board
/REG_OUT_X_33: N2.A39 (A38); also elsewhere on the board
/REG_OUT_X_34: N2.A38 (A37); also elsewhere on the board
/REG_OUT_X_35: N2.A37 (A36); also elsewhere on the board
/REG_OUT_X_36: N2.A35 (A34); also elsewhere on the board
/REG_OUT_X_37: N2.A34 (A33); also elsewhere on the board
/REG_OUT_X_38: N2.A33 (A32); also elsewhere on the board
/REG_OUT_X_39: N2.A32 (A31); also elsewhere on the board
/REG_OUT_X_40: N2.A30 (A29); also elsewhere on the board
/REG_OUT_X_41: N2.A29 (A28); also elsewhere on the board
/REG_OUT_X_42: N2.A28 (A27); also elsewhere on the board
/REG_OUT_X_43: N2.A27 (A26); also elsewhere on the board
/REG_OUT_X_44: N2.A25 (A24); also elsewhere on the board
/REG_OUT_X_45: N2.A24 (A23); also elsewhere on the board
/REG_OUT_X_46: N2.A23 (A22); also elsewhere on the board
/REG_OUT_X_47: N2.A22 (A21); also elsewhere on the board
/REG_OUT_X_48: N2.A20 (A19); also elsewhere on the board
/REG_OUT_X_49: N2.A19 (A18); also elsewhere on the board
/REG_OUT_X_50: N2.A18 (A17); also elsewhere on the board
/REG_OUT_X_51: N2.A17 (A16); also elsewhere on the board
/REG_OUT_X_52: N2.A15 (A14); also elsewhere on the board
/REG_OUT_X_53: N2.A14 (A13); also elsewhere on the board
/REG_OUT_X_54: N2.A13 (A12); also elsewhere on the board
/REG_OUT_X_55: N2.A12 (A11); also elsewhere on the board
/REG_OUT_X_56: N2.A10 (A09); also elsewhere on the board
/REG_OUT_X_57: N2.A9 (A08); also elsewhere on the board
/REG_OUT_X_58: N2.A8 (A07); also elsewhere on the board
/REG_OUT_X_59: N2.A7 (A06); also elsewhere on the board
/REG_OUT_X_60: N2.A5 (A04); also elsewhere on the board
/REG_OUT_X_61: N2.A4 (A03); also elsewhere on the board
/REG_OUT_X_62: N2.A3 (A02); also elsewhere on the board
/REG_OUT_X_63: N2.A2 (A01); also elsewhere on the board
/REG_OUT_Y_0: N2.B81 (B80); also elsewhere on the board
/REG_OUT_Y_1: N2.B80 (B79); also elsewhere on the board
/REG_OUT_Y_2: N2.B79 (B78); also elsewhere on the board
/REG_OUT_Y_3: N2.B78 (B77); also elsewhere on the board
/REG_OUT_Y_4: N2.B76 (B75); also elsewhere on the board
/REG_OUT_Y_5: N2.B75 (B74); also elsewhere on the board
/REG_OUT_Y_6: N2.B74 (B73); also elsewhere on the board
/REG_OUT_Y_7: N2.B73 (B72); also elsewhere on the board
/REG_OUT_Y_8: N2.B71 (B70); also elsewhere on the board
/REG_OUT_Y_9: N2.B70 (B69); also elsewhere on the board
/REG_OUT_Y_10: N2.B69 (B68); also elsewhere on the board
/REG_OUT_Y_11: N2.B68 (B67); also elsewhere on the board
/REG_OUT_Y_12: N2.B66 (B65); also elsewhere on the board
/REG_OUT_Y_13: N2.B65 (B64); also elsewhere on the board
/REG_OUT_Y_14: N2.B64 (B63); also elsewhere on the board
/REG_OUT_Y_15: N2.B63 (B62); also elsewhere on the board
/REG_OUT_Y_16: N2.B61 (B60); also elsewhere on the board
/REG_OUT_Y_17: N2.B60 (B59); also elsewhere on the board
/REG_OUT_Y_18: N2.B59 (B58); also elsewhere on the board
/REG_OUT_Y_19: N2.B58 (B57); also elsewhere on the board
/REG_OUT_Y_20: N2.B56 (B55); also elsewhere on the board
/REG_OUT_Y_21: N2.B55 (B54); also elsewhere on the board
/REG_OUT_Y_22: N2.B54 (B53); also elsewhere on the board
/REG_OUT_Y_23: N2.B53 (B52); also elsewhere on the board
/REG_OUT_Y_24: N2.B51 (B50); also elsewhere on the board
/REG_OUT_Y_25: N2.B50 (B49); also elsewhere on the board
/REG_OUT_Y_26: N2.B49 (B48); also elsewhere on the board
/REG_OUT_Y_27: N2.B48 (B47); also elsewhere on the board
/REG_OUT_Y_28: N2.B46 (B45); also elsewhere on the board
/REG_OUT_Y_29: N2.B45 (B44); also elsewhere on the board
/REG_OUT_Y_30: N2.B44 (B43); also elsewhere on the board
/REG_OUT_Y_31: N2.B43 (B42); also elsewhere on the board
/REG_OUT_Y_32: N2.B40 (B39); also elsewhere on the board
/REG_OUT_Y_33: N2.B39 (B38); also elsewhere on the board
/REG_OUT_Y_34: N2.B38 (B37); also elsewhere on the board
/REG_OUT_Y_35: N2.B37 (B36); also elsewhere on the board
/REG_OUT_Y_36: N2.B35 (B34); also elsewhere on the board
/REG_OUT_Y_37: N2.B34 (B33); also elsewhere on the board
/REG_OUT_Y_38: N2.B33 (B32); also elsewhere on the board
/REG_OUT_Y_39: N2.B32 (B31); also elsewhere on the board
/REG_OUT_Y_40: N2.B30 (B29); also elsewhere on the board
/REG_OUT_Y_41: N2.B29 (B28); also elsewhere on the board
/REG_OUT_Y_42: N2.B28 (B27); also elsewhere on the board
/REG_OUT_Y_43: N2.B27 (B26); also elsewhere on the board
/REG_OUT_Y_44: N2.B25 (B24); also elsewhere on the board
/REG_OUT_Y_45: N2.B24 (B23); also elsewhere on the board
/REG_OUT_Y_46: N2.B23 (B22); also elsewhere on the board
/REG_OUT_Y_47: N2.B22 (B21); also elsewhere on the board
/REG_OUT_Y_48: N2.B20 (B19); also elsewhere on the board
/REG_OUT_Y_49: N2.B19 (B18); also elsewhere on the board
/REG_OUT_Y_50: N2.B18 (B17); also elsewhere on the board
/REG_OUT_Y_51: N2.B17 (B16); also elsewhere on the board
/REG_OUT_Y_52: N2.B15 (B14); also elsewhere on the board
/REG_OUT_Y_53: N2.B14 (B13); also elsewhere on the board
/REG_OUT_Y_54: N2.B13 (B12); also elsewhere on the board
/REG_OUT_Y_55: N2.B12 (B11); also elsewhere on the board
/REG_OUT_Y_56: N2.B10 (B09); also elsewhere on the board
/REG_OUT_Y_57: N2.B9 (B08); also elsewhere on the board
/REG_OUT_Y_58: N2.B8 (B07); also elsewhere on the board
/REG_OUT_Y_59: N2.B7 (B06); also elsewhere on the board
/REG_OUT_Y_60: N2.B5 (B04); also elsewhere on the board
/REG_OUT_Y_61: N2.B4 (B03); also elsewhere on the board
/REG_OUT_Y_62: N2.B3 (B02); also elsewhere on the board
/REG_OUT_Y_63: N2.B2 (B01); also elsewhere on the board
/REG_SEL_X: N1.A8 (A07), U6.5
/REG_SEL_Y: N1.A10 (A09), U7.1
/RS1_0: N1.A13 (A12), U1.11 (A3), U4.1
/RS1_1: N1.A14 (A13), U1.14 (A4), U4.2
/RS1_2: N1.A15 (A14), U1.2 (A1), U4.12
/RS1_3: N1.A16 (A15), U1.5 (A2), U4.13
/RS1_4: N1.A18 (A17), U2.2 (A1), U4.10
/RS2_0: N1.A25 (A24), U2.11 (A3), U5.1
/RS2_1: N1.A26 (A25), U2.14 (A4), U5.2
/RS2_2: N1.A28 (A27), U2.5 (A2), U5.13
/RS2_3: N1.A29 (A28), U3.11 (A3), U5.12
/RS2_4: N1.A30 (A29), U3.14 (A4), U5.10
/Rd_0: N1.A19 (A18), U1.10 (B3), U2.10 (B3)
/Rd_1: N1.A20 (A19), U1.13 (B4), U2.13 (B4)
/Rd_2: N1.A21 (A20), U1.3 (B1), U2.6 (B2)
/Rd_3: N1.A23 (A22), U1.6 (B2), U3.10 (B3)
/Rd_4: N1.A24 (A23), U2.3 (B1), U3.13 (B4)
/WB_DATA_0: N1.B2 (B01); also elsewhere on the board
/WB_DATA_1: N1.B3 (B02); also elsewhere on the board
/WB_DATA_2: N1.B4 (B03); also elsewhere on the board
/WB_DATA_3: N1.B5 (B04); also elsewhere on the board
/WB_DATA_4: N1.B7 (B06); also elsewhere on the board
/WB_DATA_5: N1.B8 (B07); also elsewhere on the board
/WB_DATA_6: N1.B9 (B08); also elsewhere on the board
/WB_DATA_7: N1.B10 (B09); also elsewhere on the board
/WB_DATA_8: N1.B12 (B11); also elsewhere on the board
/WB_DATA_9: N1.B13 (B12); also elsewhere on the board
/WB_DATA_10: N1.B14 (B13); also elsewhere on the board
/WB_DATA_11: N1.B15 (B14); also elsewhere on the board
/WB_DATA_12: N1.B17 (B16); also elsewhere on the board
/WB_DATA_13: N1.B18 (B17); also elsewhere on the board
/WB_DATA_14: N1.B19 (B18); also elsewhere on the board
/WB_DATA_15: N1.B20 (B19); also elsewhere on the board
/WB_DATA_16: N1.B22 (B21); also elsewhere on the board
/WB_DATA_17: N1.B23 (B22); also elsewhere on the board
/WB_DATA_18: N1.B24 (B23); also elsewhere on the board
/WB_DATA_19: N1.B25 (B24); also elsewhere on the board
/WB_DATA_20: N1.B27 (B26); also elsewhere on the board
/WB_DATA_21: N1.B28 (B27); also elsewhere on the board
/WB_DATA_22: N1.B29 (B28); also elsewhere on the board
/WB_DATA_23: N1.B30 (B29); also elsewhere on the board
/WB_DATA_24: N1.B32 (B31); also elsewhere on the board
/WB_DATA_25: N1.B33 (B32); also elsewhere on the board
/WB_DATA_26: N1.B34 (B33); also elsewhere on the board
/WB_DATA_27: N1.B35 (B34); also elsewhere on the board
/WB_DATA_28: N1.B37 (B36); also elsewhere on the board
/WB_DATA_29: N1.B38 (B37); also elsewhere on the board
/WB_DATA_30: N1.B39 (B38); also elsewhere on the board
/WB_DATA_31: N1.B40 (B39); also elsewhere on the board
/WB_DATA_32: N1.B43 (B42); also elsewhere on the board
/WB_DATA_33: N1.B44 (B43); also elsewhere on the board
/WB_DATA_34: N1.B45 (B44); also elsewhere on the board
/WB_DATA_35: N1.B46 (B45); also elsewhere on the board
/WB_DATA_36: N1.B48 (B47); also elsewhere on the board
/WB_DATA_37: N1.B49 (B48); also elsewhere on the board
/WB_DATA_38: N1.B50 (B49); also elsewhere on the board
/WB_DATA_39: N1.B51 (B50); also elsewhere on the board
/WB_DATA_40: N1.B53 (B52); also elsewhere on the board
/WB_DATA_41: N1.B54 (B53); also elsewhere on the board
/WB_DATA_42: N1.B55 (B54); also elsewhere on the board
/WB_DATA_43: N1.B56 (B55); also elsewhere on the board
/WB_DATA_44: N1.B58 (B57); also elsewhere on the board
/WB_DATA_45: N1.B59 (B58); also elsewhere on the board
/WB_DATA_46: N1.B60 (B59); also elsewhere on the board
/WB_DATA_47: N1.B61 (B60); also elsewhere on the board
/WB_DATA_48: N1.B63 (B62); also elsewhere on the board
/WB_DATA_49: N1.B64 (B63); also elsewhere on the board
/WB_DATA_50: N1.B65 (B64); also elsewhere on the board
/WB_DATA_51: N1.B66 (B65); also elsewhere on the board
/WB_DATA_52: N1.B68 (B67); also elsewhere on the board
/WB_DATA_53: N1.B69 (B68); also elsewhere on the board
/WB_DATA_54: N1.B70 (B69); also elsewhere on the board
/WB_DATA_55: N1.B71 (B70); also elsewhere on the board
/WB_DATA_56: N1.B73 (B72); also elsewhere on the board
/WB_DATA_57: N1.B74 (B73); also elsewhere on the board
/WB_DATA_58: N1.B75 (B74); also elsewhere on the board
/WB_DATA_59: N1.B76 (B75); also elsewhere on the board
/WB_DATA_60: N1.B78 (B77); also elsewhere on the board
/WB_DATA_61: N1.B79 (B78); also elsewhere on the board
/WB_DATA_62: N1.B80 (B79); also elsewhere on the board
/WB_DATA_63: N1.B81 (B80); also elsewhere on the board
/WRT: N1.A6 (A05), U6.2
/X_Address_0: U1.9 (Y3); also elsewhere on the board
/X_Address_1: U1.12 (Y4); also elsewhere on the board
/X_Address_2: U1.4 (Y1); also elsewhere on the board
/X_Address_3: U1.7 (Y2); also elsewhere on the board
/X_Address_4: U2.4 (Y1); also elsewhere on the board
/Y_Address_0: U2.9 (Y3); also elsewhere on the board
/Y_Address_1: U2.12 (Y4); also elsewhere on the board
/Y_Address_2: U2.7 (Y2); also elsewhere on the board
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

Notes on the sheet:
RAM ~{OE} Logic
Power Connections
Y_BUS_[0..63]
X_BUS_[0..63]
Unused Gates
Decoupling Capacitors
REG_OUT_X
REG_OUT_Y
~{WE} Logic
Outputs
WB_DATA
Address Selector
Inputs
X/Y Buffer Control

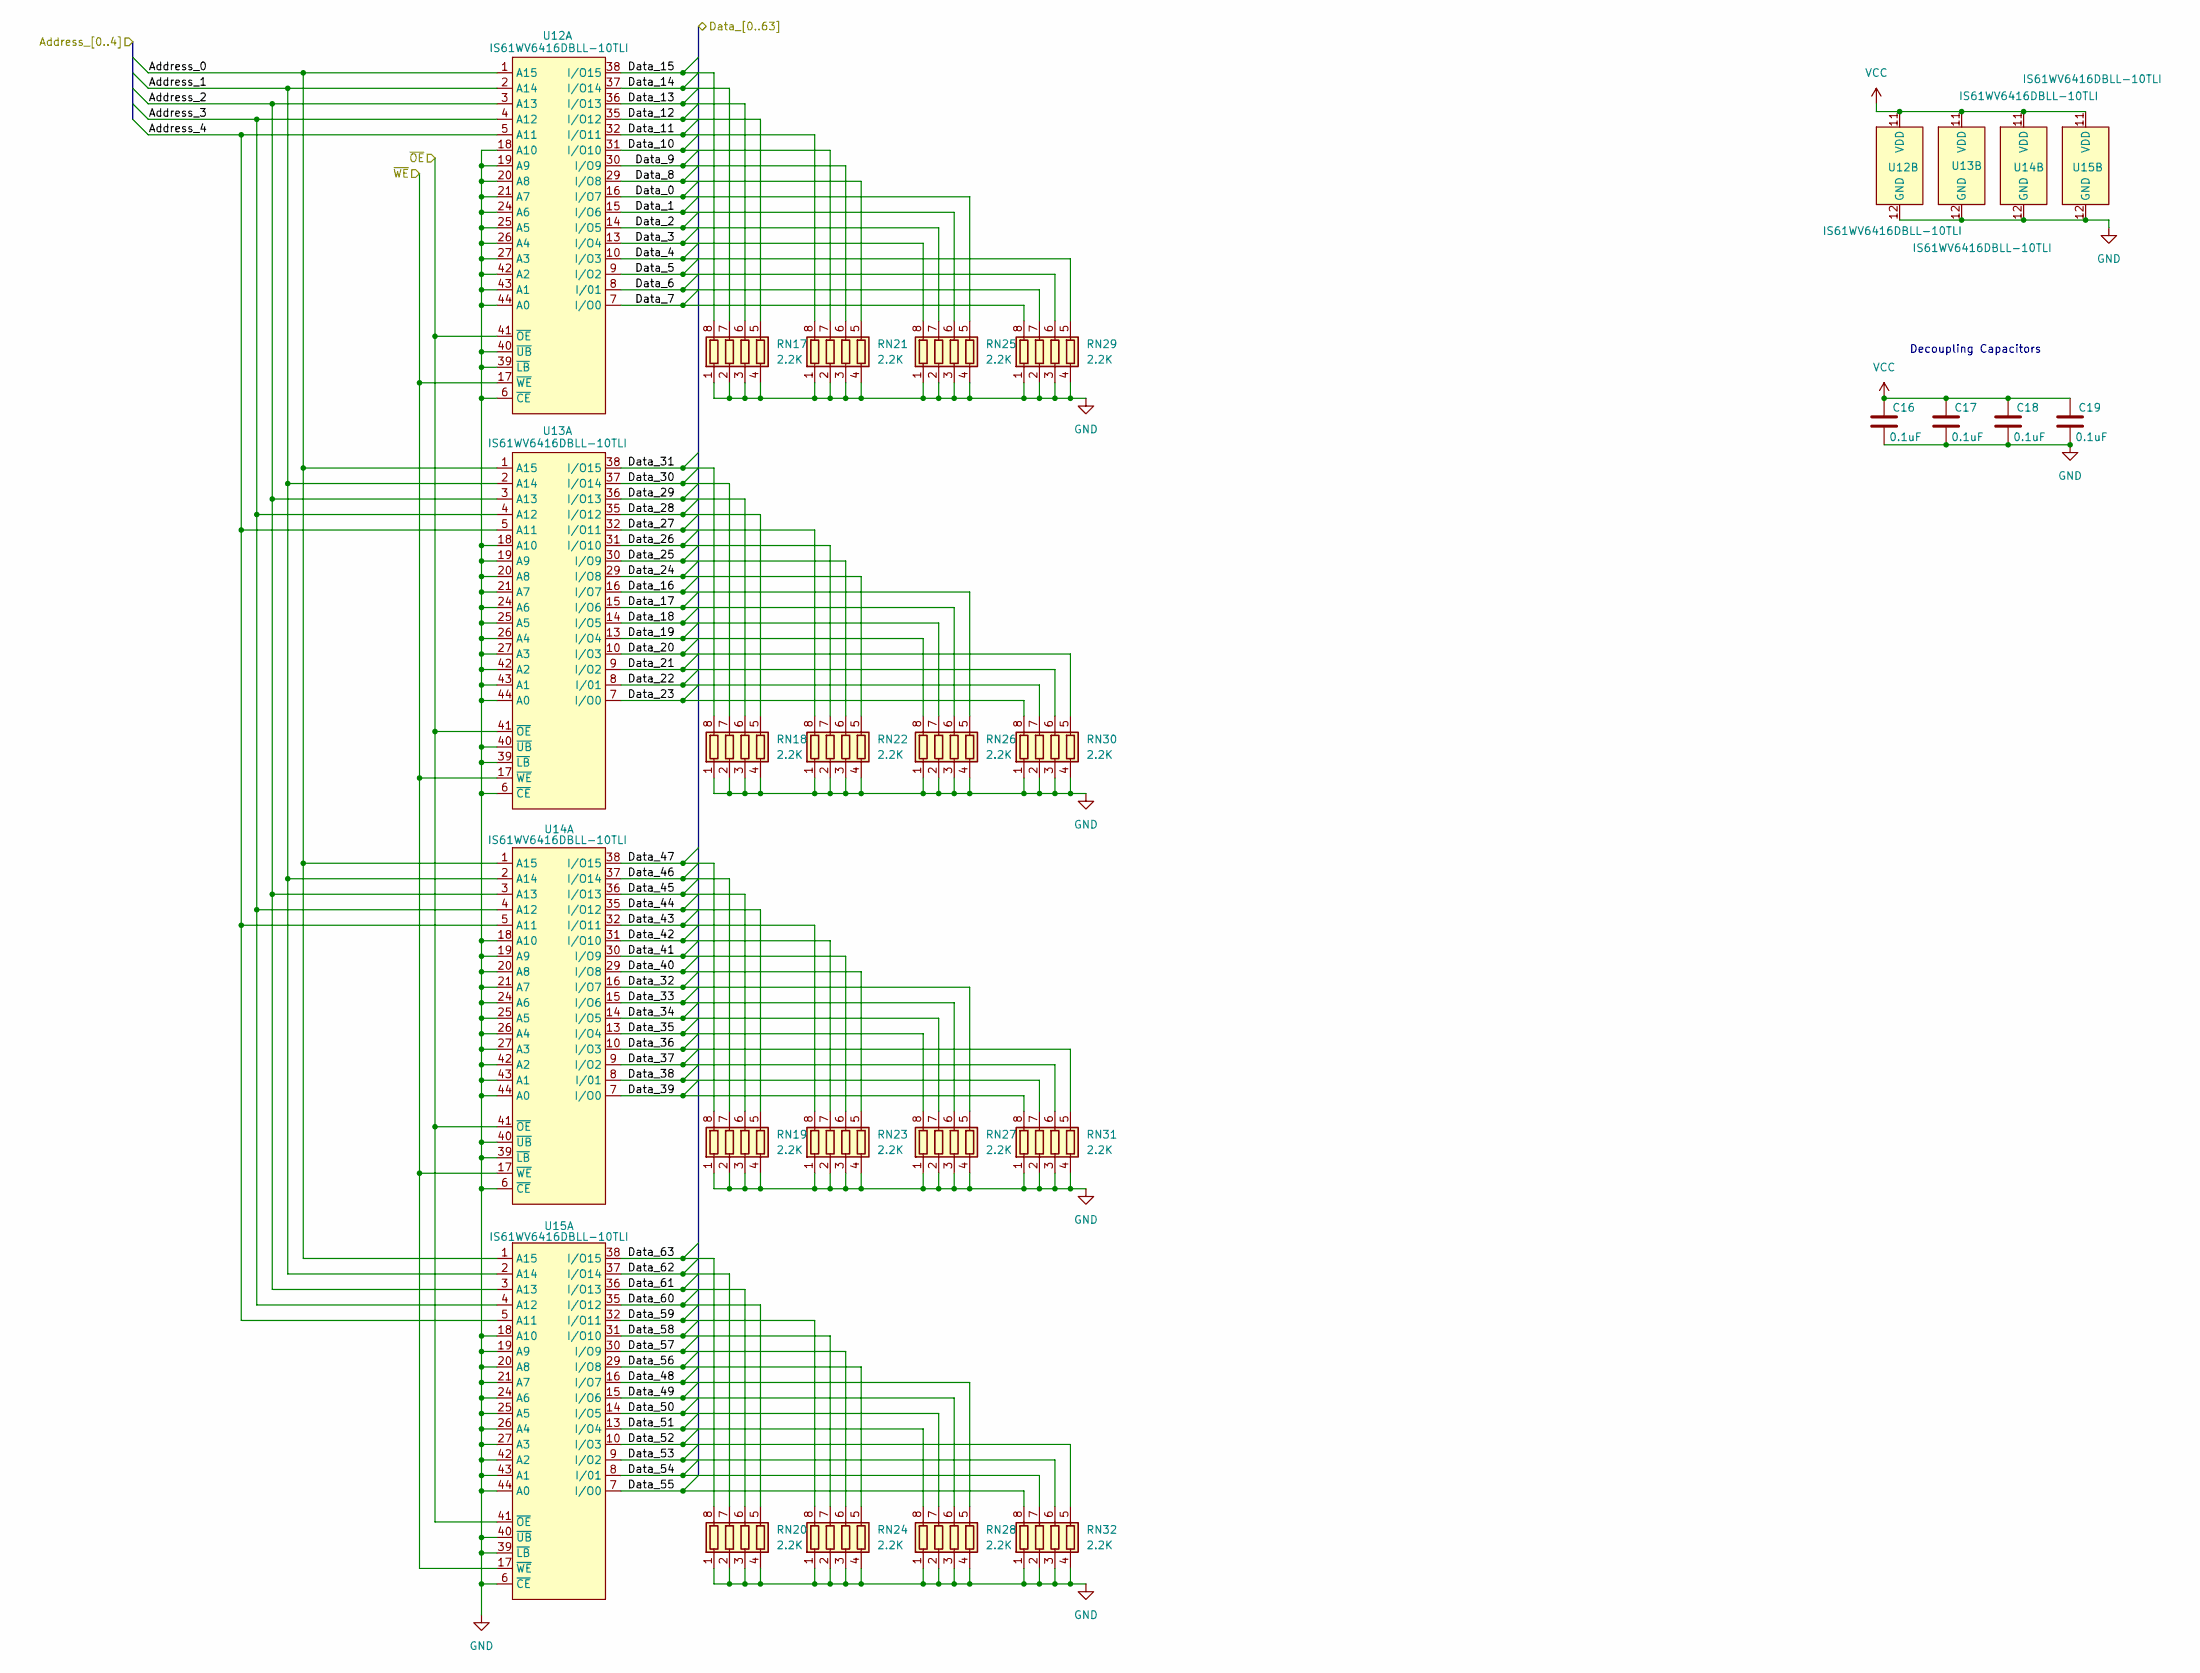
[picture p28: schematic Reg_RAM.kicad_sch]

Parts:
C16, C17, C18, C19: 0.1uF; C_1206_3216Metric
RN17, RN18, RN19, RN20, RN21, RN22, RN23, RN24, RN25, RN26, RN27, RN28, RN29, RN30, RN31, RN32: 2.2K; R_Array_Convex_4x0603
U12, U13, U14, U15: IS61WV6416DBLL-10TLI; TSOP-II-44_10.16x18.41mm_P0.8mm

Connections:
/Register_RAM_Bank_Y/Data_0: RN25.5 (R4.2), U12.16 (I/O7); also elsewhere on the board
/Register_RAM_Bank_Y/Data_1: RN25.6 (R3.2), U12.15 (I/O6); also elsewhere on the board
/Register_RAM_Bank_Y/Data_2: RN25.7 (R2.2), U12.14 (I/O5); also elsewhere on the board
/Register_RAM_Bank_Y/Data_3: RN25.8 (R1.2), U12.13 (I/O4); also elsewhere on the board
/Register_RAM_Bank_Y/Data_4: RN29.5 (R4.2), U12.10 (I/O3); also elsewhere on the board
/Register_RAM_Bank_Y/Data_5: RN29.6 (R3.2), U12.9 (I/O2); also elsewhere on the board
/Register_RAM_Bank_Y/Data_6: RN29.7 (R2.2), U12.8 (I/01); also elsewhere on the board
/Register_RAM_Bank_Y/Data_7: RN29.8 (R1.2), U12.7 (I/O0); also elsewhere on the board
/Register_RAM_Bank_Y/Data_8: RN21.5 (R4.2), U12.29 (I/O8); also elsewhere on the board
/Register_RAM_Bank_Y/Data_9: RN21.6 (R3.2), U12.30 (I/O9); also elsewhere on the board
/Register_RAM_Bank_Y/Data_10: RN21.7 (R2.2), U12.31 (I/O10); also elsewhere on the board
/Register_RAM_Bank_Y/Data_11: RN21.8 (R1.2), U12.32 (I/O11); also elsewhere on the board
/Register_RAM_Bank_Y/Data_12: RN17.5 (R4.2), U12.35 (I/O12); also elsewhere on the board
/Register_RAM_Bank_Y/Data_13: RN17.6 (R3.2), U12.36 (I/O13); also elsewhere on the board
/Register_RAM_Bank_Y/Data_14: RN17.7 (R2.2), U12.37 (I/O14); also elsewhere on the board
/Register_RAM_Bank_Y/Data_15: RN17.8 (R1.2), U12.38 (I/O15); also elsewhere on the board
/Register_RAM_Bank_Y/Data_16: RN26.5 (R4.2), U13.16 (I/O7); also elsewhere on the board
/Register_RAM_Bank_Y/Data_17: RN26.6 (R3.2), U13.15 (I/O6); also elsewhere on the board
/Register_RAM_Bank_Y/Data_18: RN26.7 (R2.2), U13.14 (I/O5); also elsewhere on the board
/Register_RAM_Bank_Y/Data_19: RN26.8 (R1.2), U13.13 (I/O4); also elsewhere on the board
/Register_RAM_Bank_Y/Data_20: RN30.5 (R4.2), U13.10 (I/O3); also elsewhere on the board
/Register_RAM_Bank_Y/Data_21: RN30.6 (R3.2), U13.9 (I/O2); also elsewhere on the board
/Register_RAM_Bank_Y/Data_22: RN30.7 (R2.2), U13.8 (I/01); also elsewhere on the board
/Register_RAM_Bank_Y/Data_23: RN30.8 (R1.2), U13.7 (I/O0); also elsewhere on the board
/Register_RAM_Bank_Y/Data_24: RN22.5 (R4.2), U13.29 (I/O8); also elsewhere on the board
/Register_RAM_Bank_Y/Data_25: RN22.6 (R3.2), U13.30 (I/O9); also elsewhere on the board
/Register_RAM_Bank_Y/Data_26: RN22.7 (R2.2), U13.31 (I/O10); also elsewhere on the board
/Register_RAM_Bank_Y/Data_27: RN22.8 (R1.2), U13.32 (I/O11); also elsewhere on the board
/Register_RAM_Bank_Y/Data_28: RN18.5 (R4.2), U13.35 (I/O12); also elsewhere on the board
/Register_RAM_Bank_Y/Data_29: RN18.6 (R3.2), U13.36 (I/O13); also elsewhere on the board
/Register_RAM_Bank_Y/Data_30: RN18.7 (R2.2), U13.37 (I/O14); also elsewhere on the board
/Register_RAM_Bank_Y/Data_31: RN18.8 (R1.2), U13.38 (I/O15); also elsewhere on the board
/Register_RAM_Bank_Y/Data_32: RN27.5 (R4.2), U14.16 (I/O7); also elsewhere on the board
/Register_RAM_Bank_Y/Data_33: RN27.6 (R3.2), U14.15 (I/O6); also elsewhere on the board
/Register_RAM_Bank_Y/Data_34: RN27.7 (R2.2), U14.14 (I/O5); also elsewhere on the board
/Register_RAM_Bank_Y/Data_35: RN27.8 (R1.2), U14.13 (I/O4); also elsewhere on the board
/Register_RAM_Bank_Y/Data_36: RN31.5 (R4.2), U14.10 (I/O3); also elsewhere on the board
/Register_RAM_Bank_Y/Data_37: RN31.6 (R3.2), U14.9 (I/O2); also elsewhere on the board
/Register_RAM_Bank_Y/Data_38: RN31.7 (R2.2), U14.8 (I/01); also elsewhere on the board
/Register_RAM_Bank_Y/Data_39: RN31.8 (R1.2), U14.7 (I/O0); also elsewhere on the board
/Register_RAM_Bank_Y/Data_40: RN23.5 (R4.2), U14.29 (I/O8); also elsewhere on the board
/Register_RAM_Bank_Y/Data_41: RN23.6 (R3.2), U14.30 (I/O9); also elsewhere on the board
/Register_RAM_Bank_Y/Data_42: RN23.7 (R2.2), U14.31 (I/O10); also elsewhere on the board
/Register_RAM_Bank_Y/Data_43: RN23.8 (R1.2), U14.32 (I/O11); also elsewhere on the board
/Register_RAM_Bank_Y/Data_44: RN19.5 (R4.2), U14.35 (I/O12); also elsewhere on the board
/Register_RAM_Bank_Y/Data_45: RN19.6 (R3.2), U14.36 (I/O13); also elsewhere on the board
/Register_RAM_Bank_Y/Data_46: RN19.7 (R2.2), U14.37 (I/O14); also elsewhere on the board
/Register_RAM_Bank_Y/Data_47: RN19.8 (R1.2), U14.38 (I/O15); also elsewhere on the board
/Register_RAM_Bank_Y/Data_48: RN28.5 (R4.2), U15.16 (I/O7); also elsewhere on the board
/Register_RAM_Bank_Y/Data_49: RN28.6 (R3.2), U15.15 (I/O6); also elsewhere on the board
/Register_RAM_Bank_Y/Data_50: RN28.7 (R2.2), U15.14 (I/O5); also elsewhere on the board
/Register_RAM_Bank_Y/Data_51: RN28.8 (R1.2), U15.13 (I/O4); also elsewhere on the board
/Register_RAM_Bank_Y/Data_52: RN32.5 (R4.2), U15.10 (I/O3); also elsewhere on the board
/Register_RAM_Bank_Y/Data_53: RN32.6 (R3.2), U15.9 (I/O2); also elsewhere on the board
/Register_RAM_Bank_Y/Data_54: RN32.7 (R2.2), U15.8 (I/01); also elsewhere on the board
/Register_RAM_Bank_Y/Data_55: RN32.8 (R1.2), U15.7 (I/O0); also elsewhere on the board
/Register_RAM_Bank_Y/Data_56: RN24.5 (R4.2), U15.29 (I/O8); also elsewhere on the board
/Register_RAM_Bank_Y/Data_57: RN24.6 (R3.2), U15.30 (I/O9); also elsewhere on the board
/Register_RAM_Bank_Y/Data_58: RN24.7 (R2.2), U15.31 (I/O10); also elsewhere on the board
/Register_RAM_Bank_Y/Data_59: RN24.8 (R1.2), U15.32 (I/O11); also elsewhere on the board
/Register_RAM_Bank_Y/Data_60: RN20.5 (R4.2), U15.35 (I/O12); also elsewhere on the board
/Register_RAM_Bank_Y/Data_61: RN20.6 (R3.2), U15.36 (I/O13); also elsewhere on the board
/Register_RAM_Bank_Y/Data_62: RN20.7 (R2.2), U15.37 (I/O14); also elsewhere on the board
/Register_RAM_Bank_Y/Data_63: RN20.8 (R1.2), U15.38 (I/O15); also elsewhere on the board
/Y_Address_0: U12.1 (A15), U13.1 (A15), U14.1 (A15), U15.1 (A15); also elsewhere on the board
/Y_Address_1: U12.2 (A14), U13.2 (A14), U14.2 (A14), U15.2 (A14); also elsewhere on the board
/Y_Address_2: U12.3 (A13), U13.3 (A13), U14.3 (A13), U15.3 (A13); also elsewhere on the board
/Y_Address_3: U12.4 (A12), U13.4 (A12), U14.4 (A12), U15.4 (A12); also elsewhere on the board
/Y_Address_4: U12.5 (A11), U13.5 (A11), U14.5 (A11), U15.5 (A11); also elsewhere on the board
/~OE_2: U12.41 (~OE), U13.41 (~OE), U14.41 (~OE), U15.41 (~OE); also elsewhere on the board
/~WE: U12.17 (~WE), U13.17 (~WE), U14.17 (~WE), U15.17 (~WE); also elsewhere on the board
GND: C16.2, C17.2, C18.2, C19.2, RN17.1 (R1.1), RN17.2 (R2.1), RN17.3 (R3.1), RN17.4 (R4.1), RN18.1 (R1.1), RN18.2 (R2.1), RN18.3 (R3.1), RN18.4 (R4.1), RN19.1 (R1.1), RN19.2 (R2.1), RN19.3 (R3.1), RN19.4 (R4.1), RN20.1 (R1.1), RN20.2 (R2.1), RN20.3 (R3.1), RN20.4 (R4.1), RN21.1 (R1.1), RN21.2 (R2.1), RN21.3 (R3.1), RN21.4 (R4.1), RN22.1 (R1.1), RN22.2 (R2.1), RN22.3 (R3.1), RN22.4 (R4.1), RN23.1 (R1.1), RN23.2 (R2.1), RN23.3 (R3.1), RN23.4 (R4.1), RN24.1 (R1.1), RN24.2 (R2.1), RN24.3 (R3.1), RN24.4 (R4.1), RN25.1 (R1.1), RN25.2 (R2.1), RN25.3 (R3.1), RN25.4 (R4.1), RN26.1 (R1.1), RN26.2 (R2.1), RN26.3 (R3.1), RN26.4 (R4.1), RN27.1 (R1.1), RN27.2 (R2.1), RN27.3 (R3.1), RN27.4 (R4.1), RN28.1 (R1.1), RN28.2 (R2.1), RN28.3 (R3.1), RN28.4 (R4.1), RN29.1 (R1.1), RN29.2 (R2.1), RN29.3 (R3.1), RN29.4 (R4.1), RN30.1 (R1.1), RN30.2 (R2.1), RN30.3 (R3.1), RN30.4 (R4.1), RN31.1 (R1.1), RN31.2 (R2.1), RN31.3 (R3.1), RN31.4 (R4.1), RN32.1 (R1.1), RN32.2 (R2.1), RN32.3 (R3.1), RN32.4 (R4.1), U12.6 (~CE), U12.12 (GND), U12.18 (A10), U12.19 (A9), U12.20 (A8), U12.21 (A7), U12.24 (A6), U12.25 (A5), U12.26 (A4), U12.27 (A3), U12.34 (GND), U12.39 (~LB), U12.40 (~UB), U12.42 (A2), U12.43 (A1), U12.44 (A0), U13.6 (~CE), U13.12 (GND), U13.18 (A10), U13.19 (A9), U13.20 (A8), U13.21 (A7), U13.24 (A6), U13.25 (A5), U13.26 (A4), U13.27 (A3), U13.34 (GND), U13.39 (~LB), U13.40 (~UB), U13.42 (A2), U13.43 (A1), U13.44 (A0), U14.6 (~CE), U14.12 (GND), U14.18 (A10), U14.19 (A9), U14.20 (A8), U14.21 (A7), U14.24 (A6), U14.25 (A5), U14.26 (A4), U14.27 (A3), U14.34 (GND), U14.39 (~LB), U14.40 (~UB), U14.42 (A2), U14.43 (A1), U14.44 (A0), U15.6 (~CE), U15.12 (GND), U15.18 (A10), U15.19 (A9), U15.20 (A8), U15.21 (A7), U15.24 (A6), U15.25 (A5), U15.26 (A4), U15.27 (A3), U15.34 (GND), U15.39 (~LB), U15.40 (~UB), U15.42 (A2), U15.43 (A1), U15.44 (A0); also elsewhere on the board
VCC: C16.1, C17.1, C18.1, C19.1, U12.11 (VDD), U12.33 (VDD), U13.11 (VDD), U13.33 (VDD), U14.11 (VDD), U14.33 (VDD), U15.11 (VDD), U15.33 (VDD); also elsewhere on the board

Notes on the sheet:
Decoupling Capacitors

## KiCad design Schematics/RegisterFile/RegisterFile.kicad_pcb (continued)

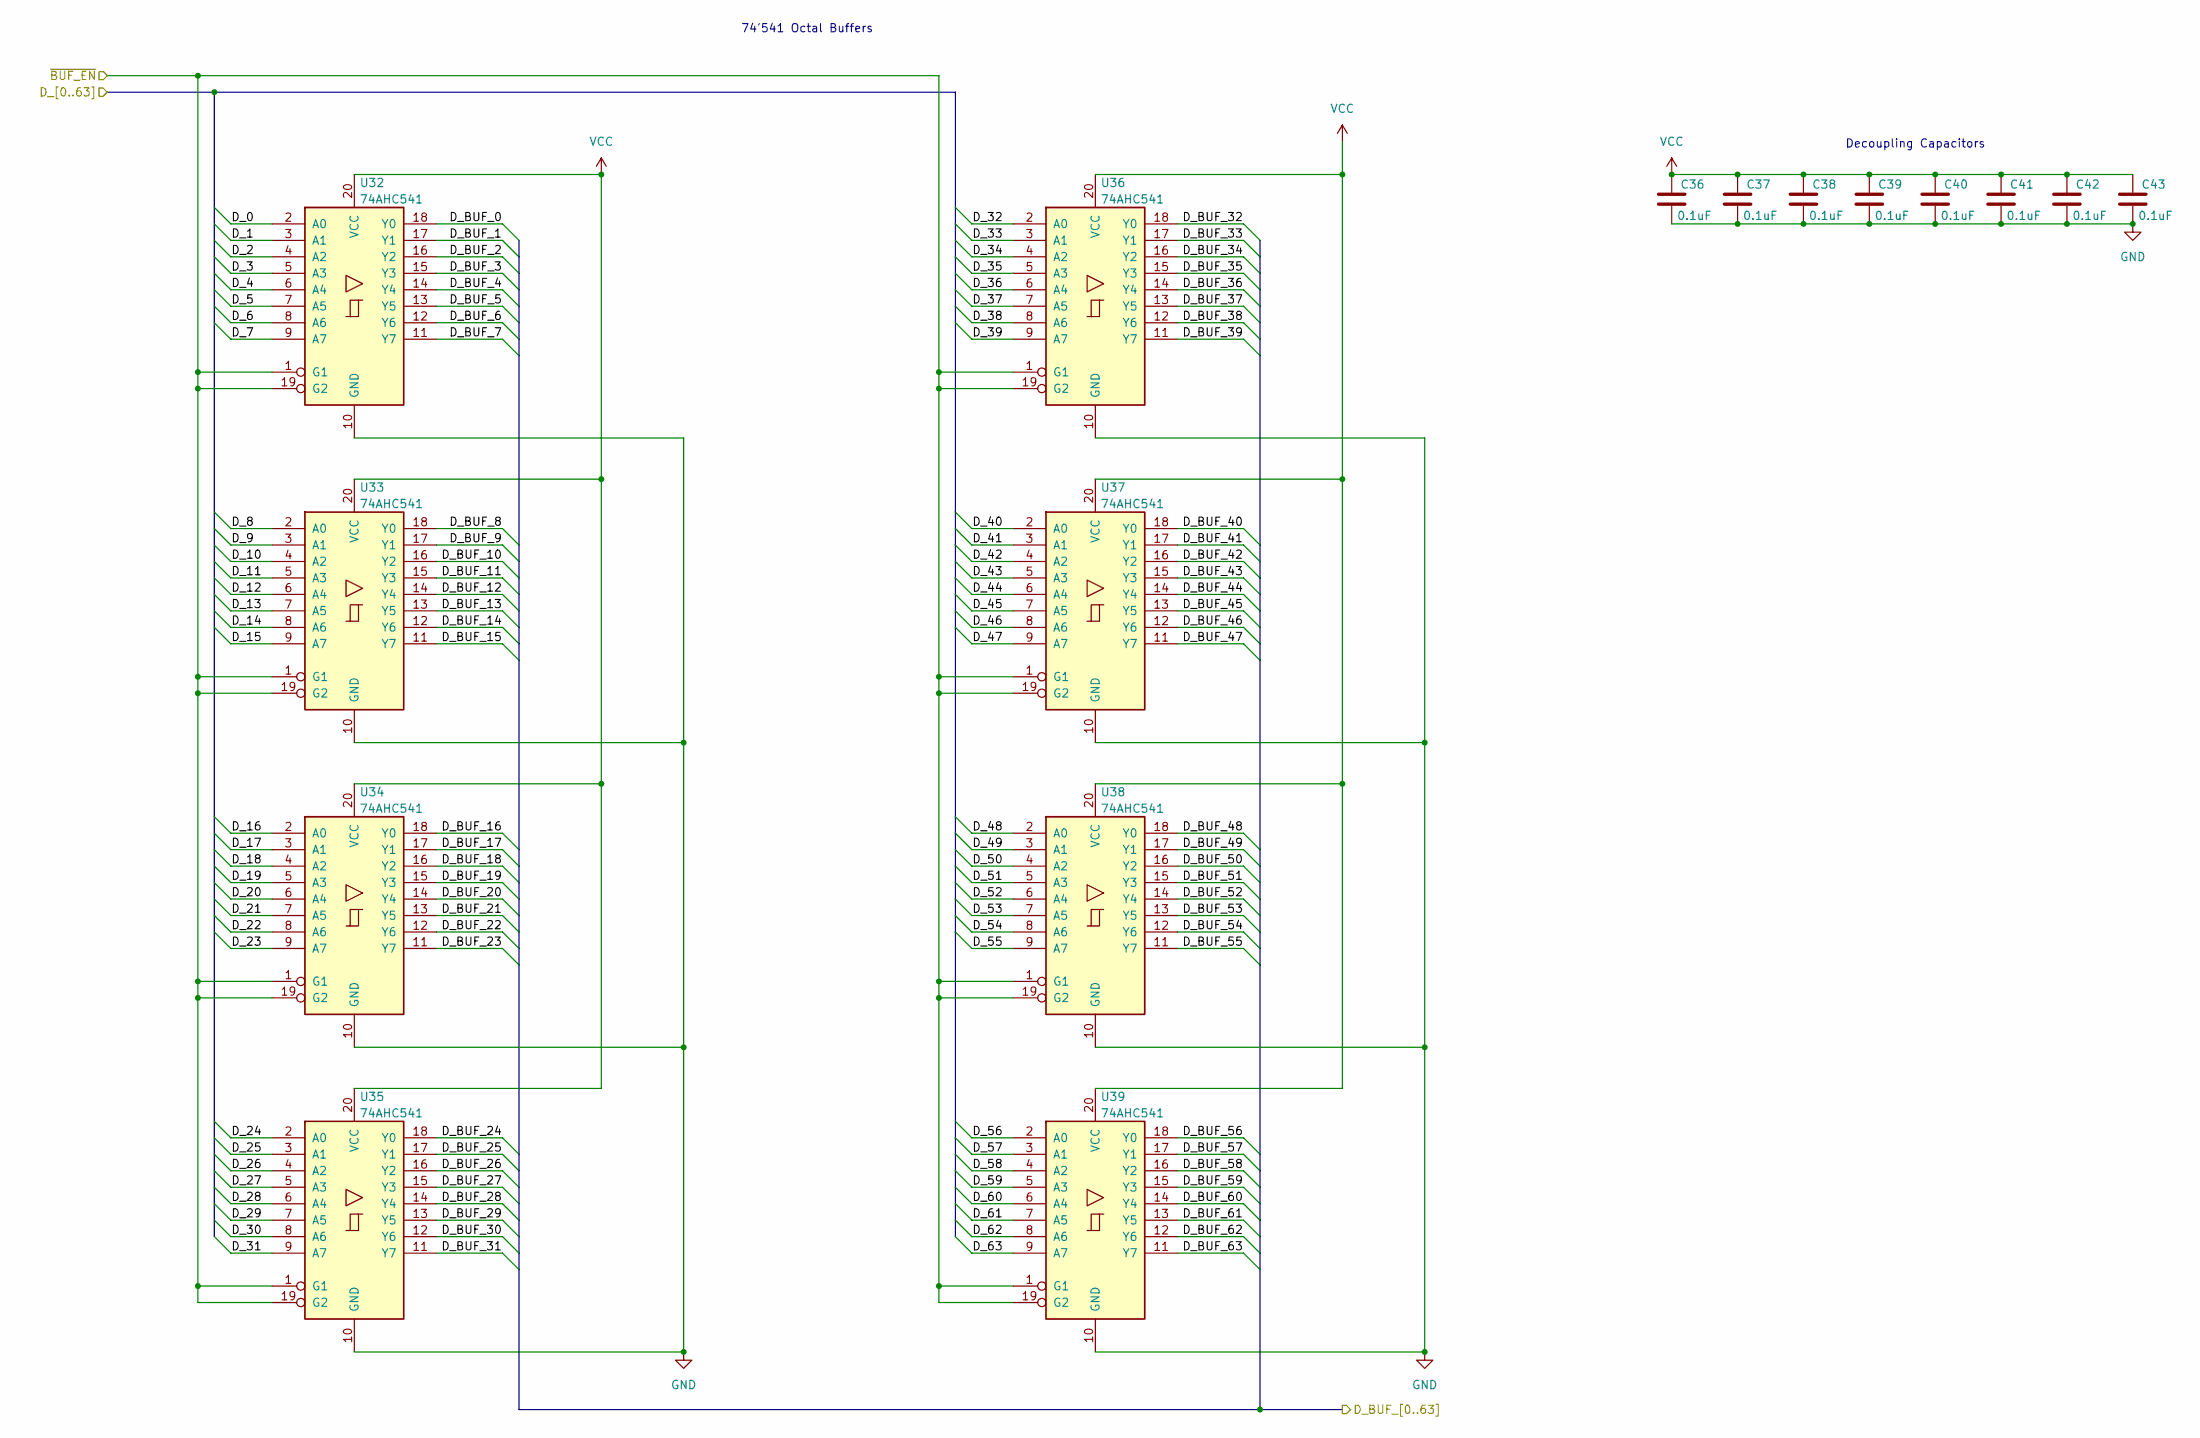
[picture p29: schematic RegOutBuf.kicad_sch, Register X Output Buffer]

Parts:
C36, C37, C38, C39, C40, C41, C42, C43: 0.1uF; C_1206_3216Metric
U32, U33, U34, U35, U36, U37, U38, U39: 74AHC541; TSSOP-20_4.4x6.5mm_P0.65mm

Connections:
/Register_RAM_Bank_Y/Data_0: U32.18 (Y0); also elsewhere on the board
/Register_RAM_Bank_Y/Data_1: U32.17 (Y1); also elsewhere on the board
/Register_RAM_Bank_Y/Data_2: U32.16 (Y2); also elsewhere on the board
/Register_RAM_Bank_Y/Data_3: U32.15 (Y3); also elsewhere on the board
/Register_RAM_Bank_Y/Data_4: U32.14 (Y4); also elsewhere on the board
/Register_RAM_Bank_Y/Data_5: U32.13 (Y5); also elsewhere on the board
/Register_RAM_Bank_Y/Data_6: U32.12 (Y6); also elsewhere on the board
/Register_RAM_Bank_Y/Data_7: U32.11 (Y7); also elsewhere on the board
/Register_RAM_Bank_Y/Data_8: U33.18 (Y0); also elsewhere on the board
/Register_RAM_Bank_Y/Data_9: U33.17 (Y1); also elsewhere on the board
/Register_RAM_Bank_Y/Data_10: U33.16 (Y2); also elsewhere on the board
/Register_RAM_Bank_Y/Data_11: U33.15 (Y3); also elsewhere on the board
/Register_RAM_Bank_Y/Data_12: U33.14 (Y4); also elsewhere on the board
/Register_RAM_Bank_Y/Data_13: U33.13 (Y5); also elsewhere on the board
/Register_RAM_Bank_Y/Data_14: U33.12 (Y6); also elsewhere on the board
/Register_RAM_Bank_Y/Data_15: U33.11 (Y7); also elsewhere on the board
/Register_RAM_Bank_Y/Data_16: U34.18 (Y0); also elsewhere on the board
/Register_RAM_Bank_Y/Data_17: U34.17 (Y1); also elsewhere on the board
/Register_RAM_Bank_Y/Data_18: U34.16 (Y2); also elsewhere on the board
/Register_RAM_Bank_Y/Data_19: U34.15 (Y3); also elsewhere on the board
/Register_RAM_Bank_Y/Data_20: U34.14 (Y4); also elsewhere on the board
/Register_RAM_Bank_Y/Data_21: U34.13 (Y5); also elsewhere on the board
/Register_RAM_Bank_Y/Data_22: U34.12 (Y6); also elsewhere on the board
/Register_RAM_Bank_Y/Data_23: U34.11 (Y7); also elsewhere on the board
/Register_RAM_Bank_Y/Data_24: U35.18 (Y0); also elsewhere on the board
/Register_RAM_Bank_Y/Data_25: U35.17 (Y1); also elsewhere on the board
/Register_RAM_Bank_Y/Data_26: U35.16 (Y2); also elsewhere on the board
/Register_RAM_Bank_Y/Data_27: U35.15 (Y3); also elsewhere on the board
/Register_RAM_Bank_Y/Data_28: U35.14 (Y4); also elsewhere on the board
/Register_RAM_Bank_Y/Data_29: U35.13 (Y5); also elsewhere on the board
/Register_RAM_Bank_Y/Data_30: U35.12 (Y6); also elsewhere on the board
/Register_RAM_Bank_Y/Data_31: U35.11 (Y7); also elsewhere on the board
/Register_RAM_Bank_Y/Data_32: U36.18 (Y0); also elsewhere on the board
/Register_RAM_Bank_Y/Data_33: U36.17 (Y1); also elsewhere on the board
/Register_RAM_Bank_Y/Data_34: U36.16 (Y2); also elsewhere on the board
/Register_RAM_Bank_Y/Data_35: U36.15 (Y3); also elsewhere on the board
/Register_RAM_Bank_Y/Data_36: U36.14 (Y4); also elsewhere on the board
/Register_RAM_Bank_Y/Data_37: U36.13 (Y5); also elsewhere on the board
/Register_RAM_Bank_Y/Data_38: U36.12 (Y6); also elsewhere on the board
/Register_RAM_Bank_Y/Data_39: U36.11 (Y7); also elsewhere on the board
/Register_RAM_Bank_Y/Data_40: U37.18 (Y0); also elsewhere on the board
/Register_RAM_Bank_Y/Data_41: U37.17 (Y1); also elsewhere on the board
/Register_RAM_Bank_Y/Data_42: U37.16 (Y2); also elsewhere on the board
/Register_RAM_Bank_Y/Data_43: U37.15 (Y3); also elsewhere on the board
/Register_RAM_Bank_Y/Data_44: U37.14 (Y4); also elsewhere on the board
/Register_RAM_Bank_Y/Data_45: U37.13 (Y5); also elsewhere on the board
/Register_RAM_Bank_Y/Data_46: U37.12 (Y6); also elsewhere on the board
/Register_RAM_Bank_Y/Data_47: U37.11 (Y7); also elsewhere on the board
/Register_RAM_Bank_Y/Data_48: U38.18 (Y0); also elsewhere on the board
/Register_RAM_Bank_Y/Data_49: U38.17 (Y1); also elsewhere on the board
/Register_RAM_Bank_Y/Data_50: U38.16 (Y2); also elsewhere on the board
/Register_RAM_Bank_Y/Data_51: U38.15 (Y3); also elsewhere on the board
/Register_RAM_Bank_Y/Data_52: U38.14 (Y4); also elsewhere on the board
/Register_RAM_Bank_Y/Data_53: U38.13 (Y5); also elsewhere on the board
/Register_RAM_Bank_Y/Data_54: U38.12 (Y6); also elsewhere on the board
/Register_RAM_Bank_Y/Data_55: U38.11 (Y7); also elsewhere on the board
/Register_RAM_Bank_Y/Data_56: U39.18 (Y0); also elsewhere on the board
/Register_RAM_Bank_Y/Data_57: U39.17 (Y1); also elsewhere on the board
/Register_RAM_Bank_Y/Data_58: U39.16 (Y2); also elsewhere on the board
/Register_RAM_Bank_Y/Data_59: U39.15 (Y3); also elsewhere on the board
/Register_RAM_Bank_Y/Data_60: U39.14 (Y4); also elsewhere on the board
/Register_RAM_Bank_Y/Data_61: U39.13 (Y5); also elsewhere on the board
/Register_RAM_Bank_Y/Data_62: U39.12 (Y6); also elsewhere on the board
/Register_RAM_Bank_Y/Data_63: U39.11 (Y7); also elsewhere on the board
/WB_DATA_0: U32.2 (A0); also elsewhere on the board
/WB_DATA_1: U32.3 (A1); also elsewhere on the board
/WB_DATA_2: U32.4 (A2); also elsewhere on the board
/WB_DATA_3: U32.5 (A3); also elsewhere on the board
/WB_DATA_4: U32.6 (A4); also elsewhere on the board
/WB_DATA_5: U32.7 (A5); also elsewhere on the board
/WB_DATA_6: U32.8 (A6); also elsewhere on the board
/WB_DATA_7: U32.9 (A7); also elsewhere on the board
/WB_DATA_8: U33.2 (A0); also elsewhere on the board
/WB_DATA_9: U33.3 (A1); also elsewhere on the board
/WB_DATA_10: U33.4 (A2); also elsewhere on the board
/WB_DATA_11: U33.5 (A3); also elsewhere on the board
/WB_DATA_12: U33.6 (A4); also elsewhere on the board
/WB_DATA_13: U33.7 (A5); also elsewhere on the board
/WB_DATA_14: U33.8 (A6); also elsewhere on the board
/WB_DATA_15: U33.9 (A7); also elsewhere on the board
/WB_DATA_16: U34.2 (A0); also elsewhere on the board
/WB_DATA_17: U34.3 (A1); also elsewhere on the board
/WB_DATA_18: U34.4 (A2); also elsewhere on the board
/WB_DATA_19: U34.5 (A3); also elsewhere on the board
/WB_DATA_20: U34.6 (A4); also elsewhere on the board
/WB_DATA_21: U34.7 (A5); also elsewhere on the board
/WB_DATA_22: U34.8 (A6); also elsewhere on the board
/WB_DATA_23: U34.9 (A7); also elsewhere on the board
/WB_DATA_24: U35.2 (A0); also elsewhere on the board
/WB_DATA_25: U35.3 (A1); also elsewhere on the board
/WB_DATA_26: U35.4 (A2); also elsewhere on the board
/WB_DATA_27: U35.5 (A3); also elsewhere on the board
/WB_DATA_28: U35.6 (A4); also elsewhere on the board
/WB_DATA_29: U35.7 (A5); also elsewhere on the board
/WB_DATA_30: U35.8 (A6); also elsewhere on the board
/WB_DATA_31: U35.9 (A7); also elsewhere on the board
/WB_DATA_32: U36.2 (A0); also elsewhere on the board
/WB_DATA_33: U36.3 (A1); also elsewhere on the board
/WB_DATA_34: U36.4 (A2); also elsewhere on the board
/WB_DATA_35: U36.5 (A3); also elsewhere on the board
/WB_DATA_36: U36.6 (A4); also elsewhere on the board
/WB_DATA_37: U36.7 (A5); also elsewhere on the board
/WB_DATA_38: U36.8 (A6); also elsewhere on the board
/WB_DATA_39: U36.9 (A7); also elsewhere on the board
/WB_DATA_40: U37.2 (A0); also elsewhere on the board
/WB_DATA_41: U37.3 (A1); also elsewhere on the board
/WB_DATA_42: U37.4 (A2); also elsewhere on the board
/WB_DATA_43: U37.5 (A3); also elsewhere on the board
/WB_DATA_44: U37.6 (A4); also elsewhere on the board
/WB_DATA_45: U37.7 (A5); also elsewhere on the board
/WB_DATA_46: U37.8 (A6); also elsewhere on the board
/WB_DATA_47: U37.9 (A7); also elsewhere on the board
/WB_DATA_48: U38.2 (A0); also elsewhere on the board
/WB_DATA_49: U38.3 (A1); also elsewhere on the board
/WB_DATA_50: U38.4 (A2); also elsewhere on the board
/WB_DATA_51: U38.5 (A3); also elsewhere on the board
/WB_DATA_52: U38.6 (A4); also elsewhere on the board
/WB_DATA_53: U38.7 (A5); also elsewhere on the board
/WB_DATA_54: U38.8 (A6); also elsewhere on the board
/WB_DATA_55: U38.9 (A7); also elsewhere on the board
/WB_DATA_56: U39.2 (A0); also elsewhere on the board
/WB_DATA_57: U39.3 (A1); also elsewhere on the board
/WB_DATA_58: U39.4 (A2); also elsewhere on the board
/WB_DATA_59: U39.5 (A3); also elsewhere on the board
/WB_DATA_60: U39.6 (A4); also elsewhere on the board
/WB_DATA_61: U39.7 (A5); also elsewhere on the board
/WB_DATA_62: U39.8 (A6); also elsewhere on the board
/WB_DATA_63: U39.9 (A7); also elsewhere on the board
/~WE: U32.1 (G1), U32.19 (G2), U33.1 (G1), U33.19 (G2), U34.1 (G1), U34.19 (G2), U35.1 (G1), U35.19 (G2), U36.1 (G1), U36.19 (G2), U37.1 (G1), U37.19 (G2), U38.1 (G1), U38.19 (G2), U39.1 (G1), U39.19 (G2); also elsewhere on the board
GND: C36.2, C37.2, C38.2, C39.2, C40.2, C41.2, C42.2, C43.2, U32.10 (GND), U33.10 (GND), U34.10 (GND), U35.10 (GND), U36.10 (GND), U37.10 (GND), U38.10 (GND), U39.10 (GND); also elsewhere on the board
VCC: C36.1, C37.1, C38.1, C39.1, C40.1, C41.1, C42.1, C43.1, U32.20 (VCC), U33.20 (VCC), U34.20 (VCC), U35.20 (VCC), U36.20 (VCC), U37.20 (VCC), U38.20 (VCC), U39.20 (VCC); also elsewhere on the board

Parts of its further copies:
C44, C45, C46, C47, C48, C49, C50, C51: 0.1uF; C_1206_3216Metric
U40, U41, U42, U43, U44, U45, U46, U47: 74AHC541; TSSOP-20_4.4x6.5mm_P0.65mm

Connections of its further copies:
/REG_OUT_Y_0: U40.18 (Y0); also elsewhere on the board
/REG_OUT_Y_1: U40.17 (Y1); also elsewhere on the board
/REG_OUT_Y_2: U40.16 (Y2); also elsewhere on the board
/REG_OUT_Y_3: U40.15 (Y3); also elsewhere on the board
/REG_OUT_Y_4: U40.14 (Y4); also elsewhere on the board
/REG_OUT_Y_5: U40.13 (Y5); also elsewhere on the board
/REG_OUT_Y_6: U40.12 (Y6); also elsewhere on the board
/REG_OUT_Y_7: U40.11 (Y7); also elsewhere on the board
/REG_OUT_Y_8: U41.18 (Y0); also elsewhere on the board
/REG_OUT_Y_9: U41.17 (Y1); also elsewhere on the board
/REG_OUT_Y_10: U41.16 (Y2); also elsewhere on the board
/REG_OUT_Y_11: U41.15 (Y3); also elsewhere on the board
/REG_OUT_Y_12: U41.14 (Y4); also elsewhere on the board
/REG_OUT_Y_13: U41.13 (Y5); also elsewhere on the board
/REG_OUT_Y_14: U41.12 (Y6); also elsewhere on the board
/REG_OUT_Y_15: U41.11 (Y7); also elsewhere on the board
/REG_OUT_Y_16: U42.18 (Y0); also elsewhere on the board
/REG_OUT_Y_17: U42.17 (Y1); also elsewhere on the board
/REG_OUT_Y_18: U42.16 (Y2); also elsewhere on the board
/REG_OUT_Y_19: U42.15 (Y3); also elsewhere on the board
/REG_OUT_Y_20: U42.14 (Y4); also elsewhere on the board
/REG_OUT_Y_21: U42.13 (Y5); also elsewhere on the board
/REG_OUT_Y_22: U42.12 (Y6); also elsewhere on the board
/REG_OUT_Y_23: U42.11 (Y7); also elsewhere on the board
/REG_OUT_Y_24: U43.18 (Y0); also elsewhere on the board
/REG_OUT_Y_25: U43.17 (Y1); also elsewhere on the board
/REG_OUT_Y_26: U43.16 (Y2); also elsewhere on the board
/REG_OUT_Y_27: U43.15 (Y3); also elsewhere on the board
/REG_OUT_Y_28: U43.14 (Y4); also elsewhere on the board
/REG_OUT_Y_29: U43.13 (Y5); also elsewhere on the board
/REG_OUT_Y_30: U43.12 (Y6); also elsewhere on the board
/REG_OUT_Y_31: U43.11 (Y7); also elsewhere on the board
/REG_OUT_Y_32: U44.18 (Y0); also elsewhere on the board
/REG_OUT_Y_33: U44.17 (Y1); also elsewhere on the board
/REG_OUT_Y_34: U44.16 (Y2); also elsewhere on the board
/REG_OUT_Y_35: U44.15 (Y3); also elsewhere on the board
/REG_OUT_Y_36: U44.14 (Y4); also elsewhere on the board
/REG_OUT_Y_37: U44.13 (Y5); also elsewhere on the board
/REG_OUT_Y_38: U44.12 (Y6); also elsewhere on the board
/REG_OUT_Y_39: U44.11 (Y7); also elsewhere on the board
/REG_OUT_Y_40: U45.18 (Y0); also elsewhere on the board
/REG_OUT_Y_41: U45.17 (Y1); also elsewhere on the board
/REG_OUT_Y_42: U45.16 (Y2); also elsewhere on the board
/REG_OUT_Y_43: U45.15 (Y3); also elsewhere on the board
/REG_OUT_Y_44: U45.14 (Y4); also elsewhere on the board
/REG_OUT_Y_45: U45.13 (Y5); also elsewhere on the board
/REG_OUT_Y_46: U45.12 (Y6); also elsewhere on the board
/REG_OUT_Y_47: U45.11 (Y7); also elsewhere on the board
/REG_OUT_Y_48: U46.18 (Y0); also elsewhere on the board
/REG_OUT_Y_49: U46.17 (Y1); also elsewhere on the board
/REG_OUT_Y_50: U46.16 (Y2); also elsewhere on the board
/REG_OUT_Y_51: U46.15 (Y3); also elsewhere on the board
/REG_OUT_Y_52: U46.14 (Y4); also elsewhere on the board
/REG_OUT_Y_53: U46.13 (Y5); also elsewhere on the board
/REG_OUT_Y_54: U46.12 (Y6); also elsewhere on the board
/REG_OUT_Y_55: U46.11 (Y7); also elsewhere on the board
/REG_OUT_Y_56: U47.18 (Y0); also elsewhere on the board
/REG_OUT_Y_57: U47.17 (Y1); also elsewhere on the board
/REG_OUT_Y_58: U47.16 (Y2); also elsewhere on the board
/REG_OUT_Y_59: U47.15 (Y3); also elsewhere on the board
/REG_OUT_Y_60: U47.14 (Y4); also elsewhere on the board
/REG_OUT_Y_61: U47.13 (Y5); also elsewhere on the board
/REG_OUT_Y_62: U47.12 (Y6); also elsewhere on the board
/REG_OUT_Y_63: U47.11 (Y7); also elsewhere on the board
/Register_RAM_Bank_Y/Data_0: U40.2 (A0); also elsewhere on the board
/Register_RAM_Bank_Y/Data_1: U40.3 (A1); also elsewhere on the board
/Register_RAM_Bank_Y/Data_2: U40.4 (A2); also elsewhere on the board
/Register_RAM_Bank_Y/Data_3: U40.5 (A3); also elsewhere on the board
/Register_RAM_Bank_Y/Data_4: U40.6 (A4); also elsewhere on the board
/Register_RAM_Bank_Y/Data_5: U40.7 (A5); also elsewhere on the board
/Register_RAM_Bank_Y/Data_6: U40.8 (A6); also elsewhere on the board
/Register_RAM_Bank_Y/Data_7: U40.9 (A7); also elsewhere on the board
/Register_RAM_Bank_Y/Data_8: U41.2 (A0); also elsewhere on the board
/Register_RAM_Bank_Y/Data_9: U41.3 (A1); also elsewhere on the board
/Register_RAM_Bank_Y/Data_10: U41.4 (A2); also elsewhere on the board
/Register_RAM_Bank_Y/Data_11: U41.5 (A3); also elsewhere on the board
/Register_RAM_Bank_Y/Data_12: U41.6 (A4); also elsewhere on the board
/Register_RAM_Bank_Y/Data_13: U41.7 (A5); also elsewhere on the board
/Register_RAM_Bank_Y/Data_14: U41.8 (A6); also elsewhere on the board
/Register_RAM_Bank_Y/Data_15: U41.9 (A7); also elsewhere on the board
/Register_RAM_Bank_Y/Data_16: U42.2 (A0); also elsewhere on the board
/Register_RAM_Bank_Y/Data_17: U42.3 (A1); also elsewhere on the board
/Register_RAM_Bank_Y/Data_18: U42.4 (A2); also elsewhere on the board
/Register_RAM_Bank_Y/Data_19: U42.5 (A3); also elsewhere on the board
/Register_RAM_Bank_Y/Data_20: U42.6 (A4); also elsewhere on the board
/Register_RAM_Bank_Y/Data_21: U42.7 (A5); also elsewhere on the board
/Register_RAM_Bank_Y/Data_22: U42.8 (A6); also elsewhere on the board
/Register_RAM_Bank_Y/Data_23: U42.9 (A7); also elsewhere on the board
/Register_RAM_Bank_Y/Data_24: U43.2 (A0); also elsewhere on the board
/Register_RAM_Bank_Y/Data_25: U43.3 (A1); also elsewhere on the board
/Register_RAM_Bank_Y/Data_26: U43.4 (A2); also elsewhere on the board
/Register_RAM_Bank_Y/Data_27: U43.5 (A3); also elsewhere on the board
/Register_RAM_Bank_Y/Data_28: U43.6 (A4); also elsewhere on the board
/Register_RAM_Bank_Y/Data_29: U43.7 (A5); also elsewhere on the board
/Register_RAM_Bank_Y/Data_30: U43.8 (A6); also elsewhere on the board
/Register_RAM_Bank_Y/Data_31: U43.9 (A7); also elsewhere on the board
/Register_RAM_Bank_Y/Data_32: U44.2 (A0); also elsewhere on the board
/Register_RAM_Bank_Y/Data_33: U44.3 (A1); also elsewhere on the board
/Register_RAM_Bank_Y/Data_34: U44.4 (A2); also elsewhere on the board
/Register_RAM_Bank_Y/Data_35: U44.5 (A3); also elsewhere on the board
/Register_RAM_Bank_Y/Data_36: U44.6 (A4); also elsewhere on the board
/Register_RAM_Bank_Y/Data_37: U44.7 (A5); also elsewhere on the board
/Register_RAM_Bank_Y/Data_38: U44.8 (A6); also elsewhere on the board
/Register_RAM_Bank_Y/Data_39: U44.9 (A7); also elsewhere on the board
/Register_RAM_Bank_Y/Data_40: U45.2 (A0); also elsewhere on the board
/Register_RAM_Bank_Y/Data_41: U45.3 (A1); also elsewhere on the board
/Register_RAM_Bank_Y/Data_42: U45.4 (A2); also elsewhere on the board
/Register_RAM_Bank_Y/Data_43: U45.5 (A3); also elsewhere on the board
/Register_RAM_Bank_Y/Data_44: U45.6 (A4); also elsewhere on the board
/Register_RAM_Bank_Y/Data_45: U45.7 (A5); also elsewhere on the board
/Register_RAM_Bank_Y/Data_46: U45.8 (A6); also elsewhere on the board
/Register_RAM_Bank_Y/Data_47: U45.9 (A7); also elsewhere on the board
/Register_RAM_Bank_Y/Data_48: U46.2 (A0); also elsewhere on the board
/Register_RAM_Bank_Y/Data_49: U46.3 (A1); also elsewhere on the board
/Register_RAM_Bank_Y/Data_50: U46.4 (A2); also elsewhere on the board
/Register_RAM_Bank_Y/Data_51: U46.5 (A3); also elsewhere on the board
/Register_RAM_Bank_Y/Data_52: U46.6 (A4); also elsewhere on the board
/Register_RAM_Bank_Y/Data_53: U46.7 (A5); also elsewhere on the board
/Register_RAM_Bank_Y/Data_54: U46.8 (A6); also elsewhere on the board
/Register_RAM_Bank_Y/Data_55: U46.9 (A7); also elsewhere on the board
/Register_RAM_Bank_Y/Data_56: U47.2 (A0); also elsewhere on the board
/Register_RAM_Bank_Y/Data_57: U47.3 (A1); also elsewhere on the board
/Register_RAM_Bank_Y/Data_58: U47.4 (A2); also elsewhere on the board
/Register_RAM_Bank_Y/Data_59: U47.5 (A3); also elsewhere on the board
/Register_RAM_Bank_Y/Data_60: U47.6 (A4); also elsewhere on the board
/Register_RAM_Bank_Y/Data_61: U47.7 (A5); also elsewhere on the board
/Register_RAM_Bank_Y/Data_62: U47.8 (A6); also elsewhere on the board
/Register_RAM_Bank_Y/Data_63: U47.9 (A7); also elsewhere on the board
/~BUF_EN_Y: U40.1 (G1), U40.19 (G2), U41.1 (G1), U41.19 (G2), U42.1 (G1), U42.19 (G2), U43.1 (G1), U43.19 (G2), U44.1 (G1), U44.19 (G2), U45.1 (G1), U45.19 (G2), U46.1 (G1), U46.19 (G2), U47.1 (G1), U47.19 (G2); also elsewhere on the board
GND: C44.2, C45.2, C46.2, C47.2, C48.2, C49.2, C50.2, C51.2, U40.10 (GND), U41.10 (GND), U42.10 (GND), U43.10 (GND), U44.10 (GND), U45.10 (GND), U46.10 (GND), U47.10 (GND); also elsewhere on the board
VCC: C44.1, C45.1, C46.1, C47.1, C48.1, C49.1, C50.1, C51.1, U40.20 (VCC), U41.20 (VCC), U42.20 (VCC), U43.20 (VCC), U44.20 (VCC), U45.20 (VCC), U46.20 (VCC), U47.20 (VCC); also elsewhere on the board

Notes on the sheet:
Decoupling Capacitors
74'541 Octal Buffers

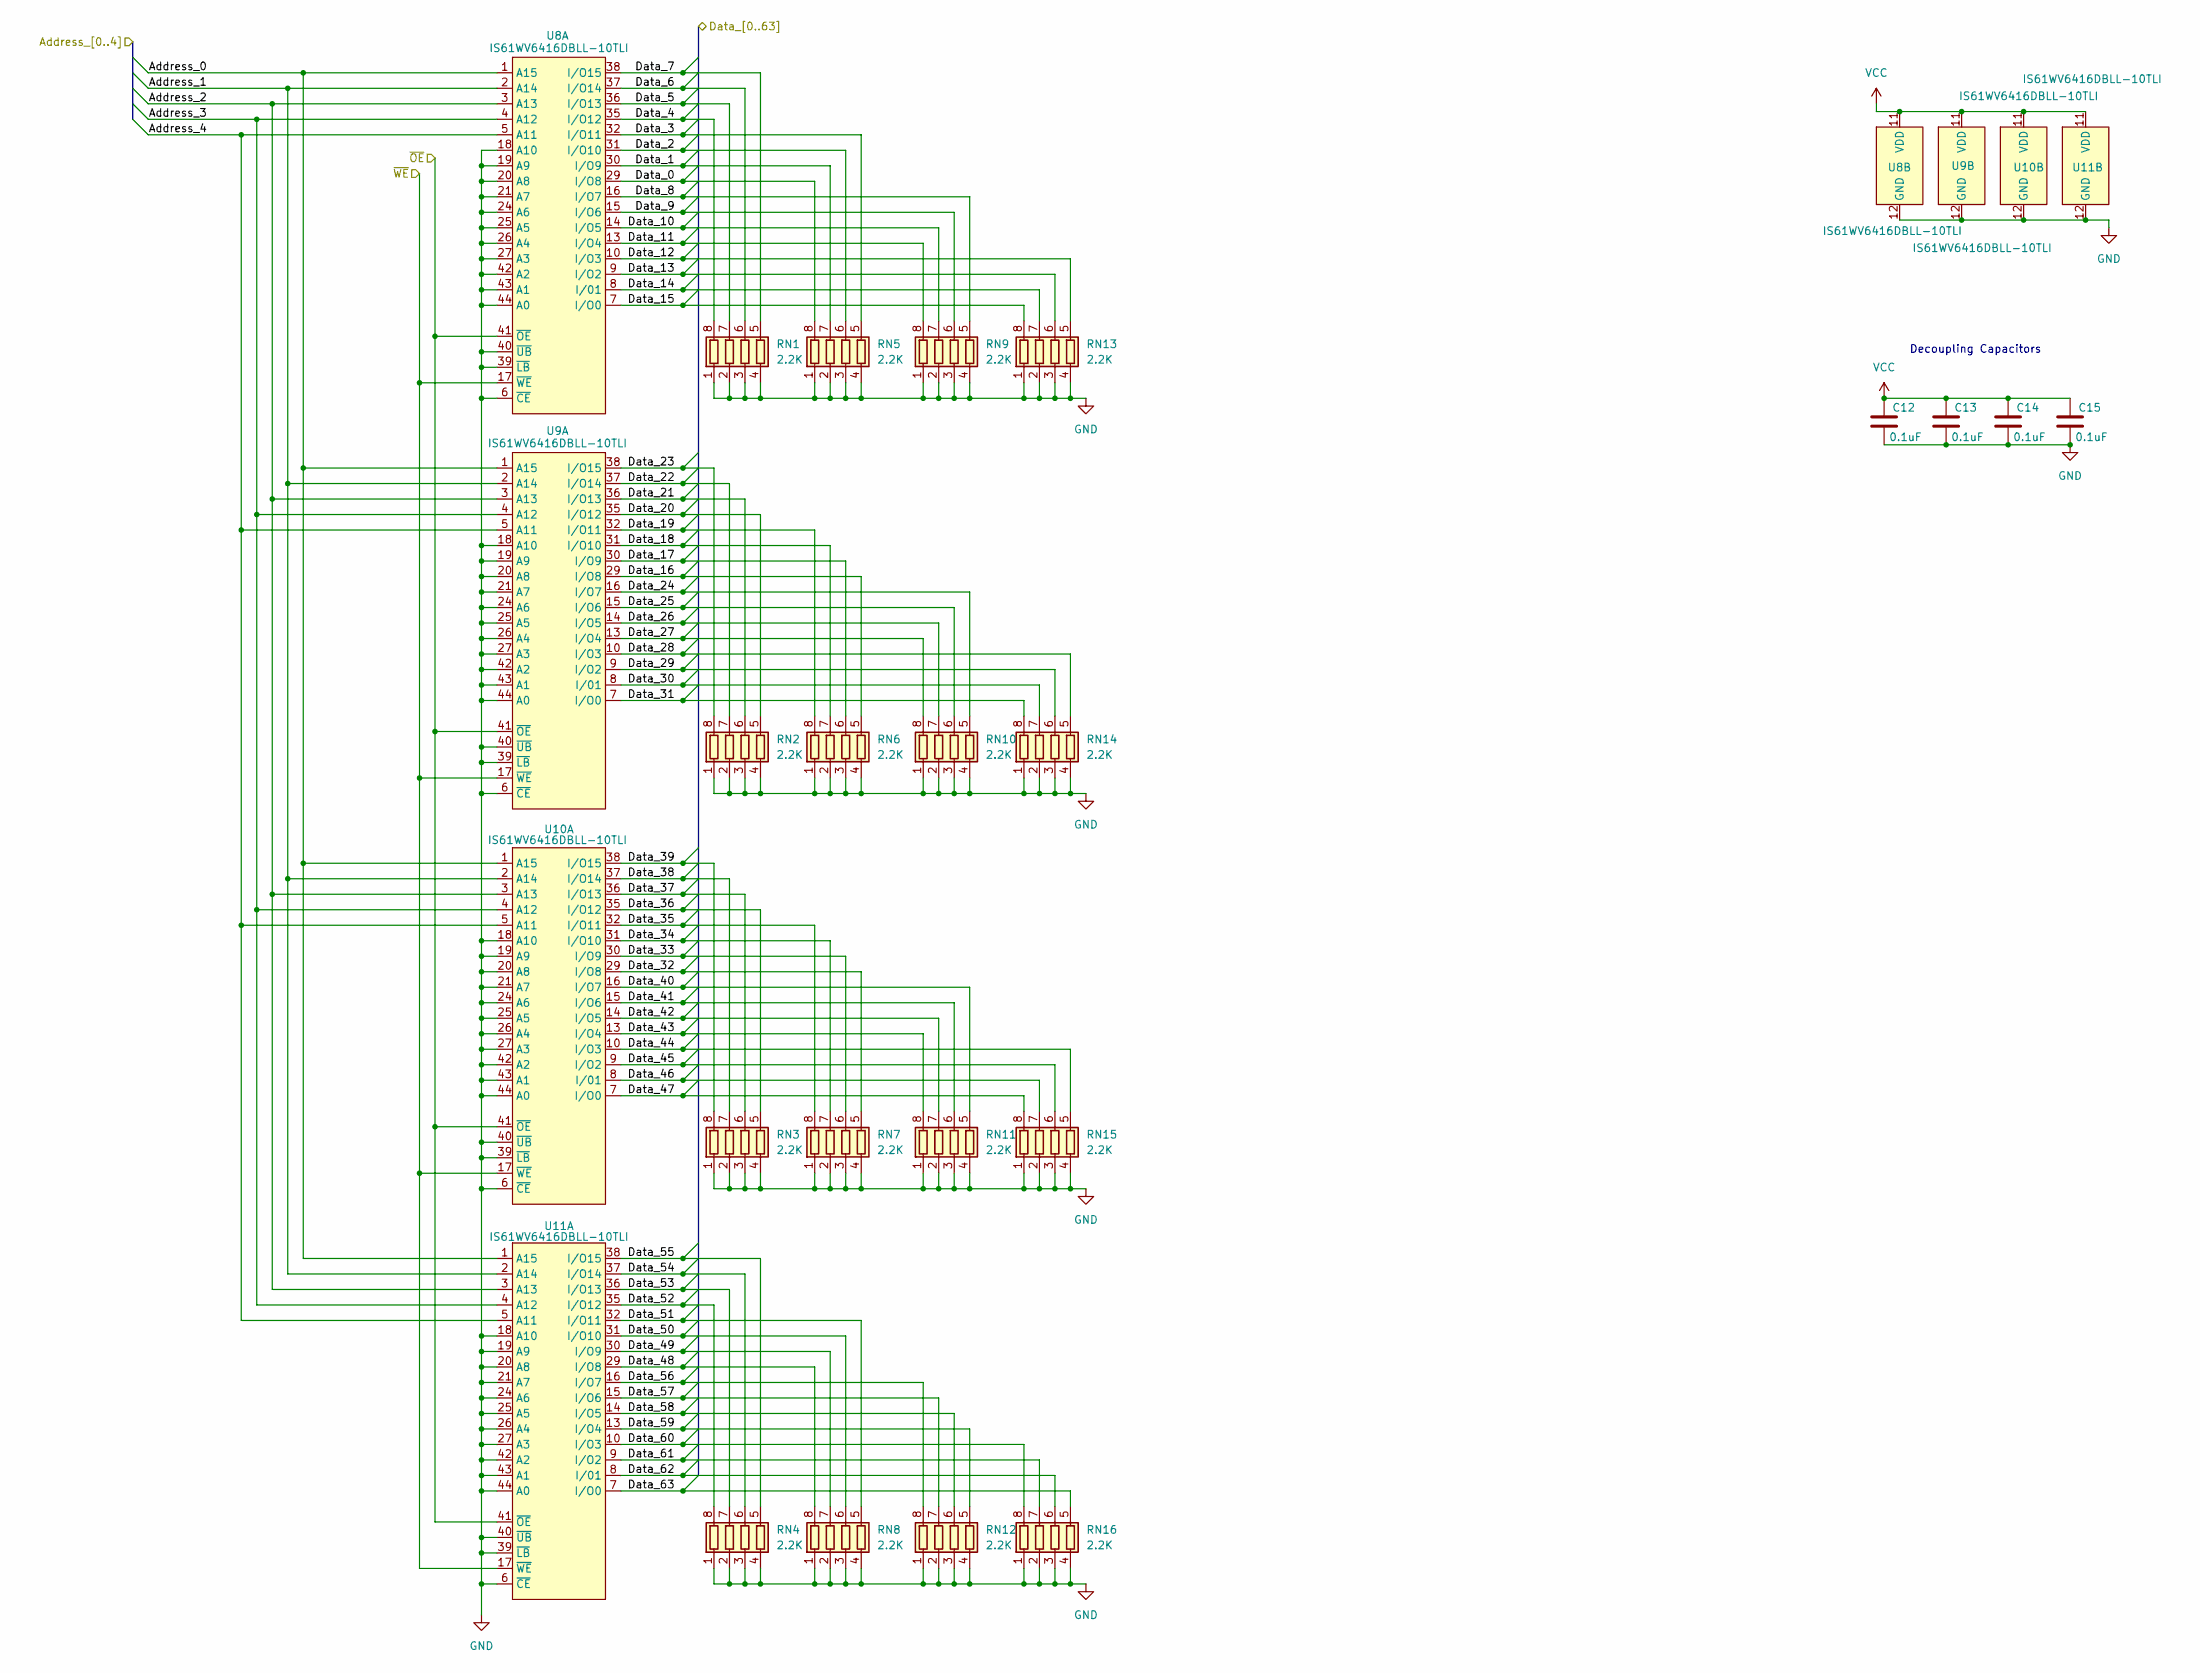
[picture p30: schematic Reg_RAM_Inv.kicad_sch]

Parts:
C12, C13, C14, C15: 0.1uF; C_1206_3216Metric
RN1, RN2, RN3, RN4, RN5, RN6, RN7, RN8, RN9, RN10, RN11, RN12, RN13, RN14, RN15, RN16: 2.2K; R_Array_Convex_4x0603
U8, U9, U10, U11: IS61WV6416DBLL-10TLI; TSOP-II-44_10.16x18.41mm_P0.8mm

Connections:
/Register_RAM_Bank X/Data_0: RN5.8 (R1.2), U8.29 (I/O8); also elsewhere on the board
/Register_RAM_Bank X/Data_1: RN5.7 (R2.2), U8.30 (I/O9); also elsewhere on the board
/Register_RAM_Bank X/Data_2: RN5.6 (R3.2), U8.31 (I/O10); also elsewhere on the board
/Register_RAM_Bank X/Data_3: RN5.5 (R4.2), U8.32 (I/O11); also elsewhere on the board
/Register_RAM_Bank X/Data_4: RN1.8 (R1.2), U8.35 (I/O12); also elsewhere on the board
/Register_RAM_Bank X/Data_5: RN1.7 (R2.2), U8.36 (I/O13); also elsewhere on the board
/Register_RAM_Bank X/Data_6: RN1.6 (R3.2), U8.37 (I/O14); also elsewhere on the board
/Register_RAM_Bank X/Data_7: RN1.5 (R4.2), U8.38 (I/O15); also elsewhere on the board
/Register_RAM_Bank X/Data_8: RN9.5 (R4.2), U8.16 (I/O7); also elsewhere on the board
/Register_RAM_Bank X/Data_9: RN9.6 (R3.2), U8.15 (I/O6); also elsewhere on the board
/Register_RAM_Bank X/Data_10: RN9.7 (R2.2), U8.14 (I/O5); also elsewhere on the board
/Register_RAM_Bank X/Data_11: RN9.8 (R1.2), U8.13 (I/O4); also elsewhere on the board
/Register_RAM_Bank X/Data_12: RN13.5 (R4.2), U8.10 (I/O3); also elsewhere on the board
/Register_RAM_Bank X/Data_13: RN13.6 (R3.2), U8.9 (I/O2); also elsewhere on the board
/Register_RAM_Bank X/Data_14: RN13.7 (R2.2), U8.8 (I/01); also elsewhere on the board
/Register_RAM_Bank X/Data_15: RN13.8 (R1.2), U8.7 (I/O0); also elsewhere on the board
/Register_RAM_Bank X/Data_16: RN6.5 (R4.2), U9.29 (I/O8); also elsewhere on the board
/Register_RAM_Bank X/Data_17: RN6.6 (R3.2), U9.30 (I/O9); also elsewhere on the board
/Register_RAM_Bank X/Data_18: RN6.7 (R2.2), U9.31 (I/O10); also elsewhere on the board
/Register_RAM_Bank X/Data_19: RN6.8 (R1.2), U9.32 (I/O11); also elsewhere on the board
/Register_RAM_Bank X/Data_20: RN2.5 (R4.2), U9.35 (I/O12); also elsewhere on the board
/Register_RAM_Bank X/Data_21: RN2.6 (R3.2), U9.36 (I/O13); also elsewhere on the board
/Register_RAM_Bank X/Data_22: RN2.7 (R2.2), U9.37 (I/O14); also elsewhere on the board
/Register_RAM_Bank X/Data_23: RN2.8 (R1.2), U9.38 (I/O15); also elsewhere on the board
/Register_RAM_Bank X/Data_24: RN10.5 (R4.2), U9.16 (I/O7); also elsewhere on the board
/Register_RAM_Bank X/Data_25: RN10.6 (R3.2), U9.15 (I/O6); also elsewhere on the board
/Register_RAM_Bank X/Data_26: RN10.7 (R2.2), U9.14 (I/O5); also elsewhere on the board
/Register_RAM_Bank X/Data_27: RN10.8 (R1.2), U9.13 (I/O4); also elsewhere on the board
/Register_RAM_Bank X/Data_28: RN14.5 (R4.2), U9.10 (I/O3); also elsewhere on the board
/Register_RAM_Bank X/Data_29: RN14.6 (R3.2), U9.9 (I/O2); also elsewhere on the board
/Register_RAM_Bank X/Data_30: RN14.7 (R2.2), U9.8 (I/01); also elsewhere on the board
/Register_RAM_Bank X/Data_31: RN14.8 (R1.2), U9.7 (I/O0); also elsewhere on the board
/Register_RAM_Bank X/Data_32: RN7.5 (R4.2), U10.29 (I/O8); also elsewhere on the board
/Register_RAM_Bank X/Data_33: RN7.6 (R3.2), U10.30 (I/O9); also elsewhere on the board
/Register_RAM_Bank X/Data_34: RN7.7 (R2.2), U10.31 (I/O10); also elsewhere on the board
/Register_RAM_Bank X/Data_35: RN7.8 (R1.2), U10.32 (I/O11); also elsewhere on the board
/Register_RAM_Bank X/Data_36: RN3.5 (R4.2), U10.35 (I/O12); also elsewhere on the board
/Register_RAM_Bank X/Data_37: RN3.6 (R3.2), U10.36 (I/O13); also elsewhere on the board
/Register_RAM_Bank X/Data_38: RN3.7 (R2.2), U10.37 (I/O14); also elsewhere on the board
/Register_RAM_Bank X/Data_39: RN3.8 (R1.2), U10.38 (I/O15); also elsewhere on the board
/Register_RAM_Bank X/Data_40: RN11.5 (R4.2), U10.16 (I/O7); also elsewhere on the board
/Register_RAM_Bank X/Data_41: RN11.6 (R3.2), U10.15 (I/O6); also elsewhere on the board
/Register_RAM_Bank X/Data_42: RN11.7 (R2.2), U10.14 (I/O5); also elsewhere on the board
/Register_RAM_Bank X/Data_43: RN11.8 (R1.2), U10.13 (I/O4); also elsewhere on the board
/Register_RAM_Bank X/Data_44: RN15.5 (R4.2), U10.10 (I/O3); also elsewhere on the board
/Register_RAM_Bank X/Data_45: RN15.6 (R3.2), U10.9 (I/O2); also elsewhere on the board
/Register_RAM_Bank X/Data_46: RN15.7 (R2.2), U10.8 (I/01); also elsewhere on the board
/Register_RAM_Bank X/Data_47: RN15.8 (R1.2), U10.7 (I/O0); also elsewhere on the board
/Register_RAM_Bank X/Data_48: RN8.8 (R1.2), U11.29 (I/O8); also elsewhere on the board
/Register_RAM_Bank X/Data_49: RN8.7 (R2.2), U11.30 (I/O9); also elsewhere on the board
/Register_RAM_Bank X/Data_50: RN8.6 (R3.2), U11.31 (I/O10); also elsewhere on the board
/Register_RAM_Bank X/Data_51: RN8.5 (R4.2), U11.32 (I/O11); also elsewhere on the board
/Register_RAM_Bank X/Data_52: RN4.8 (R1.2), U11.35 (I/O12); also elsewhere on the board
/Register_RAM_Bank X/Data_53: RN4.7 (R2.2), U11.36 (I/O13); also elsewhere on the board
/Register_RAM_Bank X/Data_54: RN4.6 (R3.2), U11.37 (I/O14); also elsewhere on the board
/Register_RAM_Bank X/Data_55: RN4.5 (R4.2), U11.38 (I/O15); also elsewhere on the board
/Register_RAM_Bank X/Data_56: RN12.8 (R1.2), U11.16 (I/O7); also elsewhere on the board
/Register_RAM_Bank X/Data_57: RN12.7 (R2.2), U11.15 (I/O6); also elsewhere on the board
/Register_RAM_Bank X/Data_58: RN12.6 (R3.2), U11.14 (I/O5); also elsewhere on the board
/Register_RAM_Bank X/Data_59: RN12.5 (R4.2), U11.13 (I/O4); also elsewhere on the board
/Register_RAM_Bank X/Data_60: RN16.8 (R1.2), U11.10 (I/O3); also elsewhere on the board
/Register_RAM_Bank X/Data_61: RN16.7 (R2.2), U11.9 (I/O2); also elsewhere on the board
/Register_RAM_Bank X/Data_62: RN16.6 (R3.2), U11.8 (I/01); also elsewhere on the board
/Register_RAM_Bank X/Data_63: RN16.5 (R4.2), U11.7 (I/O0); also elsewhere on the board
/X_Address_0: U8.1 (A15), U9.1 (A15), U10.1 (A15), U11.1 (A15); also elsewhere on the board
/X_Address_1: U8.2 (A14), U9.2 (A14), U10.2 (A14), U11.2 (A14); also elsewhere on the board
/X_Address_2: U8.3 (A13), U9.3 (A13), U10.3 (A13), U11.3 (A13); also elsewhere on the board
/X_Address_3: U8.4 (A12), U9.4 (A12), U10.4 (A12), U11.4 (A12); also elsewhere on the board
/X_Address_4: U8.5 (A11), U9.5 (A11), U10.5 (A11), U11.5 (A11); also elsewhere on the board
/~OE_1: U8.41 (~OE), U9.41 (~OE), U10.41 (~OE), U11.41 (~OE); also elsewhere on the board
/~WE: U8.17 (~WE), U9.17 (~WE), U10.17 (~WE), U11.17 (~WE); also elsewhere on the board
GND: C12.2, C13.2, C14.2, C15.2, RN1.1 (R1.1), RN1.2 (R2.1), RN1.3 (R3.1), RN1.4 (R4.1), RN2.1 (R1.1), RN2.2 (R2.1), RN2.3 (R3.1), RN2.4 (R4.1), RN3.1 (R1.1), RN3.2 (R2.1), RN3.3 (R3.1), RN3.4 (R4.1), RN4.1 (R1.1), RN4.2 (R2.1), RN4.3 (R3.1), RN4.4 (R4.1), RN5.1 (R1.1), RN5.2 (R2.1), RN5.3 (R3.1), RN5.4 (R4.1), RN6.1 (R1.1), RN6.2 (R2.1), RN6.3 (R3.1), RN6.4 (R4.1), RN7.1 (R1.1), RN7.2 (R2.1), RN7.3 (R3.1), RN7.4 (R4.1), RN8.1 (R1.1), RN8.2 (R2.1), RN8.3 (R3.1), RN8.4 (R4.1), RN9.1 (R1.1), RN9.2 (R2.1), RN9.3 (R3.1), RN9.4 (R4.1), RN10.1 (R1.1), RN10.2 (R2.1), RN10.3 (R3.1), RN10.4 (R4.1), RN11.1 (R1.1), RN11.2 (R2.1), RN11.3 (R3.1), RN11.4 (R4.1), RN12.1 (R1.1), RN12.2 (R2.1), RN12.3 (R3.1), RN12.4 (R4.1), RN13.1 (R1.1), RN13.2 (R2.1), RN13.3 (R3.1), RN13.4 (R4.1), RN14.1 (R1.1), RN14.2 (R2.1), RN14.3 (R3.1), RN14.4 (R4.1), RN15.1 (R1.1), RN15.2 (R2.1), RN15.3 (R3.1), RN15.4 (R4.1), RN16.1 (R1.1), RN16.2 (R2.1), RN16.3 (R3.1), RN16.4 (R4.1), U8.6 (~CE), U8.12 (GND), U8.18 (A10), U8.19 (A9), U8.20 (A8), U8.21 (A7), U8.24 (A6), U8.25 (A5), U8.26 (A4), U8.27 (A3), U8.34 (GND), U8.39 (~LB), U8.40 (~UB), U8.42 (A2), U8.43 (A1), U8.44 (A0), U9.6 (~CE), U9.12 (GND), U9.18 (A10), U9.19 (A9), U9.20 (A8), U9.21 (A7), U9.24 (A6), U9.25 (A5), U9.26 (A4), U9.27 (A3), U9.34 (GND), U9.39 (~LB), U9.40 (~UB), U9.42 (A2), U9.43 (A1), U9.44 (A0), U10.6 (~CE), U10.12 (GND), U10.18 (A10), U10.19 (A9), U10.20 (A8), U10.21 (A7), U10.24 (A6), U10.25 (A5), U10.26 (A4), U10.27 (A3), U10.34 (GND), U10.39 (~LB), U10.40 (~UB), U10.42 (A2), U10.43 (A1), U10.44 (A0), U11.6 (~CE), U11.12 (GND), U11.18 (A10), U11.19 (A9), U11.20 (A8), U11.21 (A7), U11.24 (A6), U11.25 (A5), U11.26 (A4), U11.27 (A3), U11.34 (GND), U11.39 (~LB), U11.40 (~UB), U11.42 (A2), U11.43 (A1), U11.44 (A0); also elsewhere on the board
VCC: C12.1, C13.1, C14.1, C15.1, U8.11 (VDD), U8.33 (VDD), U9.11 (VDD), U9.33 (VDD), U10.11 (VDD), U10.33 (VDD), U11.11 (VDD), U11.33 (VDD); also elsewhere on the board

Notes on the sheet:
Decoupling Capacitors

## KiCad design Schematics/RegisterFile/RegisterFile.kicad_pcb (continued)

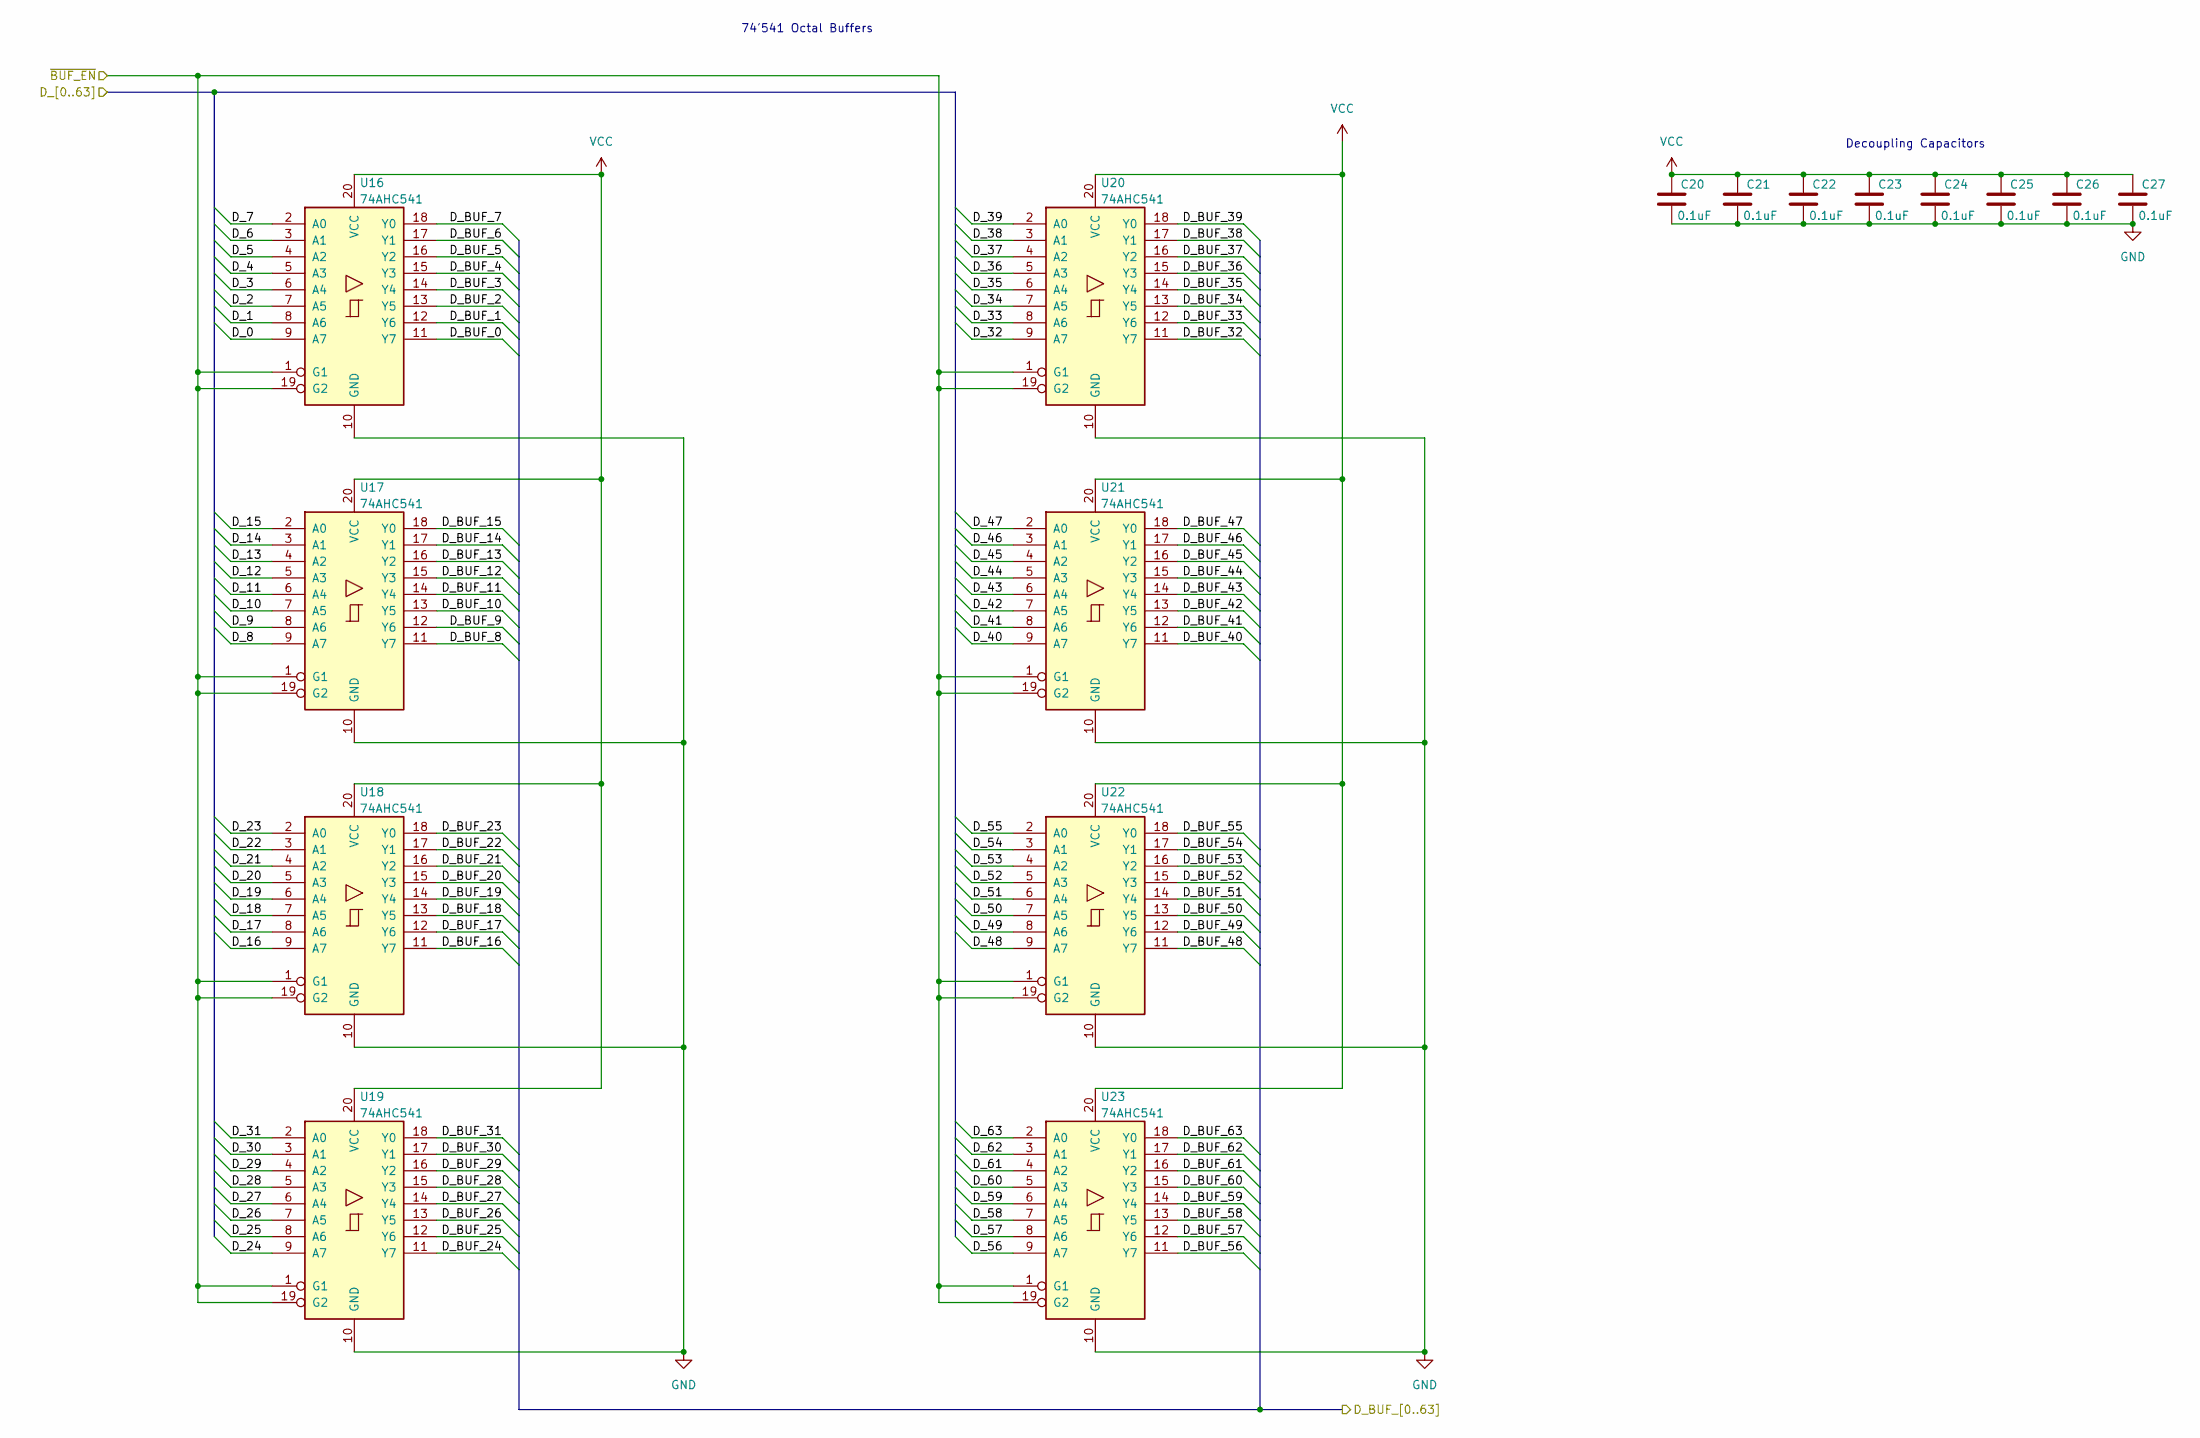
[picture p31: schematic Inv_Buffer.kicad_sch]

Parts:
C20, C21, C22, C23, C24, C25, C26, C27: 0.1uF; C_1206_3216Metric
U16, U17, U18, U19, U20, U21, U22, U23: 74AHC541; TSSOP-20_4.4x6.5mm_P0.65mm

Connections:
/REG_OUT_X_0: U16.11 (Y7); also elsewhere on the board
/REG_OUT_X_1: U16.12 (Y6); also elsewhere on the board
/REG_OUT_X_2: U16.13 (Y5); also elsewhere on the board
/REG_OUT_X_3: U16.14 (Y4); also elsewhere on the board
/REG_OUT_X_4: U16.15 (Y3); also elsewhere on the board
/REG_OUT_X_5: U16.16 (Y2); also elsewhere on the board
/REG_OUT_X_6: U16.17 (Y1); also elsewhere on the board
/REG_OUT_X_7: U16.18 (Y0); also elsewhere on the board
/REG_OUT_X_8: U17.11 (Y7); also elsewhere on the board
/REG_OUT_X_9: U17.12 (Y6); also elsewhere on the board
/REG_OUT_X_10: U17.13 (Y5); also elsewhere on the board
/REG_OUT_X_11: U17.14 (Y4); also elsewhere on the board
/REG_OUT_X_12: U17.15 (Y3); also elsewhere on the board
/REG_OUT_X_13: U17.16 (Y2); also elsewhere on the board
/REG_OUT_X_14: U17.17 (Y1); also elsewhere on the board
/REG_OUT_X_15: U17.18 (Y0); also elsewhere on the board
/REG_OUT_X_16: U18.11 (Y7); also elsewhere on the board
/REG_OUT_X_17: U18.12 (Y6); also elsewhere on the board
/REG_OUT_X_18: U18.13 (Y5); also elsewhere on the board
/REG_OUT_X_19: U18.14 (Y4); also elsewhere on the board
/REG_OUT_X_20: U18.15 (Y3); also elsewhere on the board
/REG_OUT_X_21: U18.16 (Y2); also elsewhere on the board
/REG_OUT_X_22: U18.17 (Y1); also elsewhere on the board
/REG_OUT_X_23: U18.18 (Y0); also elsewhere on the board
/REG_OUT_X_24: U19.11 (Y7); also elsewhere on the board
/REG_OUT_X_25: U19.12 (Y6); also elsewhere on the board
/REG_OUT_X_26: U19.13 (Y5); also elsewhere on the board
/REG_OUT_X_27: U19.14 (Y4); also elsewhere on the board
/REG_OUT_X_28: U19.15 (Y3); also elsewhere on the board
/REG_OUT_X_29: U19.16 (Y2); also elsewhere on the board
/REG_OUT_X_30: U19.17 (Y1); also elsewhere on the board
/REG_OUT_X_31: U19.18 (Y0); also elsewhere on the board
/REG_OUT_X_32: U20.11 (Y7); also elsewhere on the board
/REG_OUT_X_33: U20.12 (Y6); also elsewhere on the board
/REG_OUT_X_34: U20.13 (Y5); also elsewhere on the board
/REG_OUT_X_35: U20.14 (Y4); also elsewhere on the board
/REG_OUT_X_36: U20.15 (Y3); also elsewhere on the board
/REG_OUT_X_37: U20.16 (Y2); also elsewhere on the board
/REG_OUT_X_38: U20.17 (Y1); also elsewhere on the board
/REG_OUT_X_39: U20.18 (Y0); also elsewhere on the board
/REG_OUT_X_40: U21.11 (Y7); also elsewhere on the board
/REG_OUT_X_41: U21.12 (Y6); also elsewhere on the board
/REG_OUT_X_42: U21.13 (Y5); also elsewhere on the board
/REG_OUT_X_43: U21.14 (Y4); also elsewhere on the board
/REG_OUT_X_44: U21.15 (Y3); also elsewhere on the board
/REG_OUT_X_45: U21.16 (Y2); also elsewhere on the board
/REG_OUT_X_46: U21.17 (Y1); also elsewhere on the board
/REG_OUT_X_47: U21.18 (Y0); also elsewhere on the board
/REG_OUT_X_48: U22.11 (Y7); also elsewhere on the board
/REG_OUT_X_49: U22.12 (Y6); also elsewhere on the board
/REG_OUT_X_50: U22.13 (Y5); also elsewhere on the board
/REG_OUT_X_51: U22.14 (Y4); also elsewhere on the board
/REG_OUT_X_52: U22.15 (Y3); also elsewhere on the board
/REG_OUT_X_53: U22.16 (Y2); also elsewhere on the board
/REG_OUT_X_54: U22.17 (Y1); also elsewhere on the board
/REG_OUT_X_55: U22.18 (Y0); also elsewhere on the board
/REG_OUT_X_56: U23.11 (Y7); also elsewhere on the board
/REG_OUT_X_57: U23.12 (Y6); also elsewhere on the board
/REG_OUT_X_58: U23.13 (Y5); also elsewhere on the board
/REG_OUT_X_59: U23.14 (Y4); also elsewhere on the board
/REG_OUT_X_60: U23.15 (Y3); also elsewhere on the board
/REG_OUT_X_61: U23.16 (Y2); also elsewhere on the board
/REG_OUT_X_62: U23.17 (Y1); also elsewhere on the board
/REG_OUT_X_63: U23.18 (Y0); also elsewhere on the board
/Register_RAM_Bank X/Data_0: U16.9 (A7); also elsewhere on the board
/Register_RAM_Bank X/Data_1: U16.8 (A6); also elsewhere on the board
/Register_RAM_Bank X/Data_2: U16.7 (A5); also elsewhere on the board
/Register_RAM_Bank X/Data_3: U16.6 (A4); also elsewhere on the board
/Register_RAM_Bank X/Data_4: U16.5 (A3); also elsewhere on the board
/Register_RAM_Bank X/Data_5: U16.4 (A2); also elsewhere on the board
/Register_RAM_Bank X/Data_6: U16.3 (A1); also elsewhere on the board
/Register_RAM_Bank X/Data_7: U16.2 (A0); also elsewhere on the board
/Register_RAM_Bank X/Data_8: U17.9 (A7); also elsewhere on the board
/Register_RAM_Bank X/Data_9: U17.8 (A6); also elsewhere on the board
/Register_RAM_Bank X/Data_10: U17.7 (A5); also elsewhere on the board
/Register_RAM_Bank X/Data_11: U17.6 (A4); also elsewhere on the board
/Register_RAM_Bank X/Data_12: U17.5 (A3); also elsewhere on the board
/Register_RAM_Bank X/Data_13: U17.4 (A2); also elsewhere on the board
/Register_RAM_Bank X/Data_14: U17.3 (A1); also elsewhere on the board
/Register_RAM_Bank X/Data_15: U17.2 (A0); also elsewhere on the board
/Register_RAM_Bank X/Data_16: U18.9 (A7); also elsewhere on the board
/Register_RAM_Bank X/Data_17: U18.8 (A6); also elsewhere on the board
/Register_RAM_Bank X/Data_18: U18.7 (A5); also elsewhere on the board
/Register_RAM_Bank X/Data_19: U18.6 (A4); also elsewhere on the board
/Register_RAM_Bank X/Data_20: U18.5 (A3); also elsewhere on the board
/Register_RAM_Bank X/Data_21: U18.4 (A2); also elsewhere on the board
/Register_RAM_Bank X/Data_22: U18.3 (A1); also elsewhere on the board
/Register_RAM_Bank X/Data_23: U18.2 (A0); also elsewhere on the board
/Register_RAM_Bank X/Data_24: U19.9 (A7); also elsewhere on the board
/Register_RAM_Bank X/Data_25: U19.8 (A6); also elsewhere on the board
/Register_RAM_Bank X/Data_26: U19.7 (A5); also elsewhere on the board
/Register_RAM_Bank X/Data_27: U19.6 (A4); also elsewhere on the board
/Register_RAM_Bank X/Data_28: U19.5 (A3); also elsewhere on the board
/Register_RAM_Bank X/Data_29: U19.4 (A2); also elsewhere on the board
/Register_RAM_Bank X/Data_30: U19.3 (A1); also elsewhere on the board
/Register_RAM_Bank X/Data_31: U19.2 (A0); also elsewhere on the board
/Register_RAM_Bank X/Data_32: U20.9 (A7); also elsewhere on the board
/Register_RAM_Bank X/Data_33: U20.8 (A6); also elsewhere on the board
/Register_RAM_Bank X/Data_34: U20.7 (A5); also elsewhere on the board
/Register_RAM_Bank X/Data_35: U20.6 (A4); also elsewhere on the board
/Register_RAM_Bank X/Data_36: U20.5 (A3); also elsewhere on the board
/Register_RAM_Bank X/Data_37: U20.4 (A2); also elsewhere on the board
/Register_RAM_Bank X/Data_38: U20.3 (A1); also elsewhere on the board
/Register_RAM_Bank X/Data_39: U20.2 (A0); also elsewhere on the board
/Register_RAM_Bank X/Data_40: U21.9 (A7); also elsewhere on the board
/Register_RAM_Bank X/Data_41: U21.8 (A6); also elsewhere on the board
/Register_RAM_Bank X/Data_42: U21.7 (A5); also elsewhere on the board
/Register_RAM_Bank X/Data_43: U21.6 (A4); also elsewhere on the board
/Register_RAM_Bank X/Data_44: U21.5 (A3); also elsewhere on the board
/Register_RAM_Bank X/Data_45: U21.4 (A2); also elsewhere on the board
/Register_RAM_Bank X/Data_46: U21.3 (A1); also elsewhere on the board
/Register_RAM_Bank X/Data_47: U21.2 (A0); also elsewhere on the board
/Register_RAM_Bank X/Data_48: U22.9 (A7); also elsewhere on the board
/Register_RAM_Bank X/Data_49: U22.8 (A6); also elsewhere on the board
/Register_RAM_Bank X/Data_50: U22.7 (A5); also elsewhere on the board
/Register_RAM_Bank X/Data_51: U22.6 (A4); also elsewhere on the board
/Register_RAM_Bank X/Data_52: U22.5 (A3); also elsewhere on the board
/Register_RAM_Bank X/Data_53: U22.4 (A2); also elsewhere on the board
/Register_RAM_Bank X/Data_54: U22.3 (A1); also elsewhere on the board
/Register_RAM_Bank X/Data_55: U22.2 (A0); also elsewhere on the board
/Register_RAM_Bank X/Data_56: U23.9 (A7); also elsewhere on the board
/Register_RAM_Bank X/Data_57: U23.8 (A6); also elsewhere on the board
/Register_RAM_Bank X/Data_58: U23.7 (A5); also elsewhere on the board
/Register_RAM_Bank X/Data_59: U23.6 (A4); also elsewhere on the board
/Register_RAM_Bank X/Data_60: U23.5 (A3); also elsewhere on the board
/Register_RAM_Bank X/Data_61: U23.4 (A2); also elsewhere on the board
/Register_RAM_Bank X/Data_62: U23.3 (A1); also elsewhere on the board
/Register_RAM_Bank X/Data_63: U23.2 (A0); also elsewhere on the board
/~BUF_EN_X: U16.1 (G1), U16.19 (G2), U17.1 (G1), U17.19 (G2), U18.1 (G1), U18.19 (G2), U19.1 (G1), U19.19 (G2), U20.1 (G1), U20.19 (G2), U21.1 (G1), U21.19 (G2), U22.1 (G1), U22.19 (G2), U23.1 (G1), U23.19 (G2); also elsewhere on the board
GND: C20.2, C21.2, C22.2, C23.2, C24.2, C25.2, C26.2, C27.2, U16.10 (GND), U17.10 (GND), U18.10 (GND), U19.10 (GND), U20.10 (GND), U21.10 (GND), U22.10 (GND), U23.10 (GND); also elsewhere on the board
VCC: C20.1, C21.1, C22.1, C23.1, C24.1, C25.1, C26.1, C27.1, U16.20 (VCC), U17.20 (VCC), U18.20 (VCC), U19.20 (VCC), U20.20 (VCC), U21.20 (VCC), U22.20 (VCC), U23.20 (VCC); also elsewhere on the board

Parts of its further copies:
C28, C29, C30, C31, C32, C33, C34, C35: 0.1uF; C_1206_3216Metric
U24, U25, U26, U27, U28, U29, U30, U31: 74AHC541; TSSOP-20_4.4x6.5mm_P0.65mm
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

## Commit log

2026-05-23 Updated RegFile diagrams + timing
    [RegOutBuf.kicad_sch, Reg_RAM.kicad_sch, RegisterFile.kicad_sch]
2026-06-10 BIG UPDATE: Schematics, PCB & updated writeup for register
    [BOM.csv, CardTester.kicad_pcb, CardTester.kicad_sch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]
2026-06-19 Card Tester PCB made + Register file updates
    [ADR-Decode.kicad_sch, BOM.ods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]
